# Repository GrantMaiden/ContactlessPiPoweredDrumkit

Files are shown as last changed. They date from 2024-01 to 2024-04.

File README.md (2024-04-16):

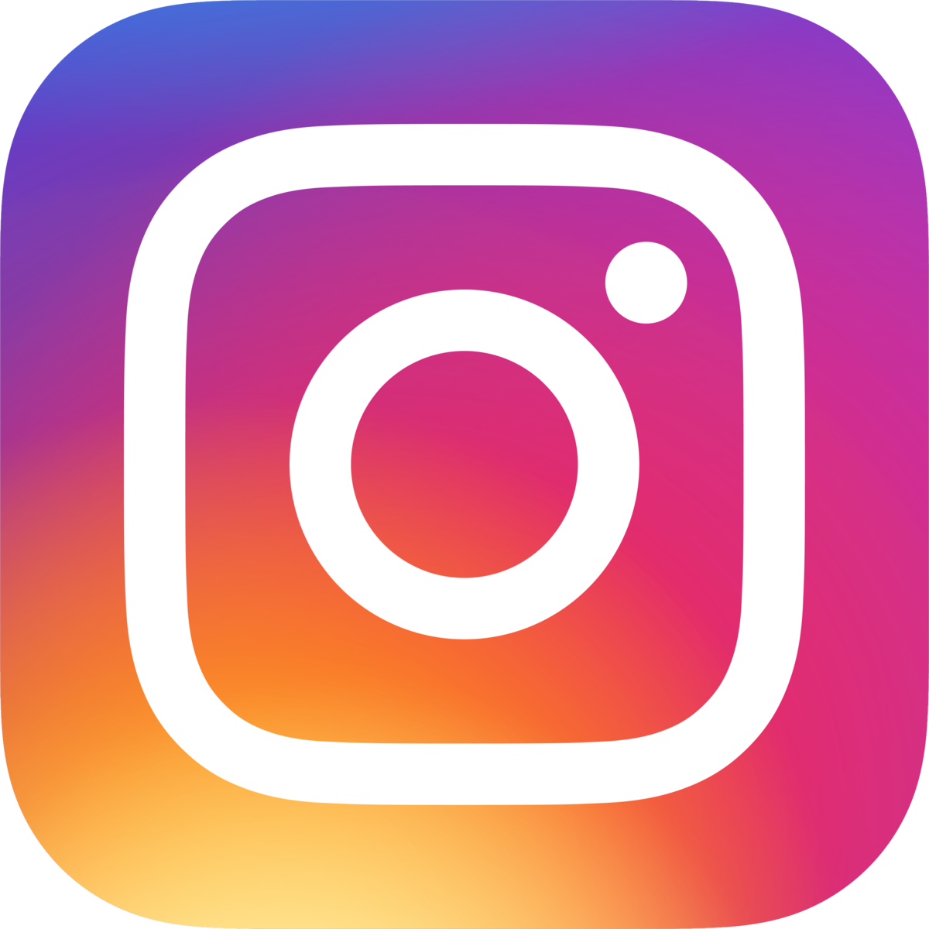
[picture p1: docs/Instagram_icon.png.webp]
# [](https://www.instagram.com/byte.thebeat/) (byte)this.beat  
Welcome to the github landing page for the first prototype of the **(byte)this.beat** drumkit!

(byte)this.beat is an innovative, contactless, raspberry pi-powered drumkit being developed for  Real Time Embedded Programming (ENG5220) at the University of Glasgow.  The contactless drumkit aims to be a simple, easy-to-use interface that accommodates entry level users---being a introductory device to jam out on---as well as a device for professional musicians, conforming to sub 20ms latency requirements and high quality, 48000khz drum samples.

Please download the latest release to access the most recent stable version of the source code. Keep in mind that hardware is required to run this project!

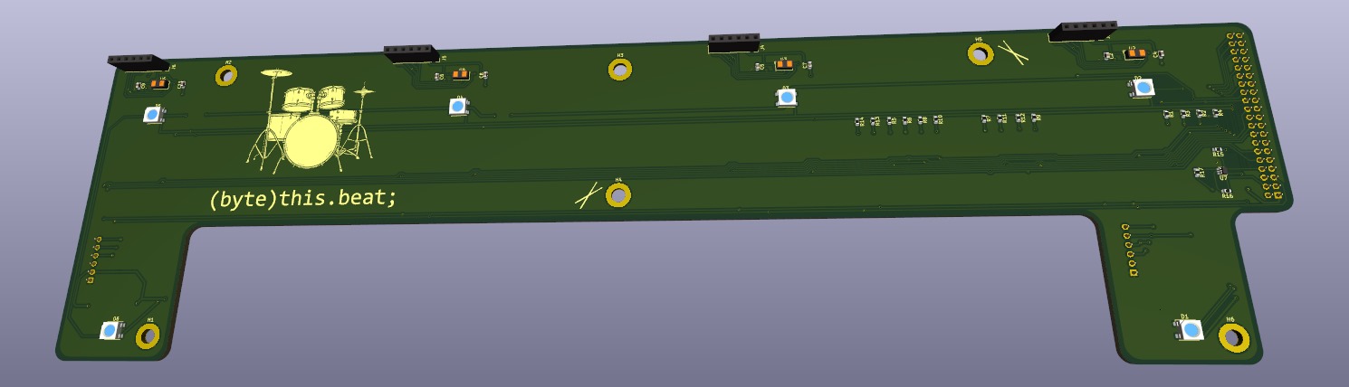
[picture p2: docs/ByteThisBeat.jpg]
(byte)this.beat; PCB


## So what's the tempo?

* The challenge set for this course was to develop any real time embedded project, using a Raspberry Pi 3 and a £45 budget.  
* Selecting an appropriate sensor that can be used in a real-time system that is affordable, has a high sample rate, and great data resolution was challenging. After a thorough amount of market research, the [VL53L4CD](https://www.st.com/en/imaging-and-photonics-solutions/vl53l4cd.html) ranging sensor was selected as the most suitable ic for our project. Turning them into "invisible" drum modules so that you can jam out in thin air seemed a perfect task!  
* The distance values measured by the sensors every 10ms are used to calculate the velocity of any objects directly above the sensors. A detection algorithm is derived by being a combination of when the velocity changes direction, and what the previous 80ms of velocity was measured as. Thus, it is possible to use the sensor data to not only detect when a drum hit has been detected, but also at what intensity!

## Team Collaboration and Project Management

Project management was done by utilising a teams channel for collaboration. At the start of our group project, keeping in mind an agile team development environment, a Gantt chart was created in excel and hosted on our teams channel. Our team had two meetings each week throughout the semester; the first of which was primarily for project planning and updates, and the second meeting was for development and one-on-one problem solving, if necessary. Github issues were utilised as a means to give feedback as our project development continued. All Project Discussions, meeting notes, and development feasibility studies can be found at our [sharepoint](https://gla.sharepoint.com/:o:/s/ENG5228RTEP/Er4JzmCRMUZCnUjhNUSQIA8BrX5IVSQI6c456dHyLfZf0w?e=HDqj4z).  
This link is accessible by anyone with a University of Glasgow account. 
GitHub issues were used as a way to track the development of the project. The issues can be viewed from the header of this page, above the directory browser.

## Project Setup and Initialisation
### Hardware Requirements
* Assembled (byte)this.beat board
* Raspberry Pi updated with latest Raspbian image
* Speaker attached to Audio Jack
### Software Setup
* Complete project setup instructions located in the [Embedded Directory](https://github.com/GrantMaiden/ContactlessPiPoweredDrumkit/tree/main/embedded) on your local raspberry pi
* Download the latest release of the firmware, and compile the source code in the embedded directory by following the [cmake build instructions](https://github.com/GrantMaiden/ContactlessPiPoweredDrumkit/blob/main/embedded/cmake_build_instructions.txt)

After running the program, an intro LED pattern will play for roughly 5 seconds, which when complete the drumkit will be able to receive ranging data. To enable sound, swipe across all 4 upwards facing sensors. The same swipe can be used to disable sound if playing needs to be paused.

## Documentation
Our code has been updated with comments that are compatible with DoxyGen, which is a great tool to generate large amounts of sufficiently segmented documentation. To view the generated documentation, first grab the latest release, then open the index.html page located in the [embedded/docs](https://github.com/GrantMaiden/ContactlessPiPoweredDrumkit/tree/main/embedded/docs) directory. In addition to the DoxyGen resource, the source code is litered with verbose explanaitons and function headers, so keep that in mind if you are modifying the source.

## Hardware Development
In order to minimise costs associated with the (byte)this.beat project, a custom Hardware design was developed. After a cost analysis completed at the beginning of the project timeline, it was concluded that designing a custom solution, rather than purchasing independent breakout boards, would allow our contactless drumkit to have a larger scope. Thus accommodating more sensors/functionality by more easily staying within our £45 budget. The discussions pertaining to analysis and cost can be seen at our [onenote](https://gla.sharepoint.com/:o:/s/ENG5228RTEP/Er4JzmCRMUZCnUjhNUSQIA8BrX5IVSQI6c456dHyLfZf0w?e=HDqj4z).  

As always, the goal with any project is to learn as much as possible while designing, thus we decided to use this opportunity to get familiar with KiCad for schematic entry. A prototype design was completed early into the semester, giving our team plenty of tolerance on receiving the fabricated boards. The fabricated board can also easily accommodate many more traces and connections than a breadboard solution could, allowing for the design scope to increase. The schematic can be seen [here](https://github.com/GrantMaiden/ContactlessPiPoweredDrumkit/blob/main/hardware/ContactlessPiPoweredDrumkit/Schematic/byteThisBeatREVA.pdf).

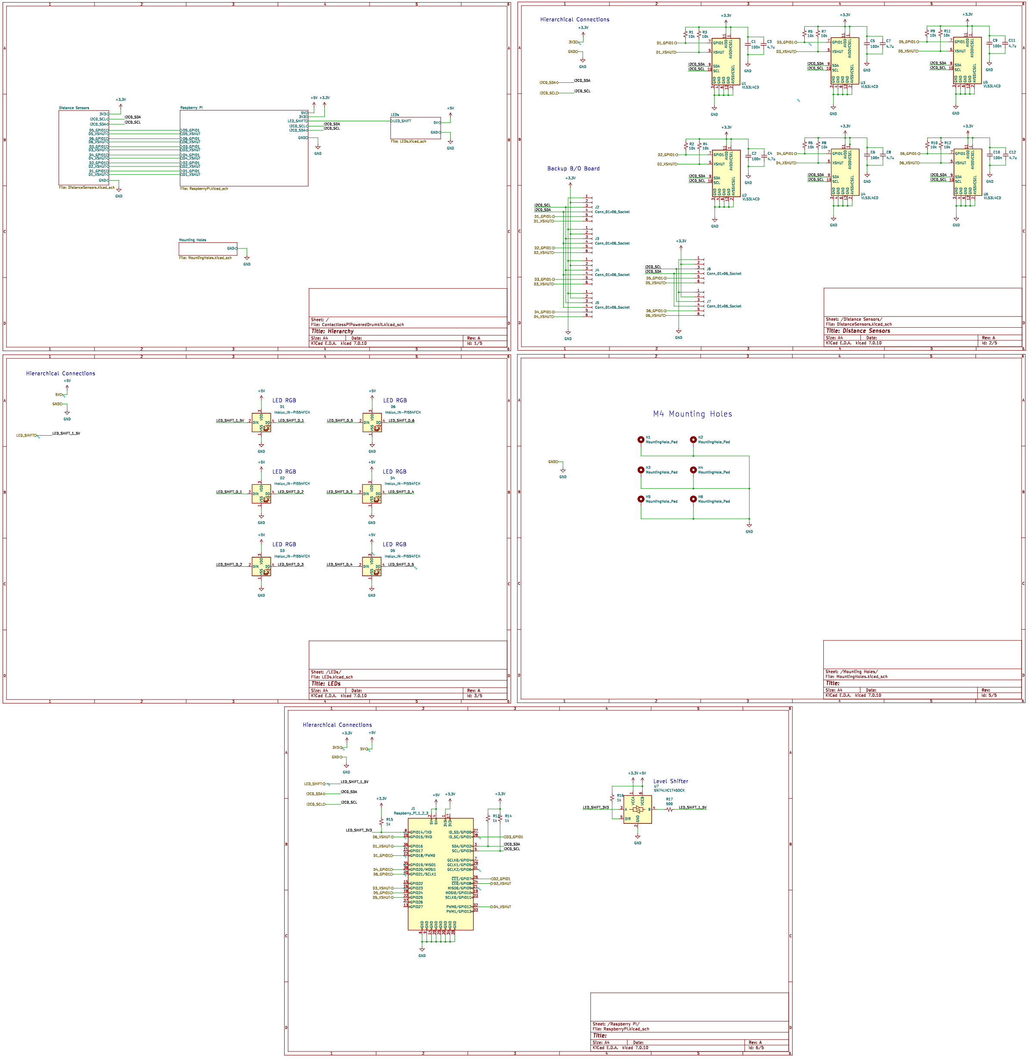
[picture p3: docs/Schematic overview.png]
(byte)this.beat; Schematic overview


The drumkit had a portion of the budget left over after the primary sensor selection, so we decided to use the rest of the funds on purchasing LEDs that would aid in giving the drummer feedback during hit detection. As seen in the block diagram below, the raspberry pi communicates with 6 distance sensors, outputs to the on-board audio jack, and outputs serialised data to the LEDs.

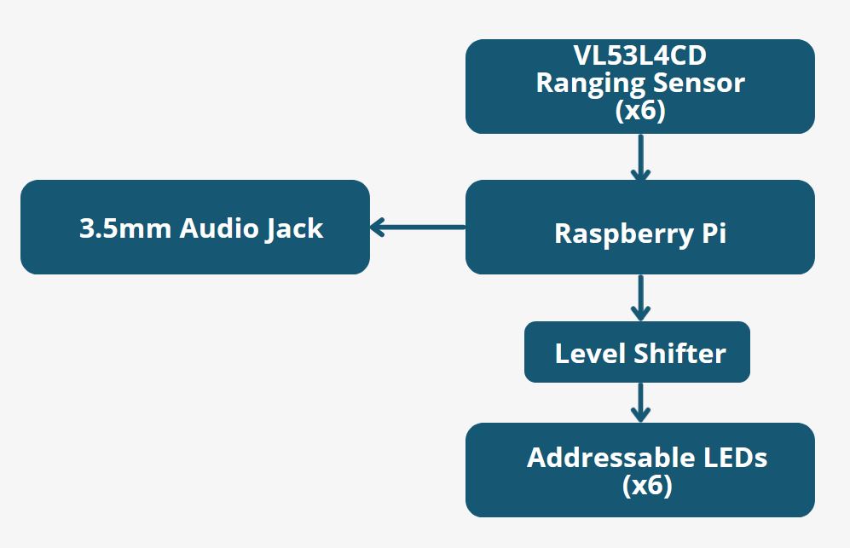
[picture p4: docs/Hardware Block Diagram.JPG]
(byte)this.beat; Hardware Diagram


The LEDs that were chosen are the same type of addressable LEDs that can be found on LED strips. They are affordable, and plenty of options are available. A few design challenges had to be faced regarding the decision to use these leds, however. The LEDs use 5V logic for communication, so a level shifter had to be added to translate the rpi's 3.3V logic to 5V. Secondly, the LEDs use a strict 800khz transmission rate for each bit. Serialised bits need to be given to the LEDs over a single trace, essentially the LEDs act as specialised shift registers, only forwarding their to each succeeding LED after 24bits of data has been received. The data sheet for the LEDs, along with more information regarding the protocol, can be found [here](https://github.com/GrantMaiden/ContactlessPiPoweredDrumkit/blob/main/docs/datasheets/IN-PI55TAT(X)R(X)G(X)B_v1.5.pdf). 

Due to the strict timing requirement of the LEDs, we had to use a hardware bus to send the LED bitstream, given that bitbanging at 800khz would not be consistent, and would cause too much overhead. Initially, the PCB was designed to use the uart interface for driving the LEDs, but after getting the boards in-hand and beginning development, it was found that the uart bus could not support the baudrate required (800khz*(8bits + 1stopbit) = 7.2mhz), a hardware rework was completed to change the LED control over to the SPI bus, which could accommodate the necessary frequency. The rework instructions can be found in the hardware directory.

For more information regarding the manufacturing of the (byte)this.beat board, please refer to the [hardware directory](https://github.com/GrantMaiden/ContactlessPiPoweredDrumkit/tree/main/hardware/ContactlessPiPoweredDrumkit), which includes a BOM for manufacture. The board file can also be seen in this directory. Layout was completed using KiCad, with a two-layer PCB being designed. After meeting with the EE technicians at the University of Glasgow, we found that they were unable to fabricate our design, so an overseas location was chosen for fab and assembly.

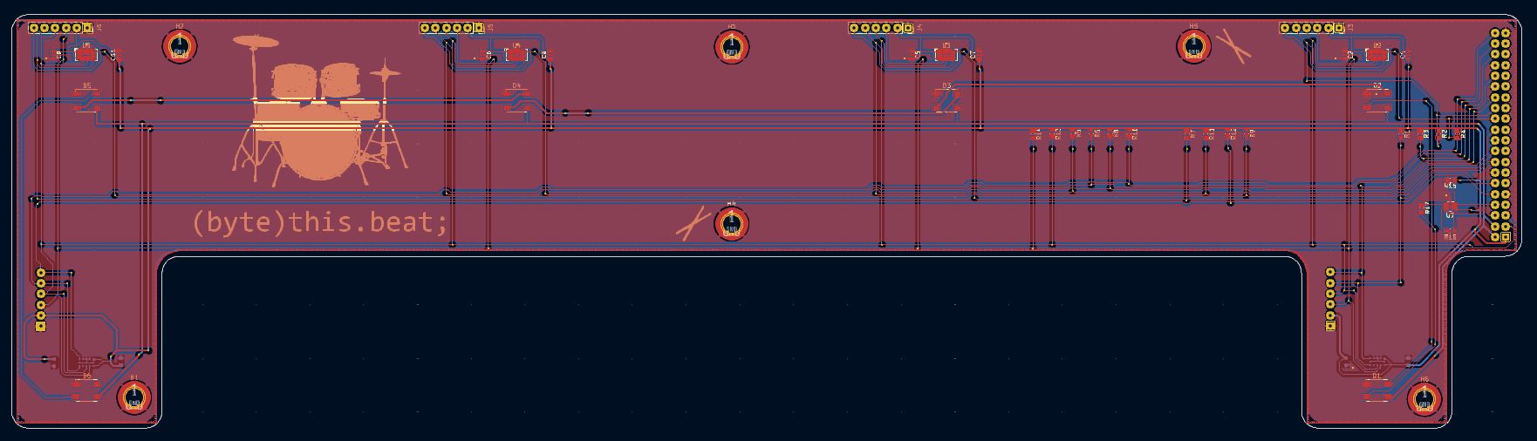
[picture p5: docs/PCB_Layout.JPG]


## Software 

The embedded code, being the main focus of our project, was approached with several goals for implementation:
* Real Time Coding - code is event driven and utilises hardware inputs or timers to strictly control code behavior
* Event Handling - real time events are coded with clearly defined callbacks and other async operations
* Class Encapsulation - code is written within separate classes that have clear responsibilities, obey the Liskov Substitution Principle, and are segregated, with dependency inversion
* Documentation - Verbose function headers and additional documentation generated with Doxygen to supply the user information
* Header File Constants - many constants included to aid in program control and easily modify behavior

Below, please see a diagram regarding how the major classes interact with each other within our application.

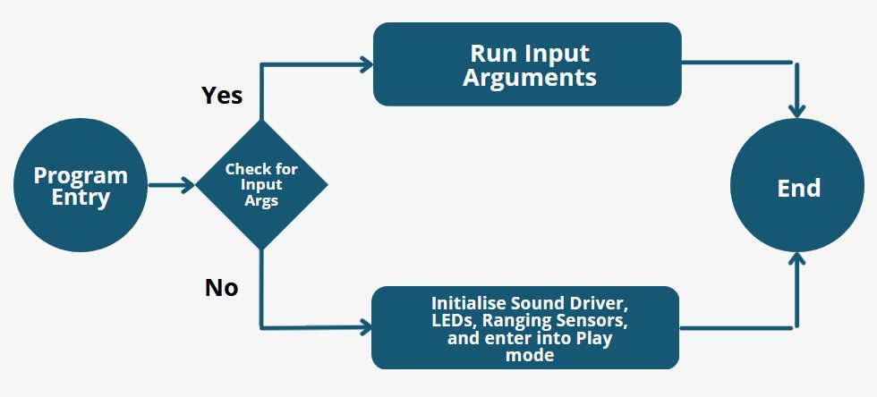
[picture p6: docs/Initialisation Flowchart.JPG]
(byte)this.beat; Init Flowchart


The controller class is initialised by the Main function, which on program boot creates the initial controller class. When the controller class is initialised, it will bring up the other portions of the program, which configures any necessary peripherals, and performs the bring-up procedure of the ranging sensors. This initialisation also configures asynchronous processes that use callback processes to create real-time operation of our system. The LED class uses a timer, and updates all LEDs every 2.5ms. The VL53L4CD class leaves an abstract function that is defined within the Controller class. When a hardware interrupt occurs, the VL53L4CD class will enact a callback via the virtual function.

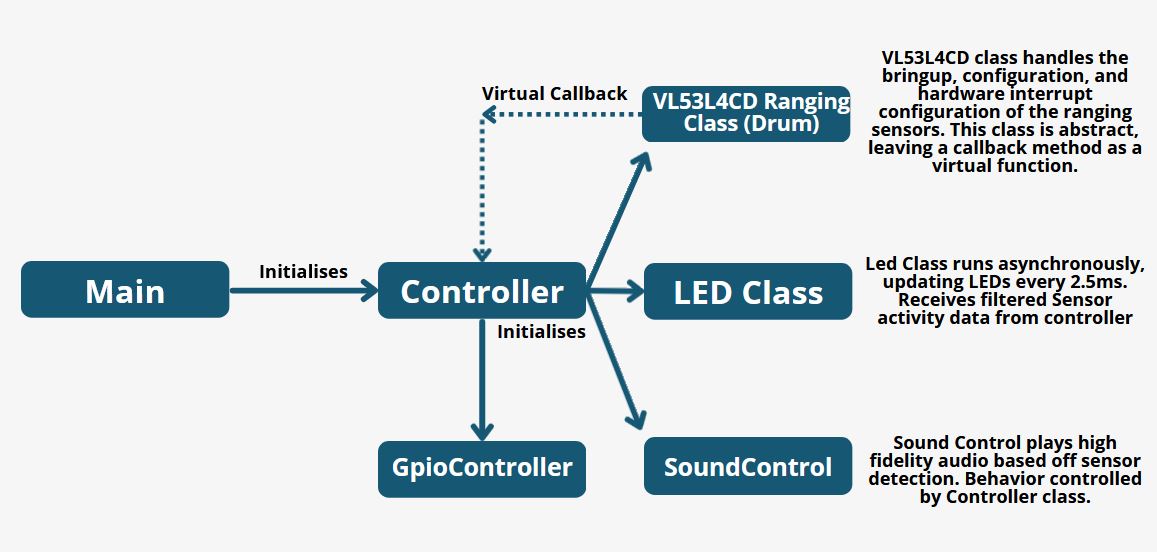
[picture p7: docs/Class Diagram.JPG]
(byte)this.beat; class diagram


### Bus Protocols
I2C was used as the communication protocol for each sensor. All sensors share the same bus, but are initialised with the same address. An initialization procedure had to be crafted to disable all sensors on program start, then bring-up each sensor sequentially, reprogramming the I2C bus address for the sensor, and configuring it for our high sample rate requirements.

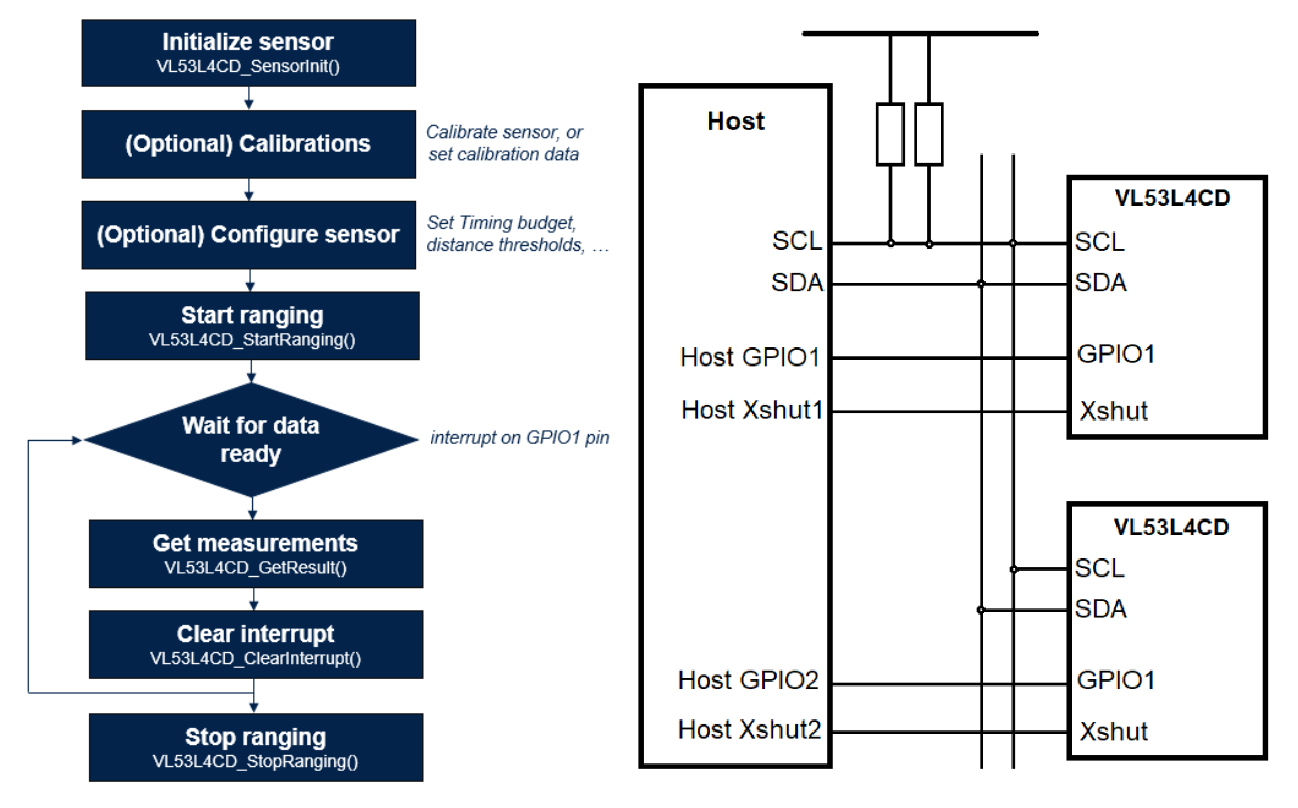
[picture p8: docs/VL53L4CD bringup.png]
(byte)this.beat; ranging bringup

Note: From VL53L4CD Datasheet

The SPI protocol uses custom bitshift operations to drive 6*24bits of RGB data to our addressable LEDs. The GPIO controller class handles the sending of the SPI data.
### Digital Signal Processing
The outgoing data from the ranging sensors is inherently quite noisy, and lots of artifacts exist especially once you begin to interact with them. In order to have reliable air drumming behavior, it was necessary to come up with multiple algorithms that filter the data in various ways. Keeping in mind the real-time requirements of our system, a lengthy finite reponse filter could not be used due to adding to much delay to the total system overhead. To minimise response delays, filtering was controlled using the following methods, configurable inside the controller.h header file:
* HIT_DETECT_NOISE_CHECKING   -- Enable Noise Checking/Filtering
* HIT_DETECT_NUM_SAMPLES_MIN   -- Minimum number of samples necessary for detection
* DRUM_INTERVAL_TIMEOUT_MS  -- Timeout between detection events. Caps maximum drum rate per drum
* HIT_DETECT_INSTANEOUS_VELOCITY_LIMIT  --  Velocity artificats occur frequently. If one of the detection samples' velocity is above this limit, then the drum detect is cancelled
* HIT_DETECT_AVG_VELOCITY_CEILING -- An average velocity is taken of all previous detection samples. If this average is above this threshold, then the drum detect event is negated
* HIT_DETECT_MIN_SEQUENTIAL_VELOCITY_SAMPLES  --  Minimum number of previous velocity samples below the HIT_DETECT_AVG_VELOCITY_CEILING required for a hit detect

Whenever a sensor receives data, via a virtual callback the data is sent to the controller class for processing. The controller class will take the most recent data, store the last 16 distance values into an array, and calculate the most recent velocity by taking the last sample minus the most recent sample. When the velocity calculation occurs, the velocity data is ran through a simple running average filter, via the calculation: averageVelocity = averageVelocity + (recentVelocity - averageVelocity) / VELOCITY_FACTOR_AVG. The VELOCITY_FACTOR_AVG is a constant modifiable in the controller.h header file.
A running average filter allows for a single sample overhead during averaging, and converges completely to the real average within the VELOCITY_FACTOR_AVERAGE number of samples.
As a brief example of the challenges seen during data collection and processing, refer to the below image. This image shows the Average Velocity, Recent Velocity, and current distance of each sample, in 10ms increments. 
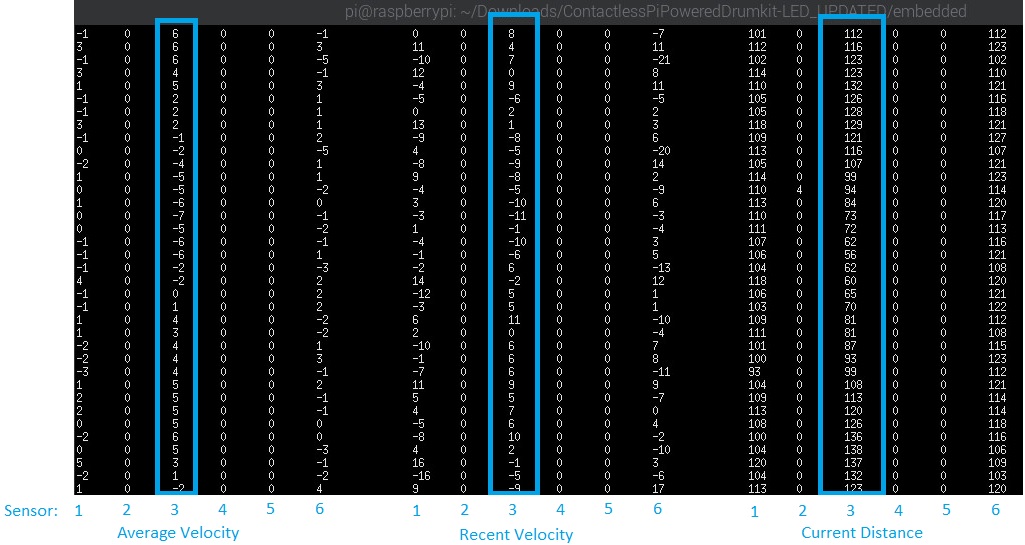
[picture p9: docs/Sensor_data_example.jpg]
(byte)this.beat; sensor data example
 
## Phone Application
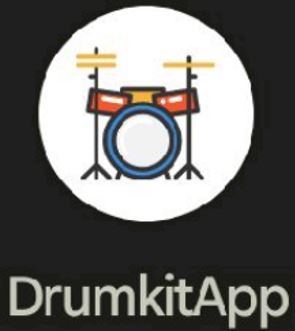
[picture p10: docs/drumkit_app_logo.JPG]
(byte)this.beat; drumkit logo
 
Originally, ambitious project planning had our team plan on utilising a phone application to interact with the physical drumkit, using bluetooth to handshake, modify drumkit selections, and use the phone as a speaker. We did have the opportunity to develop a prototype phone app early on in the semester. However, due to team bandwidth limitations, we were unable to see the bluetooth connectivity and phone app through to completion. 
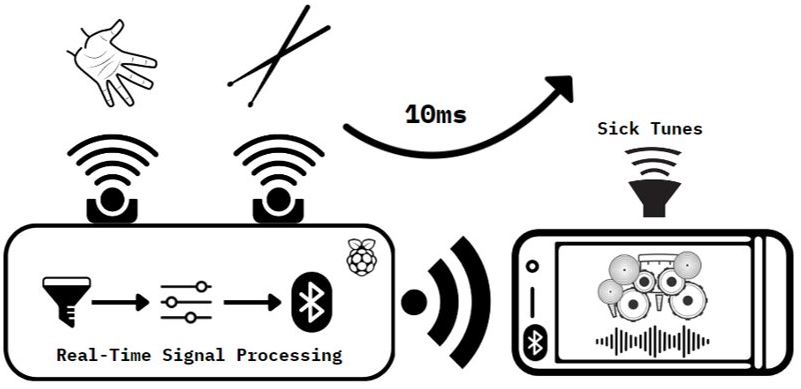
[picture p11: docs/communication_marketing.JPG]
(byte)this.beat; communication
 
It should be noted that we also discovered though substantial literature review that bluetooth bandwidth is relatively inconsistent, and even the bluetooth low latency has minimum latency intervals of about 70ms. We concluded that using bluetooth as a realtime interface would be a nightmare, and it would be best to at least keep to a physical connection regarding the sound output. We still think that a phone app would be a great way to interact with the drumkit settings, volume, etc., any we plan to continue to consider implementing one in the future.
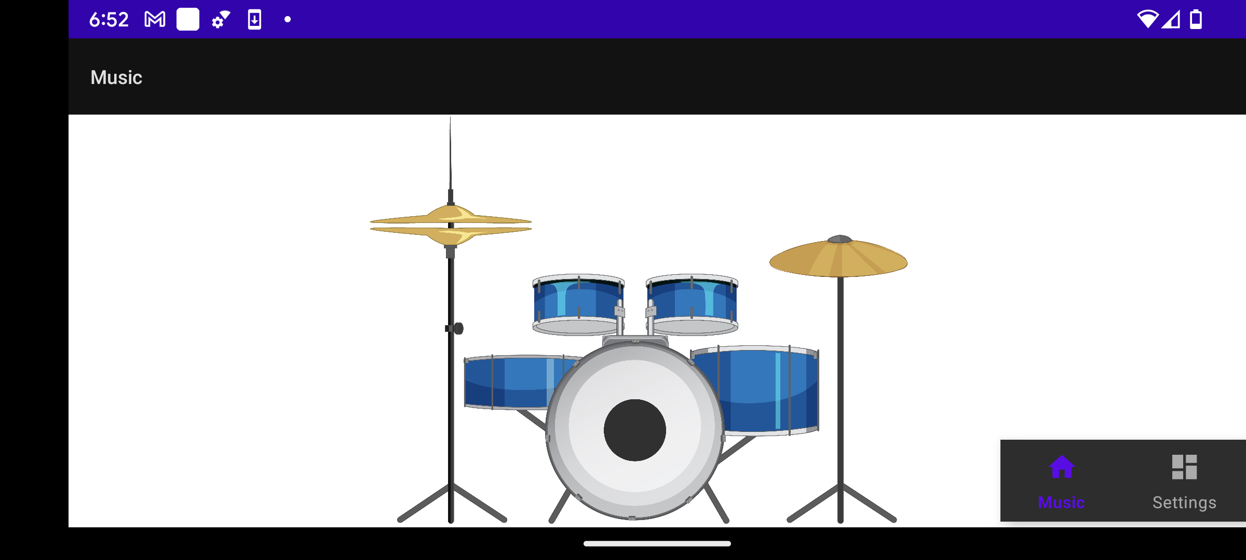
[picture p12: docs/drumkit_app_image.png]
(byte)this.beat; app image
 

## Unit Testing Framework
A custom unit testing framework was designed to accommodate the needs of our team collaborative efforts. When the application launches, the first code that is ran is a search to see if any input arguments are supplied. The input arguments are the inputs to our custom unit testing framework; it was deemed necessary to have a more advanced testing methodology in place as the many different blocks of our project required separate entry points depending on use case. In example, a unit test was designed to benchmark and initialise the LEDs. After the unit test was completed, the functions designed during test were integrated into the rest of the project. This design methodology was enacted in all facets of our software development. 

A list of all unit tests, their associated functions, and more specific usage instructions can be found [here](https://github.com/GrantMaiden/ContactlessPiPoweredDrumkit/blob/main/embedded/unit_tests.txt).

## Challenges and Future Improvements
Development using the raspberry pi proved to be full of challenges. Some of our team has had extensive experience with varying microcontrollers as a professional embedded engineer, and they concluded that the lack of substantial official documentation greatly complicated development. 
Here is a list of (just a few!) of the notable challenges that arose during development:
* Audio permissions -- The pigpio library requires sudo permissions, however the asla audio driver is not configured correctly to run under super user. The solution was challenging to discover, but is highlighted in the markup in our embedded directory.
* SPI bus frequency -- The embedded core clock used by the PI is not consistent. Our addressable LEDs requires fixed timing to work correctly, however the SPI clock is affected by other bus activity, USB traffic, and high load wifi connections. Essenstially, the LEDs will flicker or flash random colors when the SPI frequency deviates. As far as we know, there is no solution to this problem, but it shows that the raspberry pi is full of undocumented surprises, and is not capable of specific timing control under some circumstances.
* Some low level c libraries such as pigpio have functions to modify embedded bus behaviour, but really these values are controlled by the us and it is necessary to modify the /boot/firmware/config.txt to change things such as the I2C clock speed.
* The SPI cs gpio's can not be used as GPIO's during spi, even if SPI0 is being used, and SPI1 CS is trying to be configured as an input, even when all documentation says otherwise. This required a rework!

Some future improvements for the drumkit are planned for the next revision of the project.

* Move away from the high power, large raspberry pi to a smaller mcu. Originally one of the goals of our project was to make a device small and portable; a criteria that our device doesn't quite meet.
* Implement bluetooth communication that will interact with a peripheral phone app for control and feedback.
* Respin the board to correct hardware reworks required to accomodate SPI CS GPIO bottlenecking, and switching to the SPI from UART for LED control.
* Improve hit detection by exploring other filtering methods, and perhaps different sensors.

## Authors

* Grant Maiden  
* Peter O'Hanlon  
* Ethan Travers  
* Lucas Zehner

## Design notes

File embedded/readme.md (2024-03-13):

# Directory for Embedded development  
  
!!!IMPORTANT! PLEASE READ ENTIRETY OF THIS README BEFORE PROCEEDING WITH RUNNING PROJECT!!!  
  
## Important Documents  
  
For Cmake build instructions, refer to [cmake_build_instructions.txt]("./embedded/cmake_build_instructions.txt")  
For Unit Test Parameters, refer to [unit_tests.txt]("./embedded/unit_tests.txt")  
Before proceeding, make sure to complete build setup, otherwise compilation will not be successful.  
  
### Running Instructions:  
After building, preceed all program calls with _sudo_, as pigpio lib requires sudo access.  
  
## Project Setup  
  
Recommended Operating System for compilation: [Bookworm 12, v6.1](https://downloads.raspberrypi.com/raspios_full_armhf/images/raspios_full_armhf-2023-12-06/2023-12-05-raspios-bookworm-armhf-full.img.xz) (auto-download image)  
  
### Project is managed using codeblocks.  
To install codeblocks, run the following from console:  
```
sudo apt-get install codeblocks  
```  
### Enable I2C/SPI communication:  
Pi Grenade Bomb -> Preferences -> Raspberry Pi Configuration -> Interfaces -> I2C (Toggle)  
Pi Grenade Bomb -> Preferences -> Raspberry Pi Configuration -> Interfaces -> SPI (Toggle)  
  
### Edit Config.txt:  
```
sudo nano /boot/firmware/config.txt
``` 
Add Lines:  
```
core_freq=250  
core_freq_min=250  
dtparam=i2c_baudrate=400000  
```  
### Setup Audio by changing user default audio device:  
```
$sudo nano /usr/share/alsa/alsa.conf
```
Change lines:
```
defaults.pcm.card 1  
defaults.ctl.card 1  
```
### PiGPIO
[pigpio download](https://abyz.me.uk/rpi/pigpio/download.html)  
  
To close lingering pigpio processes:  
```
$cat /var/run/pigpio.pid  
$NumberReturned   
$sudo kill -9 NumberReturned
```
  
### Setup Codeblocks:  
Settings-> Compiler -> Linker Settings -> Other linker options -> add to field: -lpigpio -lrt -lpthread -lm -ldl -latomic  
  
### Add Tool Codeblocks:  
Tools -> Configure Tools -> Add -> Name field: Run as Sudo -> Executable Field: sudo $(TARGET_OUTPUT_FILE)   
**NOTE: MUST BUILD THEN TO RUN SELECT THIS TOOL FROM TOOL MENU**  
  
## Resources and Tools
  
Self Documenting Code Format: [DoxyGen](https://www.doxygen.nl/manual/docblocks.html)    
  
[Kernel Documentation](https://www.kernel.org/doc/Documentation/)  
  
Sys Libraries location:  
```
/usr/include/arm-linux-gnueabihf/sys
```

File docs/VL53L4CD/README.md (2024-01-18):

STM32 resources:

Linux driver:
https://www.st.com/en/embedded-software/stsw-img028.html

Product Page:
https://www.st.com/en/imaging-and-photonics-solutions/vl53l4cd.html

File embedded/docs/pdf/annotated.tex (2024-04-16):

\doxysubsection{Class List}
Here are the classes, structs, unions and interfaces with brief descriptions\+:\begin{DoxyCompactList}
\item\contentsline{section}{\mbox{\hyperlink{classController}{Controller}} }{\pageref{classController}}{}
\item\contentsline{section}{\mbox{\hyperlink{classCppThread}{Cpp\+Thread}} }{\pageref{classCppThread}}{}
\item\contentsline{section}{\mbox{\hyperlink{classCppTimer}{Cpp\+Timer}} }{\pageref{classCppTimer}}{}
\item\contentsline{section}{\mbox{\hyperlink{classGpioController}{Gpio\+Controller}} }{\pageref{classGpioController}}{}
\item\contentsline{section}{\mbox{\hyperlink{classLedControl}{Led\+Control}} }{\pageref{classLedControl}}{}
\item\contentsline{section}{\mbox{\hyperlink{classPlatformVL53l4CD}{Platform\+VL53l4\+CD}} \\*If the macro below is defined, the device will be programmed to run with I2C Fast Mode Plus (up to 1MHz). Otherwise, default max value is 400k\+Hz }{\pageref{classPlatformVL53l4CD}}{}
\item\contentsline{section}{\mbox{\hyperlink{structsensorHit}{sensor\+Hit}} }{\pageref{structsensorHit}}{}
\item\contentsline{section}{\mbox{\hyperlink{structsensorValues}{sensor\+Values}} }{\pageref{structsensorValues}}{}
\item\contentsline{section}{\mbox{\hyperlink{classSound}{Sound}} }{\pageref{classSound}}{}
\item\contentsline{section}{\mbox{\hyperlink{classVL53L4CD}{VL53\+L4\+CD}} }{\pageref{classVL53L4CD}}{}
\item\contentsline{section}{\mbox{\hyperlink{classVL53L4CD__API}{VL53\+L4\+CD\+\_\+\+API}} }{\pageref{classVL53L4CD__API}}{}
\item\contentsline{section}{\mbox{\hyperlink{structVL53L4CD__LinuxDev}{VL53\+L4\+CD\+\_\+\+Linux\+Dev}} }{\pageref{structVL53L4CD__LinuxDev}}{}
\item\contentsline{section}{\mbox{\hyperlink{structVL53L4CD__ResultsData__t}{VL53\+L4\+CD\+\_\+\+Results\+Data\+\_\+t}} \\*Packed reading results type }{\pageref{structVL53L4CD__ResultsData__t}}{}
\item\contentsline{section}{\mbox{\hyperlink{structVL53L4CD__Version__t}{VL53\+L4\+CD\+\_\+\+Version\+\_\+t}} \\*Defines Software Version }{\pageref{structVL53L4CD__Version__t}}{}
\end{DoxyCompactList}

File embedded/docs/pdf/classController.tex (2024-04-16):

\hypertarget{classController}{}\doxysubsection{Controller Class Reference}
\label{classController}\index{Controller@{Controller}}
Inheritance diagram for Controller\+:\begin{figure}[H]
\begin{center}
\leavevmode

\end{center}
\end{figure}
\doxysubsubsection*{Public Member Functions}
\begin{DoxyCompactItemize}
\item 
virtual void \mbox{\hyperlink{classController_af53bfa42e907627e5f39668e3d8acb5c}{distance\+Data\+Ready}} (\mbox{\hyperlink{structsensorValues}{sensor\+Values}} sens\+Vals, sensor\+ID sensor)
\item 
void \mbox{\hyperlink{classController_a28d5755bc8fed07cebd88f857f0f83df}{initialize}} ()
\item 
void \mbox{\hyperlink{classController_adddce8023c6beb72400ec1ead2629e66}{primary\+State\+Machine}} ()
\item 
void \mbox{\hyperlink{classController_a0676fa7d920a0984d3920bcf27401a0f}{update\+State}} (controller\+State new\+State)
\item 
void \mbox{\hyperlink{classController_a6a4dff110a9530bb905f0b7fab9bd819}{update\+Sensor\+Value}} (\mbox{\hyperlink{structsensorValues}{sensor\+Values}} sense\+Value, sensor\+ID id)
\end{DoxyCompactItemize}

\doxysubsubsection{Member Function Documentation}
\mbox{\Hypertarget{classController_af53bfa42e907627e5f39668e3d8acb5c}\label{classController_af53bfa42e907627e5f39668e3d8acb5c}} 
\index{Controller@{Controller}!distanceDataReady@{distanceDataReady}}
\index{distanceDataReady@{distanceDataReady}!Controller@{Controller}}
\doxyparagraph{\texorpdfstring{distanceDataReady()}{distanceDataReady()}}
{\footnotesize\ttfamily virtual void Controller\+::distance\+Data\+Ready (\begin{DoxyParamCaption}\item[{\mbox{\hyperlink{structsensorValues}{sensor\+Values}}}]{sens\+Vals,  }\item[{sensor\+ID}]{sensor }\end{DoxyParamCaption})\hspace{0.3cm}{\ttfamily [inline]}, {\ttfamily [virtual]}}

Called when new Distance sensor data has been recieved. This needs to be implemented in a derived class by the client. Defined as abstract. 
\begin{DoxyParams}{Parameters}
{\em sens\+Vals} & -\/ sense\+Vals structure that contains sensor data \\
\hline
{\em sensor} & -\/ Sensor\+ID signifying which sensor data is coming from \\
\hline
\end{DoxyParams}

Implements \mbox{\hyperlink{classVL53L4CD_a149a2250aabe18254a50be683b9fbba5}{VL53\+L4\+CD}}.

\mbox{\Hypertarget{classController_a28d5755bc8fed07cebd88f857f0f83df}\label{classController_a28d5755bc8fed07cebd88f857f0f83df}} 
\index{Controller@{Controller}!initialize@{initialize}}
\index{initialize@{initialize}!Controller@{Controller}}
\doxyparagraph{\texorpdfstring{initialize()}{initialize()}}
{\footnotesize\ttfamily void Controller\+::initialize (\begin{DoxyParamCaption}{ }\end{DoxyParamCaption})}

initialize controller globals and states \mbox{\Hypertarget{classController_adddce8023c6beb72400ec1ead2629e66}\label{classController_adddce8023c6beb72400ec1ead2629e66}} 
\index{Controller@{Controller}!primaryStateMachine@{primaryStateMachine}}
\index{primaryStateMachine@{primaryStateMachine}!Controller@{Controller}}
\doxyparagraph{\texorpdfstring{primaryStateMachine()}{primaryStateMachine()}}
{\footnotesize\ttfamily void Controller\+::primary\+State\+Machine (\begin{DoxyParamCaption}{ }\end{DoxyParamCaption})}

\mbox{\hyperlink{classController}{Controller}} State Machine. Handles all system states, inputs, and outputs. \mbox{\Hypertarget{classController_a6a4dff110a9530bb905f0b7fab9bd819}\label{classController_a6a4dff110a9530bb905f0b7fab9bd819}} 
\index{Controller@{Controller}!updateSensorValue@{updateSensorValue}}
\index{updateSensorValue@{updateSensorValue}!Controller@{Controller}}
\doxyparagraph{\texorpdfstring{updateSensorValue()}{updateSensorValue()}}
{\footnotesize\ttfamily void Controller\+::update\+Sensor\+Value (\begin{DoxyParamCaption}\item[{\mbox{\hyperlink{structsensorValues}{sensor\+Values}}}]{sense\+Value,  }\item[{sensor\+ID}]{id }\end{DoxyParamCaption})}

updates sensor value 
\begin{DoxyParams}{Parameters}
{\em sense\+Value-\/} & \mbox{\hyperlink{structsensorValues}{sensor\+Values}} struct \\
\hline
{\em sense\+ID-\/} & id of current sensor \\
\hline
\end{DoxyParams}
\mbox{\Hypertarget{classController_a0676fa7d920a0984d3920bcf27401a0f}\label{classController_a0676fa7d920a0984d3920bcf27401a0f}} 
\index{Controller@{Controller}!updateState@{updateState}}
\index{updateState@{updateState}!Controller@{Controller}}
\doxyparagraph{\texorpdfstring{updateState()}{updateState()}}
{\footnotesize\ttfamily void Controller\+::update\+State (\begin{DoxyParamCaption}\item[{controller\+State}]{new\+State }\end{DoxyParamCaption})}

update controller state 

The documentation for this class was generated from the following file\+:\begin{DoxyCompactItemize}
\item 
include/controller.\+h\end{DoxyCompactItemize}

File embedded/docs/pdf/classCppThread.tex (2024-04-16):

\hypertarget{classCppThread}{}\doxysubsection{Cpp\+Thread Class Reference}
\label{classCppThread}\index{CppThread@{CppThread}}

{\ttfamily \#include $<$Cpp\+Thread.\+h$>$}

\doxysubsubsection*{Public Member Functions}
\begin{DoxyCompactItemize}
\item 
void \mbox{\hyperlink{classCppThread_a1be46d1be000f41a763289300623c609}{start}} ()
\item 
void \mbox{\hyperlink{classCppThread_a8ff0fda6b913cc53764caef0e1200f3f}{join}} ()
\end{DoxyCompactItemize}
\doxysubsubsection*{Protected Member Functions}
\begin{DoxyCompactItemize}
\item 
virtual void \mbox{\hyperlink{classCppThread_a792b79e72250710147c452648def4a78}{run}} ()=0
\end{DoxyCompactItemize}

\doxysubsubsection{Detailed Description}
GNU GENERAL PUBLIC LICENSE Version 3, 29 June 2007

(C) 2020-\/2022, Bernd Porr \href{mailto:mail@bernporr.me.uk}{\texttt{ mail@bernporr.\+me.\+uk}} A thin wrapper around the C++ thread model to avoid a static callback. Instead just inherit this class and overload \mbox{\hyperlink{classCppThread_a792b79e72250710147c452648def4a78}{run()}} which then runs in this thread. This is header-\/only so that it can be performed inline for max performance. 

\doxysubsubsection{Member Function Documentation}
\mbox{\Hypertarget{classCppThread_a8ff0fda6b913cc53764caef0e1200f3f}\label{classCppThread_a8ff0fda6b913cc53764caef0e1200f3f}} 
\index{CppThread@{CppThread}!join@{join}}
\index{join@{join}!CppThread@{CppThread}}
\doxyparagraph{\texorpdfstring{join()}{join()}}
{\footnotesize\ttfamily void Cpp\+Thread\+::join (\begin{DoxyParamCaption}{ }\end{DoxyParamCaption})\hspace{0.3cm}{\ttfamily [inline]}}

Waits for the thread to terminate. \mbox{\Hypertarget{classCppThread_a792b79e72250710147c452648def4a78}\label{classCppThread_a792b79e72250710147c452648def4a78}} 
\index{CppThread@{CppThread}!run@{run}}
\index{run@{run}!CppThread@{CppThread}}
\doxyparagraph{\texorpdfstring{run()}{run()}}
{\footnotesize\ttfamily virtual void Cpp\+Thread\+::run (\begin{DoxyParamCaption}{ }\end{DoxyParamCaption})\hspace{0.3cm}{\ttfamily [protected]}, {\ttfamily [pure virtual]}}

This method does all the work of this thread. Overload this abstract function with a real one doing the actual work of this thread. \mbox{\Hypertarget{classCppThread_a1be46d1be000f41a763289300623c609}\label{classCppThread_a1be46d1be000f41a763289300623c609}} 
\index{CppThread@{CppThread}!start@{start}}
\index{start@{start}!CppThread@{CppThread}}
\doxyparagraph{\texorpdfstring{start()}{start()}}
{\footnotesize\ttfamily void Cpp\+Thread\+::start (\begin{DoxyParamCaption}{ }\end{DoxyParamCaption})\hspace{0.3cm}{\ttfamily [inline]}}

Starts the thread. 

The documentation for this class was generated from the following file\+:\begin{DoxyCompactItemize}
\item 
include/Cpp\+Thread.\+h\end{DoxyCompactItemize}

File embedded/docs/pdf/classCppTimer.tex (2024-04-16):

\hypertarget{classCppTimer}{}\doxysubsection{Cpp\+Timer Class Reference}
\label{classCppTimer}\index{CppTimer@{CppTimer}}

{\ttfamily \#include $<$Cpp\+Timer.\+h$>$}

Inheritance diagram for Cpp\+Timer\+:\begin{figure}[H]
\begin{center}
\leavevmode

\end{center}
\end{figure}
\doxysubsubsection*{Public Member Functions}
\begin{DoxyCompactItemize}
\item 
virtual void \mbox{\hyperlink{classCppTimer_a7de6bd2c8c9b5daa70d5c3d9b97fa49b}{startns}} (long nanosecs, cpp\+Timer\+Type\+\_\+t type=PERIODIC)
\item 
virtual void \mbox{\hyperlink{classCppTimer_a8054cc8cead2e360b06b6ff99cc964cf}{startms}} (long millisecs, cpp\+Timer\+Type\+\_\+t type=PERIODIC)
\item 
virtual void \mbox{\hyperlink{classCppTimer_aafb86e2bb43311bf154867dd6da43e80}{stop}} ()
\item 
virtual \mbox{\hyperlink{classCppTimer_a2942aab831713273a76218048fe61b16}{$\sim$\+Cpp\+Timer}} ()
\end{DoxyCompactItemize}
\doxysubsubsection*{Protected Member Functions}
\begin{DoxyCompactItemize}
\item 
virtual void \mbox{\hyperlink{classCppTimer_ac2665403595b6aee5f581d0ebfeb886c}{timer\+Event}} ()=0
\end{DoxyCompactItemize}

\doxysubsubsection{Detailed Description}
Timer class which repeatedly fires. It\textquotesingle{}s wrapper around the POSIX per-\/process timer. 

\doxysubsubsection{Constructor \& Destructor Documentation}
\mbox{\Hypertarget{classCppTimer_a2942aab831713273a76218048fe61b16}\label{classCppTimer_a2942aab831713273a76218048fe61b16}} 
\index{CppTimer@{CppTimer}!````~CppTimer@{$\sim$CppTimer}}
\index{````~CppTimer@{$\sim$CppTimer}!CppTimer@{CppTimer}}
\doxyparagraph{\texorpdfstring{$\sim$CppTimer()}{~CppTimer()}}
{\footnotesize\ttfamily virtual Cpp\+Timer\+::$\sim$\+Cpp\+Timer (\begin{DoxyParamCaption}{ }\end{DoxyParamCaption})\hspace{0.3cm}{\ttfamily [inline]}, {\ttfamily [virtual]}}

Destructor disarms the timer, deletes it and disconnect the signal handler. 

\doxysubsubsection{Member Function Documentation}
\mbox{\Hypertarget{classCppTimer_a8054cc8cead2e360b06b6ff99cc964cf}\label{classCppTimer_a8054cc8cead2e360b06b6ff99cc964cf}} 
\index{CppTimer@{CppTimer}!startms@{startms}}
\index{startms@{startms}!CppTimer@{CppTimer}}
\doxyparagraph{\texorpdfstring{startms()}{startms()}}
{\footnotesize\ttfamily virtual void Cpp\+Timer\+::startms (\begin{DoxyParamCaption}\item[{long}]{millisecs,  }\item[{cpp\+Timer\+Type\+\_\+t}]{type = {\ttfamily PERIODIC} }\end{DoxyParamCaption})\hspace{0.3cm}{\ttfamily [inline]}, {\ttfamily [virtual]}}

Starts the timer. The timer fires first after the specified time in milliseconds and then at that interval in PERIODIC mode. In ONESHOT mode the timer fires once after the specified time in milliseconds. 
\begin{DoxyParams}{Parameters}
{\em millisecs} & Time in milliseconds \\
\hline
{\em type} & Either PERIODIC or ONESHOT \\
\hline
\end{DoxyParams}
\mbox{\Hypertarget{classCppTimer_a7de6bd2c8c9b5daa70d5c3d9b97fa49b}\label{classCppTimer_a7de6bd2c8c9b5daa70d5c3d9b97fa49b}} 
\index{CppTimer@{CppTimer}!startns@{startns}}
\index{startns@{startns}!CppTimer@{CppTimer}}
\doxyparagraph{\texorpdfstring{startns()}{startns()}}
{\footnotesize\ttfamily virtual void Cpp\+Timer\+::startns (\begin{DoxyParamCaption}\item[{long}]{nanosecs,  }\item[{cpp\+Timer\+Type\+\_\+t}]{type = {\ttfamily PERIODIC} }\end{DoxyParamCaption})\hspace{0.3cm}{\ttfamily [inline]}, {\ttfamily [virtual]}}

Starts the timer. The timer fires first after the specified time in nanoseconds and then at that interval in PERIODIC mode. In ONESHOT mode the timer fires once after the specified time in nanoseconds. 
\begin{DoxyParams}{Parameters}
{\em nanosecs} & Time in nanoseconds \\
\hline
{\em type} & Either PERIODIC or ONESHOT \\
\hline
\end{DoxyParams}
\mbox{\Hypertarget{classCppTimer_aafb86e2bb43311bf154867dd6da43e80}\label{classCppTimer_aafb86e2bb43311bf154867dd6da43e80}} 
\index{CppTimer@{CppTimer}!stop@{stop}}
\index{stop@{stop}!CppTimer@{CppTimer}}
\doxyparagraph{\texorpdfstring{stop()}{stop()}}
{\footnotesize\ttfamily virtual void Cpp\+Timer\+::stop (\begin{DoxyParamCaption}{ }\end{DoxyParamCaption})\hspace{0.3cm}{\ttfamily [inline]}, {\ttfamily [virtual]}}

Stops the timer by disarming it. It can be re-\/started with start(). \mbox{\Hypertarget{classCppTimer_ac2665403595b6aee5f581d0ebfeb886c}\label{classCppTimer_ac2665403595b6aee5f581d0ebfeb886c}} 
\index{CppTimer@{CppTimer}!timerEvent@{timerEvent}}
\index{timerEvent@{timerEvent}!CppTimer@{CppTimer}}
\doxyparagraph{\texorpdfstring{timerEvent()}{timerEvent()}}
{\footnotesize\ttfamily virtual void Cpp\+Timer\+::timer\+Event (\begin{DoxyParamCaption}{ }\end{DoxyParamCaption})\hspace{0.3cm}{\ttfamily [protected]}, {\ttfamily [pure virtual]}}

Abstract function which needs to be implemented by the children. This is called every time the timer fires. 

The documentation for this class was generated from the following file\+:\begin{DoxyCompactItemize}
\item 
include/Cpp\+Timer.\+h\end{DoxyCompactItemize}

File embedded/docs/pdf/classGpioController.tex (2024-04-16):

\hypertarget{classGpioController}{}\doxysubsection{Gpio\+Controller Class Reference}
\label{classGpioController}\index{GpioController@{GpioController}}
\doxysubsubsection*{Public Member Functions}
\begin{DoxyCompactItemize}
\item 
bool \mbox{\hyperlink{classGpioController_aafdd41c8976402d25e1bf8db55819222}{gpio\+Test}} (uint seconds)
\item 
int \mbox{\hyperlink{classGpioController_a4ffca3bcc79d2c4ad74e9c02dfe68950}{gpio\+Initialize\+Lib}} (void)
\item 
int \mbox{\hyperlink{classGpioController_a63da553df056aa124d06cacd27faf484}{gpio\+Set\+Output}} (int GPIOnumber, int logic\+Level)
\item 
bool \mbox{\hyperlink{classGpioController_aaf9f9b913c9312b1fb88b6d5d72e682b}{led\+Nop\+Asm\+Test}} (uint seconds)
\item 
bool \mbox{\hyperlink{classGpioController_ad8bbb818ca48b2535adaaf51908f7a4a}{gpio\+Led\+Spi\+Test}} (char $\ast$arr)
\item 
void \mbox{\hyperlink{classGpioController_a0d89c3d7bc51ffea975d7af5da28c798}{gpio\+Led\+Set\+Color}} (char $\ast$arr)
\end{DoxyCompactItemize}

\doxysubsubsection{Member Function Documentation}
\mbox{\Hypertarget{classGpioController_a4ffca3bcc79d2c4ad74e9c02dfe68950}\label{classGpioController_a4ffca3bcc79d2c4ad74e9c02dfe68950}} 
\index{GpioController@{GpioController}!gpioInitializeLib@{gpioInitializeLib}}
\index{gpioInitializeLib@{gpioInitializeLib}!GpioController@{GpioController}}
\doxyparagraph{\texorpdfstring{gpioInitializeLib()}{gpioInitializeLib()}}
{\footnotesize\ttfamily int Gpio\+Controller\+::gpio\+Initialize\+Lib (\begin{DoxyParamCaption}\item[{void}]{ }\end{DoxyParamCaption})}

initialize Pi\+Gpio Library \begin{DoxyReturn}{Returns}
int-\/ Pi\+Gpio library version 
\end{DoxyReturn}
\mbox{\Hypertarget{classGpioController_a0d89c3d7bc51ffea975d7af5da28c798}\label{classGpioController_a0d89c3d7bc51ffea975d7af5da28c798}} 
\index{GpioController@{GpioController}!gpioLedSetColor@{gpioLedSetColor}}
\index{gpioLedSetColor@{gpioLedSetColor}!GpioController@{GpioController}}
\doxyparagraph{\texorpdfstring{gpioLedSetColor()}{gpioLedSetColor()}}
{\footnotesize\ttfamily void Gpio\+Controller\+::gpio\+Led\+Set\+Color (\begin{DoxyParamCaption}\item[{char $\ast$}]{arr }\end{DoxyParamCaption})}

Sets Led Color Array to input 144bits (18bytes). Led\texorpdfstring{$<$}{<}-\/\texorpdfstring{$>$}{>}Byte Order D1-\/\+D2-\/\+D3-\/\+D4-\/\+D5-\/\+D6 
\begin{DoxyParams}{Parameters}
{\em array-\/} & char array 144 bits to be programmed to Leds \\
\hline
\end{DoxyParams}
\begin{DoxyReturn}{Returns}
bool-\/ returns true if completed successfully or false if error occured. 
\end{DoxyReturn}
\mbox{\Hypertarget{classGpioController_ad8bbb818ca48b2535adaaf51908f7a4a}\label{classGpioController_ad8bbb818ca48b2535adaaf51908f7a4a}} 
\index{GpioController@{GpioController}!gpioLedSpiTest@{gpioLedSpiTest}}
\index{gpioLedSpiTest@{gpioLedSpiTest}!GpioController@{GpioController}}
\doxyparagraph{\texorpdfstring{gpioLedSpiTest()}{gpioLedSpiTest()}}
{\footnotesize\ttfamily bool Gpio\+Controller\+::gpio\+Led\+Spi\+Test (\begin{DoxyParamCaption}\item[{char $\ast$}]{arr }\end{DoxyParamCaption})}

Test command-\/ sets led to RGB brightness level via SPI interface 
\begin{DoxyParams}{Parameters}
{\em array-\/} & char array 144 bits to be programmed to Leds \\
\hline
\end{DoxyParams}
\begin{DoxyReturn}{Returns}
bool-\/ returns true if completed successfully or false if error occured. 
\end{DoxyReturn}
\mbox{\Hypertarget{classGpioController_a63da553df056aa124d06cacd27faf484}\label{classGpioController_a63da553df056aa124d06cacd27faf484}} 
\index{GpioController@{GpioController}!gpioSetOutput@{gpioSetOutput}}
\index{gpioSetOutput@{gpioSetOutput}!GpioController@{GpioController}}
\doxyparagraph{\texorpdfstring{gpioSetOutput()}{gpioSetOutput()}}
{\footnotesize\ttfamily int Gpio\+Controller\+::gpio\+Set\+Output (\begin{DoxyParamCaption}\item[{int}]{GPIOnumber,  }\item[{int}]{logic\+Level }\end{DoxyParamCaption})}

Sets Output level of GPIO 
\begin{DoxyParams}{Parameters}
{\em GPIOnumber-\/} & gpio number that is being modified. \\
\hline
{\em logic\+Level-\/} & 0 or 1. \\
\hline
\end{DoxyParams}
\begin{DoxyReturn}{Returns}
int-\/ Pi\+Gpio success or failure 
\end{DoxyReturn}
\mbox{\Hypertarget{classGpioController_aafdd41c8976402d25e1bf8db55819222}\label{classGpioController_aafdd41c8976402d25e1bf8db55819222}} 
\index{GpioController@{GpioController}!gpioTest@{gpioTest}}
\index{gpioTest@{gpioTest}!GpioController@{GpioController}}
\doxyparagraph{\texorpdfstring{gpioTest()}{gpioTest()}}
{\footnotesize\ttfamily bool Gpio\+Controller\+::gpio\+Test (\begin{DoxyParamCaption}\item[{uint}]{seconds }\end{DoxyParamCaption})}

GPIO Speed test. Toggles GPIO 4 (pin 7) at maximimum speed for user defined seconds. 
\begin{DoxyParams}{Parameters}
{\em seconds-\/} & uint number of seconds to run test for \\
\hline
\end{DoxyParams}
\begin{DoxyReturn}{Returns}
bool-\/ returns true if completed successfully or false if error occured. 
\end{DoxyReturn}
\mbox{\Hypertarget{classGpioController_aaf9f9b913c9312b1fb88b6d5d72e682b}\label{classGpioController_aaf9f9b913c9312b1fb88b6d5d72e682b}} 
\index{GpioController@{GpioController}!ledNopAsmTest@{ledNopAsmTest}}
\index{ledNopAsmTest@{ledNopAsmTest}!GpioController@{GpioController}}
\doxyparagraph{\texorpdfstring{ledNopAsmTest()}{ledNopAsmTest()}}
{\footnotesize\ttfamily bool Gpio\+Controller\+::led\+Nop\+Asm\+Test (\begin{DoxyParamCaption}\item[{uint}]{seconds }\end{DoxyParamCaption})}

Spew \textquotesingle{}1010\textquotesingle{} pattern to Leds using asm nop for delay 
\begin{DoxyParams}{Parameters}
{\em seconds-\/} & uint number of seconds to run test for \\
\hline
\end{DoxyParams}
\begin{DoxyReturn}{Returns}
bool-\/ returns true if completed successfully or false if error occured. 
\end{DoxyReturn}

The documentation for this class was generated from the following file\+:\begin{DoxyCompactItemize}
\item 
include/gpio\+\_\+controller.\+h\end{DoxyCompactItemize}

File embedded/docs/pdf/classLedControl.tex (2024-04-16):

\hypertarget{classLedControl}{}\doxysubsection{Led\+Control Class Reference}
\label{classLedControl}\index{LedControl@{LedControl}}
Inheritance diagram for Led\+Control\+:\begin{figure}[H]
\begin{center}
\leavevmode

\end{center}
\end{figure}
\doxysubsubsection*{Public Member Functions}
\begin{DoxyCompactItemize}
\item 
void \mbox{\hyperlink{classLedControl_a11c2879b60fc34cdaa30dda36ca95fe5}{led\+Create\+Color\+Arr}} (char $\ast$output\+Arr, unsigned led1, unsigned led2, unsigned led3, unsigned led4, unsigned led5, unsigned led6)
\item 
void \mbox{\hyperlink{classLedControl_a607f4f10ad59ed50061f486af65b8be8}{init\+Leds}} ()
\item 
void \mbox{\hyperlink{classLedControl_acfcbbfe2acbb7b4763d09e10a96be8b8}{led\+Flash\+Test}} (unsigned led\+Colour, int flash\+Time\+On, int flash\+Time\+Off, int flash\+Num)
\item 
void \mbox{\hyperlink{classLedControl_a09c4e34192a7991d04f7dc7f3265b201}{led\+Fade\+Test}} (int fade\+Num, int fade\+Speed)
\item 
void \mbox{\hyperlink{classLedControl_ad8c83b69dd491d5ca8fd806aa0ac198b}{set\+Led\+Velocity}} (sensor\+ID sensor, int avg\+Velocity)
\item 
void \mbox{\hyperlink{classLedControl_aa156a9966b9b372b23a9d3d6931c8178}{sensor\+Hit\+Led}} (sensor\+ID sensor, int hit\+Strength)
\item 
bool \mbox{\hyperlink{classLedControl_a84017bdd96fb715988e2dd86a2a94056}{sensor\+Hit\+Recently}} ()
\item 
unsigned \mbox{\hyperlink{classLedControl_a1106eac568e543ed3a8f156ff3c805df}{hit\+Color\+Setter}} (int sensor\+Str)
\item 
void \mbox{\hyperlink{classLedControl_a339d33f66690cbff3d3ba49c2123f8f4}{hit\+Detect\+Output\+Control}} ()
\item 
void \mbox{\hyperlink{classLedControl_a67a905403c6b62da32c1c0a2c361a841}{led\+SM}} ()
\item 
void \mbox{\hyperlink{classLedControl_af339507803651d408c47162dfddf2c6e}{led\+Initialise\+Test}} ()
\end{DoxyCompactItemize}
\doxysubsubsection*{Additional Inherited Members}

\doxysubsubsection{Member Function Documentation}
\mbox{\Hypertarget{classLedControl_a1106eac568e543ed3a8f156ff3c805df}\label{classLedControl_a1106eac568e543ed3a8f156ff3c805df}} 
\index{LedControl@{LedControl}!hitColorSetter@{hitColorSetter}}
\index{hitColorSetter@{hitColorSetter}!LedControl@{LedControl}}
\doxyparagraph{\texorpdfstring{hitColorSetter()}{hitColorSetter()}}
{\footnotesize\ttfamily unsigned Led\+Control\+::hit\+Color\+Setter (\begin{DoxyParamCaption}\item[{int}]{sensor\+Str }\end{DoxyParamCaption})}

Generates color for a sensor for a given hit strength 
\begin{DoxyParams}{Parameters}
{\em sensor\+Str-\/} & int hit strength velocity measured by sensor \\
\hline
\end{DoxyParams}
\mbox{\Hypertarget{classLedControl_a339d33f66690cbff3d3ba49c2123f8f4}\label{classLedControl_a339d33f66690cbff3d3ba49c2123f8f4}} 
\index{LedControl@{LedControl}!hitDetectOutputControl@{hitDetectOutputControl}}
\index{hitDetectOutputControl@{hitDetectOutputControl}!LedControl@{LedControl}}
\doxyparagraph{\texorpdfstring{hitDetectOutputControl()}{hitDetectOutputControl()}}
{\footnotesize\ttfamily void Led\+Control\+::hit\+Detect\+Output\+Control (\begin{DoxyParamCaption}{ }\end{DoxyParamCaption})}

Generates color for a sensor for a given amount of time when hit \mbox{\Hypertarget{classLedControl_a607f4f10ad59ed50061f486af65b8be8}\label{classLedControl_a607f4f10ad59ed50061f486af65b8be8}} 
\index{LedControl@{LedControl}!initLeds@{initLeds}}
\index{initLeds@{initLeds}!LedControl@{LedControl}}
\doxyparagraph{\texorpdfstring{initLeds()}{initLeds()}}
{\footnotesize\ttfamily void Led\+Control\+::init\+Leds (\begin{DoxyParamCaption}{ }\end{DoxyParamCaption})}

Initialize LED globals \mbox{\Hypertarget{classLedControl_a11c2879b60fc34cdaa30dda36ca95fe5}\label{classLedControl_a11c2879b60fc34cdaa30dda36ca95fe5}} 
\index{LedControl@{LedControl}!ledCreateColorArr@{ledCreateColorArr}}
\index{ledCreateColorArr@{ledCreateColorArr}!LedControl@{LedControl}}
\doxyparagraph{\texorpdfstring{ledCreateColorArr()}{ledCreateColorArr()}}
{\footnotesize\ttfamily void Led\+Control\+::led\+Create\+Color\+Arr (\begin{DoxyParamCaption}\item[{char $\ast$}]{output\+Arr,  }\item[{unsigned}]{led1,  }\item[{unsigned}]{led2,  }\item[{unsigned}]{led3,  }\item[{unsigned}]{led4,  }\item[{unsigned}]{led5,  }\item[{unsigned}]{led6 }\end{DoxyParamCaption})}

creates a single color array combined from input arguments. Will fill output\+Arr memory with combined data. Performs RGB-\/\texorpdfstring{$>$}{>}GRB byteshift 
\begin{DoxyParams}{Parameters}
{\em output\+Arr-\/} & char$\ast$ this needs to be 18char long empty array \\
\hline
{\em led1-\/} & unsigned 24bit value RGB color code. \\
\hline
{\em led2-\/} & unsigned 24bit value RGB color code. \\
\hline
{\em led3-\/} & unsigned 24bit value RGB color code. \\
\hline
{\em led4-\/} & unsigned 24bit value RGB color code. \\
\hline
{\em led5-\/} & unsigned 24bit value RGB color code. \\
\hline
{\em led6-\/} & unsigned 24bit value RGB color code. \\
\hline
\end{DoxyParams}
\mbox{\Hypertarget{classLedControl_a09c4e34192a7991d04f7dc7f3265b201}\label{classLedControl_a09c4e34192a7991d04f7dc7f3265b201}} 
\index{LedControl@{LedControl}!ledFadeTest@{ledFadeTest}}
\index{ledFadeTest@{ledFadeTest}!LedControl@{LedControl}}
\doxyparagraph{\texorpdfstring{ledFadeTest()}{ledFadeTest()}}
{\footnotesize\ttfamily void Led\+Control\+::led\+Fade\+Test (\begin{DoxyParamCaption}\item[{int}]{fade\+Num,  }\item[{int}]{fade\+Speed }\end{DoxyParamCaption})}

Makes all LEDs Fade from (0 -\/ 255) an number of times at a given speed 
\begin{DoxyParams}{Parameters}
{\em fade\+Step-\/} & int number of bits step changes in fade \\
\hline
{\em fade\+Num-\/} & int number of times LEDs fade \\
\hline
\end{DoxyParams}
\mbox{\Hypertarget{classLedControl_acfcbbfe2acbb7b4763d09e10a96be8b8}\label{classLedControl_acfcbbfe2acbb7b4763d09e10a96be8b8}} 
\index{LedControl@{LedControl}!ledFlashTest@{ledFlashTest}}
\index{ledFlashTest@{ledFlashTest}!LedControl@{LedControl}}
\doxyparagraph{\texorpdfstring{ledFlashTest()}{ledFlashTest()}}
{\footnotesize\ttfamily void Led\+Control\+::led\+Flash\+Test (\begin{DoxyParamCaption}\item[{unsigned}]{led\+Colour,  }\item[{int}]{flash\+Time\+On,  }\item[{int}]{flash\+Time\+Off,  }\item[{int}]{flash\+Num }\end{DoxyParamCaption})}

Makes all LEDs flash an number of times for a given colour at a speed in seconds 
\begin{DoxyParams}{Parameters}
{\em led\+Colour-\/} & unsigned 24bit value RGB color code. \\
\hline
{\em flash\+Time\+On-\/} & int number of seconds that LEDs are on \\
\hline
{\em flash\+Time\+Off-\/} & int number of seconds that LEDs are off \\
\hline
{\em flash\+Num-\/} & int number of times LEDs are flashed \\
\hline
\end{DoxyParams}
\mbox{\Hypertarget{classLedControl_af339507803651d408c47162dfddf2c6e}\label{classLedControl_af339507803651d408c47162dfddf2c6e}} 
\index{LedControl@{LedControl}!ledInitialiseTest@{ledInitialiseTest}}
\index{ledInitialiseTest@{ledInitialiseTest}!LedControl@{LedControl}}
\doxyparagraph{\texorpdfstring{ledInitialiseTest()}{ledInitialiseTest()}}
{\footnotesize\ttfamily void Led\+Control\+::led\+Initialise\+Test (\begin{DoxyParamCaption}{ }\end{DoxyParamCaption})}

Peter\textquotesingle{}s LED Initializer test \mbox{\Hypertarget{classLedControl_a67a905403c6b62da32c1c0a2c361a841}\label{classLedControl_a67a905403c6b62da32c1c0a2c361a841}} 
\index{LedControl@{LedControl}!ledSM@{ledSM}}
\index{ledSM@{ledSM}!LedControl@{LedControl}}
\doxyparagraph{\texorpdfstring{ledSM()}{ledSM()}}
{\footnotesize\ttfamily void Led\+Control\+::led\+SM (\begin{DoxyParamCaption}{ }\end{DoxyParamCaption})}

State Machine for LEDs \mbox{\Hypertarget{classLedControl_aa156a9966b9b372b23a9d3d6931c8178}\label{classLedControl_aa156a9966b9b372b23a9d3d6931c8178}} 
\index{LedControl@{LedControl}!sensorHitLed@{sensorHitLed}}
\index{sensorHitLed@{sensorHitLed}!LedControl@{LedControl}}
\doxyparagraph{\texorpdfstring{sensorHitLed()}{sensorHitLed()}}
{\footnotesize\ttfamily void Led\+Control\+::sensor\+Hit\+Led (\begin{DoxyParamCaption}\item[{sensor\+ID}]{sensor,  }\item[{int}]{hit\+Strength }\end{DoxyParamCaption})}

Takes the hit information from the sensor logic and provides LED feeddback depending on the strength 
\begin{DoxyParams}{Parameters}
{\em sensor\+ID-\/} & enum which sensor \\
\hline
{\em hit\+Strength-\/} & int hit strength velocity measured by sensor \\
\hline
\end{DoxyParams}
\mbox{\Hypertarget{classLedControl_a84017bdd96fb715988e2dd86a2a94056}\label{classLedControl_a84017bdd96fb715988e2dd86a2a94056}} 
\index{LedControl@{LedControl}!sensorHitRecently@{sensorHitRecently}}
\index{sensorHitRecently@{sensorHitRecently}!LedControl@{LedControl}}
\doxyparagraph{\texorpdfstring{sensorHitRecently()}{sensorHitRecently()}}
{\footnotesize\ttfamily bool Led\+Control\+::sensor\+Hit\+Recently (\begin{DoxyParamCaption}{ }\end{DoxyParamCaption})}

Checks if a sensor has been hit recently \mbox{\Hypertarget{classLedControl_ad8c83b69dd491d5ca8fd806aa0ac198b}\label{classLedControl_ad8c83b69dd491d5ca8fd806aa0ac198b}} 
\index{LedControl@{LedControl}!setLedVelocity@{setLedVelocity}}
\index{setLedVelocity@{setLedVelocity}!LedControl@{LedControl}}
\doxyparagraph{\texorpdfstring{setLedVelocity()}{setLedVelocity()}}
{\footnotesize\ttfamily void Led\+Control\+::set\+Led\+Velocity (\begin{DoxyParamCaption}\item[{sensor\+ID}]{sensor,  }\item[{int}]{avg\+Velocity }\end{DoxyParamCaption})}

Takes filtered velocity from controller and gives it to led state machine 
\begin{DoxyParams}{Parameters}
{\em id-\/} & enum which sensor \\
\hline
{\em avg\+Velocity-\/} & int current average velocity measured by sensor \\
\hline
\end{DoxyParams}

The documentation for this class was generated from the following file\+:\begin{DoxyCompactItemize}
\item 
include/led.\+h\end{DoxyCompactItemize}

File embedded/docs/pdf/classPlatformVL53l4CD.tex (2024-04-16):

\hypertarget{classPlatformVL53l4CD}{}\doxysubsection{Platform\+VL53l4\+CD Class Reference}
\label{classPlatformVL53l4CD}\index{PlatformVL53l4CD@{PlatformVL53l4CD}}

If the macro below is defined, the device will be programmed to run with I2C Fast Mode Plus (up to 1MHz). Otherwise, default max value is 400k\+Hz.  

{\ttfamily \#include $<$platform.\+h$>$}

\doxysubsubsection*{Public Member Functions}
\begin{DoxyCompactItemize}
\item 
\mbox{\Hypertarget{classPlatformVL53l4CD_a43c0603ac6b4f26de68e199ee86f9caa}\label{classPlatformVL53l4CD_a43c0603ac6b4f26de68e199ee86f9caa}} 
uint8\+\_\+t {\bfseries VL53\+L4\+CD\+\_\+comms\+\_\+init} (\mbox{\hyperlink{structVL53L4CD__LinuxDev}{Dev\+\_\+t}} dev)
\begin{DoxyCompactList}\small\item\em Init communication. \end{DoxyCompactList}\item 
\mbox{\Hypertarget{classPlatformVL53l4CD_a858fc5217712d93c931a990275248e39}\label{classPlatformVL53l4CD_a858fc5217712d93c931a990275248e39}} 
uint8\+\_\+t {\bfseries VL53\+L4\+CD\+\_\+comms\+\_\+close} (\mbox{\hyperlink{structVL53L4CD__LinuxDev}{Dev\+\_\+t}} dev)
\begin{DoxyCompactList}\small\item\em Close communication. \end{DoxyCompactList}\item 
\mbox{\Hypertarget{classPlatformVL53l4CD_abe1879b94ec170d9f870420e9555dc0b}\label{classPlatformVL53l4CD_abe1879b94ec170d9f870420e9555dc0b}} 
uint8\+\_\+t {\bfseries VL53\+L4\+CD\+\_\+\+Rd\+DWord} (\mbox{\hyperlink{structVL53L4CD__LinuxDev}{Dev\+\_\+t}} dev, uint16\+\_\+t register\+Addr, uint32\+\_\+t $\ast$value)
\begin{DoxyCompactList}\small\item\em Read 32 bits through I2C. \end{DoxyCompactList}\item 
\mbox{\Hypertarget{classPlatformVL53l4CD_a7c696355d0b7c2111ff834644a217c6d}\label{classPlatformVL53l4CD_a7c696355d0b7c2111ff834644a217c6d}} 
uint8\+\_\+t {\bfseries VL53\+L4\+CD\+\_\+\+Rd\+Word} (\mbox{\hyperlink{structVL53L4CD__LinuxDev}{Dev\+\_\+t}} dev, uint16\+\_\+t register\+Addr, uint16\+\_\+t $\ast$value)
\begin{DoxyCompactList}\small\item\em Read 16 bits through I2C. \end{DoxyCompactList}\item 
\mbox{\Hypertarget{classPlatformVL53l4CD_a7c1cf9a39727a030fe9feb9590d8f446}\label{classPlatformVL53l4CD_a7c1cf9a39727a030fe9feb9590d8f446}} 
uint8\+\_\+t {\bfseries VL53\+L4\+CD\+\_\+\+Rd\+Byte} (\mbox{\hyperlink{structVL53L4CD__LinuxDev}{Dev\+\_\+t}} dev, uint16\+\_\+t register\+Addr, uint8\+\_\+t $\ast$value)
\begin{DoxyCompactList}\small\item\em Read 8 bits through I2C. \end{DoxyCompactList}\item 
\mbox{\Hypertarget{classPlatformVL53l4CD_a4f78fa368a8b81f06c0dd6d817c6fc48}\label{classPlatformVL53l4CD_a4f78fa368a8b81f06c0dd6d817c6fc48}} 
uint8\+\_\+t {\bfseries VL53\+L4\+CD\+\_\+\+Wr\+Byte} (\mbox{\hyperlink{structVL53L4CD__LinuxDev}{Dev\+\_\+t}} dev, uint16\+\_\+t register\+Addr, uint8\+\_\+t value)
\begin{DoxyCompactList}\small\item\em Write 8 bits through I2C. \end{DoxyCompactList}\item 
\mbox{\Hypertarget{classPlatformVL53l4CD_ad15ab9a4659490f935684e074b93df56}\label{classPlatformVL53l4CD_ad15ab9a4659490f935684e074b93df56}} 
uint8\+\_\+t {\bfseries VL53\+L4\+CD\+\_\+\+Wr\+Word} (\mbox{\hyperlink{structVL53L4CD__LinuxDev}{Dev\+\_\+t}} dev, uint16\+\_\+t Register\+Adress, uint16\+\_\+t value)
\begin{DoxyCompactList}\small\item\em Write 16 bits through I2C. \end{DoxyCompactList}\item 
\mbox{\Hypertarget{classPlatformVL53l4CD_af66c025b0858dfdce35baa290d1f7e2c}\label{classPlatformVL53l4CD_af66c025b0858dfdce35baa290d1f7e2c}} 
uint8\+\_\+t {\bfseries VL53\+L4\+CD\+\_\+\+Wr\+DWord} (\mbox{\hyperlink{structVL53L4CD__LinuxDev}{Dev\+\_\+t}} dev, uint16\+\_\+t Register\+Adress, uint32\+\_\+t value)
\begin{DoxyCompactList}\small\item\em Write 32 bits through I2C. \end{DoxyCompactList}\item 
\mbox{\Hypertarget{classPlatformVL53l4CD_aeabbe4aa4fe2471ea72081e4e03366e1}\label{classPlatformVL53l4CD_aeabbe4aa4fe2471ea72081e4e03366e1}} 
uint8\+\_\+t {\bfseries Wait\+Ms} (\mbox{\hyperlink{structVL53L4CD__LinuxDev}{Dev\+\_\+t}} dev, uint32\+\_\+t Time\+Ms)
\begin{DoxyCompactList}\small\item\em Wait during N milliseconds. \end{DoxyCompactList}\end{DoxyCompactItemize}

\doxysubsubsection{Detailed Description}
If the macro below is defined, the device will be programmed to run with I2C Fast Mode Plus (up to 1MHz). Otherwise, default max value is 400k\+Hz. 

The documentation for this class was generated from the following file\+:\begin{DoxyCompactItemize}
\item 
include/platform.\+h\end{DoxyCompactItemize}

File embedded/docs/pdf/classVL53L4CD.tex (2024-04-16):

\hypertarget{classVL53L4CD}{}\doxysubsection{VL53\+L4\+CD Class Reference}
\label{classVL53L4CD}\index{VL53L4CD@{VL53L4CD}}
Inheritance diagram for VL53\+L4\+CD\+:\begin{figure}[H]
\begin{center}
\leavevmode

\end{center}
\end{figure}
\doxysubsubsection*{Public Member Functions}
\begin{DoxyCompactItemize}
\item 
void \mbox{\hyperlink{classVL53L4CD_aa50845e779bebe4d312e79ef1a14a62b}{ranging\+Init}} ()
\item 
void \mbox{\hyperlink{classVL53L4CD_a07ac79dcf2d0ba4c91df4fb0aea824f0}{ranging\+Test\+Distance\+Sensors}} ()
\item 
\mbox{\hyperlink{structsensorValues}{sensor\+Values}} \mbox{\hyperlink{classVL53L4CD_ad81309cbabd2f3a7f4eb1c26cd97a64d}{ranging\+Get\+Data}} (sensor\+ID sensor)
\item 
bool \mbox{\hyperlink{classVL53L4CD_af33c4ab62ad9db0773ed3dadaa0257c5}{ranging\+Check\+If\+Ready}} (sensor\+ID sensor)
\item 
virtual void \mbox{\hyperlink{classVL53L4CD_a149a2250aabe18254a50be683b9fbba5}{distance\+Data\+Ready}} (\mbox{\hyperlink{structsensorValues}{sensor\+Values}} sens\+Vals, sensor\+ID sensor)=0
\end{DoxyCompactItemize}

\doxysubsubsection{Member Function Documentation}
\mbox{\Hypertarget{classVL53L4CD_a149a2250aabe18254a50be683b9fbba5}\label{classVL53L4CD_a149a2250aabe18254a50be683b9fbba5}} 
\index{VL53L4CD@{VL53L4CD}!distanceDataReady@{distanceDataReady}}
\index{distanceDataReady@{distanceDataReady}!VL53L4CD@{VL53L4CD}}
\doxyparagraph{\texorpdfstring{distanceDataReady()}{distanceDataReady()}}
{\footnotesize\ttfamily virtual void VL53\+L4\+CD\+::distance\+Data\+Ready (\begin{DoxyParamCaption}\item[{\mbox{\hyperlink{structsensorValues}{sensor\+Values}}}]{sens\+Vals,  }\item[{sensor\+ID}]{sensor }\end{DoxyParamCaption})\hspace{0.3cm}{\ttfamily [pure virtual]}}

Called when new Distance sensor data has been recieved. This needs to be implemented in a derived class by the client. Defined as abstract. 
\begin{DoxyParams}{Parameters}
{\em sens\+Vals} & -\/ sense\+Vals structure that contains sensor data \\
\hline
{\em sensor} & -\/ Sensor\+ID signifying which sensor data is coming from \\
\hline
\end{DoxyParams}

Implemented in \mbox{\hyperlink{classController_af53bfa42e907627e5f39668e3d8acb5c}{Controller}}.

\mbox{\Hypertarget{classVL53L4CD_af33c4ab62ad9db0773ed3dadaa0257c5}\label{classVL53L4CD_af33c4ab62ad9db0773ed3dadaa0257c5}} 
\index{VL53L4CD@{VL53L4CD}!rangingCheckIfReady@{rangingCheckIfReady}}
\index{rangingCheckIfReady@{rangingCheckIfReady}!VL53L4CD@{VL53L4CD}}
\doxyparagraph{\texorpdfstring{rangingCheckIfReady()}{rangingCheckIfReady()}}
{\footnotesize\ttfamily bool VL53\+L4\+CD\+::ranging\+Check\+If\+Ready (\begin{DoxyParamCaption}\item[{sensor\+ID}]{sensor }\end{DoxyParamCaption})}

returns if a sensor has data ready 
\begin{DoxyParams}{Parameters}
{\em sensor} & -\/ sensor\+ID \\
\hline
\end{DoxyParams}
\begin{DoxyReturn}{Returns}
bool 
\end{DoxyReturn}
\mbox{\Hypertarget{classVL53L4CD_ad81309cbabd2f3a7f4eb1c26cd97a64d}\label{classVL53L4CD_ad81309cbabd2f3a7f4eb1c26cd97a64d}} 
\index{VL53L4CD@{VL53L4CD}!rangingGetData@{rangingGetData}}
\index{rangingGetData@{rangingGetData}!VL53L4CD@{VL53L4CD}}
\doxyparagraph{\texorpdfstring{rangingGetData()}{rangingGetData()}}
{\footnotesize\ttfamily \mbox{\hyperlink{structsensorValues}{sensor\+Values}} VL53\+L4\+CD\+::ranging\+Get\+Data (\begin{DoxyParamCaption}\item[{sensor\+ID}]{sensor }\end{DoxyParamCaption})}

Get data from input dev id 
\begin{DoxyParams}{Parameters}
{\em sensor} & -\/ sensor\+ID \\
\hline
\end{DoxyParams}
\begin{DoxyReturn}{Returns}
\mbox{\hyperlink{structsensorValues}{sensor\+Values}} 
\end{DoxyReturn}
\mbox{\Hypertarget{classVL53L4CD_aa50845e779bebe4d312e79ef1a14a62b}\label{classVL53L4CD_aa50845e779bebe4d312e79ef1a14a62b}} 
\index{VL53L4CD@{VL53L4CD}!rangingInit@{rangingInit}}
\index{rangingInit@{rangingInit}!VL53L4CD@{VL53L4CD}}
\doxyparagraph{\texorpdfstring{rangingInit()}{rangingInit()}}
{\footnotesize\ttfamily void VL53\+L4\+CD\+::ranging\+Init (\begin{DoxyParamCaption}{ }\end{DoxyParamCaption})}

Initialize disatance sensor globals \mbox{\Hypertarget{classVL53L4CD_a07ac79dcf2d0ba4c91df4fb0aea824f0}\label{classVL53L4CD_a07ac79dcf2d0ba4c91df4fb0aea824f0}} 
\index{VL53L4CD@{VL53L4CD}!rangingTestDistanceSensors@{rangingTestDistanceSensors}}
\index{rangingTestDistanceSensors@{rangingTestDistanceSensors}!VL53L4CD@{VL53L4CD}}
\doxyparagraph{\texorpdfstring{rangingTestDistanceSensors()}{rangingTestDistanceSensors()}}
{\footnotesize\ttfamily void VL53\+L4\+CD\+::ranging\+Test\+Distance\+Sensors (\begin{DoxyParamCaption}{ }\end{DoxyParamCaption})}

Test Distance Sensors 

The documentation for this class was generated from the following file\+:\begin{DoxyCompactItemize}
\item 
include/ranging.\+h\end{DoxyCompactItemize}

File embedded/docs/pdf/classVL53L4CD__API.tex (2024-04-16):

\hypertarget{classVL53L4CD__API}{}\doxysubsection{VL53\+L4\+CD\+\_\+\+API Class Reference}
\label{classVL53L4CD__API}\index{VL53L4CD\_API@{VL53L4CD\_API}}
\doxysubsubsection*{Public Member Functions}
\begin{DoxyCompactItemize}
\item 
VL53\+L4\+CD\+\_\+\+Error \mbox{\hyperlink{classVL53L4CD__API_a2e522cd6d66becb6315fb2fa50a00055}{VL53\+L4\+CD\+\_\+\+Get\+SWVersion}} (\mbox{\hyperlink{structVL53L4CD__Version__t}{VL53\+L4\+CD\+\_\+\+Version\+\_\+t}} $\ast$p\+Version)
\begin{DoxyCompactList}\small\item\em This function programs the software driver version. \end{DoxyCompactList}\item 
VL53\+L4\+CD\+\_\+\+Error \mbox{\hyperlink{classVL53L4CD__API_a87523f5f80914c5712bbb2d9714b6267}{VL53\+L4\+CD\+\_\+\+Set\+I2\+CAddress}} (\mbox{\hyperlink{structVL53L4CD__LinuxDev}{Dev\+\_\+t}} dev, uint8\+\_\+t new\+\_\+address)
\begin{DoxyCompactList}\small\item\em This function sets a new I2C address to a sensor. It can be used for example when multiple sensors share the same I2C bus. \end{DoxyCompactList}\item 
VL53\+L4\+CD\+\_\+\+Error \mbox{\hyperlink{classVL53L4CD__API_a39750d4a46e02e81b5ae0e739def7ed0}{VL53\+L4\+CD\+\_\+\+Get\+Sensor\+Id}} (\mbox{\hyperlink{structVL53L4CD__LinuxDev}{Dev\+\_\+t}} dev, uint16\+\_\+t $\ast$p\+\_\+id)
\begin{DoxyCompactList}\small\item\em This function is used to get the sensor id of \mbox{\hyperlink{classVL53L4CD}{VL53\+L4\+CD}}. The sensor id should be 0x\+EBAA. \end{DoxyCompactList}\item 
VL53\+L4\+CD\+\_\+\+Error \mbox{\hyperlink{classVL53L4CD__API_ad04915d4dc676f2306874b75a670c091}{VL53\+L4\+CD\+\_\+\+Sensor\+Init}} (\mbox{\hyperlink{structVL53L4CD__LinuxDev}{Dev\+\_\+t}} dev)
\begin{DoxyCompactList}\small\item\em This function is used to initialize the sensor. \end{DoxyCompactList}\item 
VL53\+L4\+CD\+\_\+\+Error \mbox{\hyperlink{classVL53L4CD__API_a0779f406671b37fc75b34c20d6c56eee}{VL53\+L4\+CD\+\_\+\+Clear\+Interrupt}} (\mbox{\hyperlink{structVL53L4CD__LinuxDev}{Dev\+\_\+t}} dev)
\begin{DoxyCompactList}\small\item\em This function clears the interrupt. It needs to be called after a ranging data reading to arm the interrupt for the next data ready event. \end{DoxyCompactList}\item 
VL53\+L4\+CD\+\_\+\+Error \mbox{\hyperlink{classVL53L4CD__API_a3013012a08e2592d13653a267806c98c}{VL53\+L4\+CD\+\_\+\+Start\+Ranging}} (\mbox{\hyperlink{structVL53L4CD__LinuxDev}{Dev\+\_\+t}} dev)
\begin{DoxyCompactList}\small\item\em This function starts a ranging session. The ranging operation is continuous. The clear interrupt has to be done after each get data to allow the interrupt to raise when the next data is ready. \end{DoxyCompactList}\item 
VL53\+L4\+CD\+\_\+\+Error \mbox{\hyperlink{classVL53L4CD__API_a491af0b13c9fa2c9e3197b80c2f50f8b}{VL53\+L4\+CD\+\_\+\+Stop\+Ranging}} (\mbox{\hyperlink{structVL53L4CD__LinuxDev}{Dev\+\_\+t}} dev)
\begin{DoxyCompactList}\small\item\em This function stops the ranging in progress. \end{DoxyCompactList}\item 
VL53\+L4\+CD\+\_\+\+Error \mbox{\hyperlink{classVL53L4CD__API_adbcb7208dd993b4c03b1bed873af975d}{VL53\+L4\+CD\+\_\+\+Check\+For\+Data\+Ready}} (\mbox{\hyperlink{structVL53L4CD__LinuxDev}{Dev\+\_\+t}} dev, uint8\+\_\+t $\ast$p\+\_\+is\+\_\+data\+\_\+ready)
\begin{DoxyCompactList}\small\item\em This function check if a new data is available by polling a dedicated register. \end{DoxyCompactList}\item 
VL53\+L4\+CD\+\_\+\+Error \mbox{\hyperlink{classVL53L4CD__API_a2585a3f22fdf2b0ee32820ec42da3961}{VL53\+L4\+CD\+\_\+\+Set\+Range\+Timing}} (\mbox{\hyperlink{structVL53L4CD__LinuxDev}{Dev\+\_\+t}} dev, uint32\+\_\+t timing\+\_\+budget\+\_\+ms, uint32\+\_\+t inter\+\_\+measurement\+\_\+ms)
\begin{DoxyCompactList}\small\item\em This function sets new range timing. Timing are composed of Timing\+Budget and Inter\+Measurement. Timing\+Budget represents the timing during VCSEL enabled, and Inter\+Measurement the time between two measurements. The sensor can have different ranging mode depending of the configuration, please refer to the user manual for more information. \end{DoxyCompactList}\item 
VL53\+L4\+CD\+\_\+\+Error \mbox{\hyperlink{classVL53L4CD__API_a25f7a067fae122c18757c4197502de66}{VL53\+L4\+CD\+\_\+\+Get\+Range\+Timing}} (\mbox{\hyperlink{structVL53L4CD__LinuxDev}{Dev\+\_\+t}} dev, uint32\+\_\+t $\ast$p\+\_\+timing\+\_\+budget\+\_\+ms, uint32\+\_\+t $\ast$p\+\_\+inter\+\_\+measurement\+\_\+ms)
\begin{DoxyCompactList}\small\item\em This function gets the current range timing. Timing are composed of Timing\+Budget and Inter\+Measurement. Timing\+Budget represents the timing during VCSEL enabled, and Inter\+Measurement the time between two measurements. The sensor can have different ranging mode depending of the configuration, please refer to the user manual for more information. \end{DoxyCompactList}\item 
VL53\+L4\+CD\+\_\+\+Error \mbox{\hyperlink{classVL53L4CD__API_af19795ff7d4e1b8f3153ab2e033302e7}{VL53\+L4\+CD\+\_\+\+Get\+Result}} (\mbox{\hyperlink{structVL53L4CD__LinuxDev}{Dev\+\_\+t}} dev, \mbox{\hyperlink{structVL53L4CD__ResultsData__t}{VL53\+L4\+CD\+\_\+\+Results\+Data\+\_\+t}} $\ast$p\+Result)
\begin{DoxyCompactList}\small\item\em This function gets the results reported by the sensor. \end{DoxyCompactList}\item 
VL53\+L4\+CD\+\_\+\+Error \mbox{\hyperlink{classVL53L4CD__API_a4cd4dc976d343d0cff8696ea60a1068d}{VL53\+L4\+CD\+\_\+\+Set\+Offset}} (\mbox{\hyperlink{structVL53L4CD__LinuxDev}{Dev\+\_\+t}} dev, int16\+\_\+t Offset\+Value\+In\+Mm)
\begin{DoxyCompactList}\small\item\em This function sets a new offset correction in mm. Offset corresponds to the difference in millimeters between real distance and measured distance. \end{DoxyCompactList}\item 
VL53\+L4\+CD\+\_\+\+Error \mbox{\hyperlink{classVL53L4CD__API_a5aa27650d85f31b269426710fb8ebc93}{VL53\+L4\+CD\+\_\+\+Get\+Offset}} (\mbox{\hyperlink{structVL53L4CD__LinuxDev}{Dev\+\_\+t}} dev, int16\+\_\+t $\ast$Offset)
\begin{DoxyCompactList}\small\item\em This function gets the current offset correction in mm. Offset corresponds to the difference in millimeters between real distance and measured distance. \end{DoxyCompactList}\item 
VL53\+L4\+CD\+\_\+\+Error \mbox{\hyperlink{classVL53L4CD__API_a1e02c0ae9a798c8972e84cb22b3c4a06}{VL53\+L4\+CD\+\_\+\+Set\+Xtalk}} (\mbox{\hyperlink{structVL53L4CD__LinuxDev}{Dev\+\_\+t}} dev, uint16\+\_\+t Xtalk\+Value\+Kcps)
\begin{DoxyCompactList}\small\item\em This function sets a new Xtalk value in kcps. Xtalk represents the correction to apply to the sensor when a protective coverglass is placed at the top of the sensor. \end{DoxyCompactList}\item 
VL53\+L4\+CD\+\_\+\+Error \mbox{\hyperlink{classVL53L4CD__API_a0a42e28fc1e58cc1708d3a9b49563f03}{VL53\+L4\+CD\+\_\+\+Get\+Xtalk}} (\mbox{\hyperlink{structVL53L4CD__LinuxDev}{Dev\+\_\+t}} dev, uint16\+\_\+t $\ast$p\+\_\+xtalk\+\_\+kcps)
\begin{DoxyCompactList}\small\item\em This function gets the current Xtalk value in kcps. Xtalk represents the correction to apply to the sensor when a protective coverglass is placed at the top of the sensor. \end{DoxyCompactList}\item 
VL53\+L4\+CD\+\_\+\+Error \mbox{\hyperlink{classVL53L4CD__API_a4d9a651e5194e5daa081085c6691642f}{VL53\+L4\+CD\+\_\+\+Set\+Detection\+Thresholds}} (\mbox{\hyperlink{structVL53L4CD__LinuxDev}{Dev\+\_\+t}} dev, uint16\+\_\+t distance\+\_\+low\+\_\+mm, uint16\+\_\+t distance\+\_\+high\+\_\+mm, uint8\+\_\+t window)
\begin{DoxyCompactList}\small\item\em This function sets new detection thresholds. The detection thresholds can be programmed to generate an interrupt on pin 7 (GPIO1), only when a condition on distance is reach. Example\+: VL53\+L4\+CD\+\_\+\+Set\+Distance\+Threshold(dev,100,300,0)\+: Below 100 mm VL53\+L4\+CD\+\_\+\+Set\+Distance\+Threshold(dev,100,300,1)\+: Above 300 mm VL53\+L4\+CD\+\_\+\+Set\+Distance\+Threshold(dev,100,300,2)\+: Below 100mm or above 300mm VL53\+L4\+CD\+\_\+\+Set\+Distance\+Threshold(dev,100,300,3)\+: Above 100mm or below 300mm. \end{DoxyCompactList}\item 
VL53\+L4\+CD\+\_\+\+Error \mbox{\hyperlink{classVL53L4CD__API_adc880b2d4e70fa6ba50822740a0802bc}{VL53\+L4\+CD\+\_\+\+Get\+Detection\+Thresholds}} (\mbox{\hyperlink{structVL53L4CD__LinuxDev}{Dev\+\_\+t}} dev, uint16\+\_\+t $\ast$p\+\_\+distance\+\_\+low\+\_\+mm, uint16\+\_\+t $\ast$p\+\_\+distance\+\_\+high\+\_\+mm, uint8\+\_\+t $\ast$p\+\_\+window)
\begin{DoxyCompactList}\small\item\em This function gets the current detection thresholds. The detection thresholds can be programmed to generate an interrupt on pin 7 (GPIO1), only when a condition on distance is reach. \end{DoxyCompactList}\item 
VL53\+L4\+CD\+\_\+\+Error \mbox{\hyperlink{classVL53L4CD__API_a115c3de908fb7b9dbfcf91bdac6a551c}{VL53\+L4\+CD\+\_\+\+Set\+Signal\+Threshold}} (\mbox{\hyperlink{structVL53L4CD__LinuxDev}{Dev\+\_\+t}} dev, uint16\+\_\+t signal\+\_\+kcps)
\begin{DoxyCompactList}\small\item\em This function sets a new signal threshold in kcps. If a target has a lower signal as the programmed value, the result status in structure \textquotesingle{}\mbox{\hyperlink{structVL53L4CD__ResultsData__t}{VL53\+L4\+CD\+\_\+\+Results\+Data\+\_\+t}}\textquotesingle{} will be equal to 2. \end{DoxyCompactList}\item 
VL53\+L4\+CD\+\_\+\+Error \mbox{\hyperlink{classVL53L4CD__API_ade677c4e4e63c12b1b34fca50180f7a0}{VL53\+L4\+CD\+\_\+\+Get\+Signal\+Threshold}} (\mbox{\hyperlink{structVL53L4CD__LinuxDev}{Dev\+\_\+t}} dev, uint16\+\_\+t $\ast$p\+\_\+signal\+\_\+kcps)
\begin{DoxyCompactList}\small\item\em This function returns the current signal threshold in kcps. If a target has a lower signal as the programmed value, the result status in structure \textquotesingle{}\mbox{\hyperlink{structVL53L4CD__ResultsData__t}{VL53\+L4\+CD\+\_\+\+Results\+Data\+\_\+t}}\textquotesingle{} will be equal to 2. \end{DoxyCompactList}\item 
VL53\+L4\+CD\+\_\+\+Error \mbox{\hyperlink{classVL53L4CD__API_ada4fb4ff20dacbed66e6c5261e4ff813}{VL53\+L4\+CD\+\_\+\+Set\+Sigma\+Threshold}} (\mbox{\hyperlink{structVL53L4CD__LinuxDev}{Dev\+\_\+t}} dev, uint16\+\_\+t sigma\+\_\+mm)
\begin{DoxyCompactList}\small\item\em This function programs a new sigma threshold. The sigma corresponds to the standard deviation of the returned pulse. If the computed sigma is above the programmed value, the result status in structure \textquotesingle{}\mbox{\hyperlink{structVL53L4CD__ResultsData__t}{VL53\+L4\+CD\+\_\+\+Results\+Data\+\_\+t}}\textquotesingle{} will be equal to 1. \end{DoxyCompactList}\item 
VL53\+L4\+CD\+\_\+\+Error \mbox{\hyperlink{classVL53L4CD__API_a443fc7e50040da91572b1371f6d23fe1}{VL53\+L4\+CD\+\_\+\+Get\+Sigma\+Threshold}} (\mbox{\hyperlink{structVL53L4CD__LinuxDev}{Dev\+\_\+t}} dev, uint16\+\_\+t $\ast$p\+\_\+sigma\+\_\+mm)
\begin{DoxyCompactList}\small\item\em This function gets the current sigma threshold. The sigma corresponds to the standard deviation of the returned pulse. If the computed sigma is above the programmed value, the result status in structure \textquotesingle{}\mbox{\hyperlink{structVL53L4CD__ResultsData__t}{VL53\+L4\+CD\+\_\+\+Results\+Data\+\_\+t}}\textquotesingle{} will be equal to 1. \end{DoxyCompactList}\item 
VL53\+L4\+CD\+\_\+\+Error \mbox{\hyperlink{classVL53L4CD__API_aa9c83b64bcfbb37376b0694c64745564}{VL53\+L4\+CD\+\_\+\+Start\+Temperature\+Update}} (\mbox{\hyperlink{structVL53L4CD__LinuxDev}{Dev\+\_\+t}} dev)
\begin{DoxyCompactList}\small\item\em This function can be called when the temperature might have changed by more than 8 degrees Celsius. The function can only be used if the sensor is not ranging, otherwise, the ranging needs to be stopped using function \textquotesingle{}\mbox{\hyperlink{classVL53L4CD__API_a491af0b13c9fa2c9e3197b80c2f50f8b}{VL53\+L4\+CD\+\_\+\+Stop\+Ranging()}}\textquotesingle{}. After calling this function, the ranging can restart normally. \end{DoxyCompactList}\end{DoxyCompactItemize}

\doxysubsubsection{Member Function Documentation}
\mbox{\Hypertarget{classVL53L4CD__API_adbcb7208dd993b4c03b1bed873af975d}\label{classVL53L4CD__API_adbcb7208dd993b4c03b1bed873af975d}} 
\index{VL53L4CD\_API@{VL53L4CD\_API}!VL53L4CD\_CheckForDataReady@{VL53L4CD\_CheckForDataReady}}
\index{VL53L4CD\_CheckForDataReady@{VL53L4CD\_CheckForDataReady}!VL53L4CD\_API@{VL53L4CD\_API}}
\doxyparagraph{\texorpdfstring{VL53L4CD\_CheckForDataReady()}{VL53L4CD\_CheckForDataReady()}}
{\footnotesize\ttfamily VL53\+L4\+CD\+\_\+\+Error VL53\+L4\+CD\+\_\+\+API\+::\+VL53\+L4\+CD\+\_\+\+Check\+For\+Data\+Ready (\begin{DoxyParamCaption}\item[{\mbox{\hyperlink{structVL53L4CD__LinuxDev}{Dev\+\_\+t}}}]{dev,  }\item[{uint8\+\_\+t $\ast$}]{p\+\_\+is\+\_\+data\+\_\+ready }\end{DoxyParamCaption})}

This function check if a new data is available by polling a dedicated register. 

\begin{DoxyParams}{Parameters}
{\em (\+Dev\+\_\+t)} & dev \+: instance of selected \mbox{\hyperlink{classVL53L4CD}{VL53\+L4\+CD}} sensor. \\
\hline
{\em (uint8\+\_\+t)} & $\ast$p\+\_\+is\+\_\+data\+\_\+ready \+: Pointer containing a flag to know if a data is ready \+: 0 = no data ready, 1 = data ready. \\
\hline
\end{DoxyParams}
\begin{DoxyReturn}{Returns}
(VL53\+L4\+CD\+\_\+\+ERROR) status \+: 0 if OK. 
\end{DoxyReturn}
\mbox{\Hypertarget{classVL53L4CD__API_a0779f406671b37fc75b34c20d6c56eee}\label{classVL53L4CD__API_a0779f406671b37fc75b34c20d6c56eee}} 
\index{VL53L4CD\_API@{VL53L4CD\_API}!VL53L4CD\_ClearInterrupt@{VL53L4CD\_ClearInterrupt}}
\index{VL53L4CD\_ClearInterrupt@{VL53L4CD\_ClearInterrupt}!VL53L4CD\_API@{VL53L4CD\_API}}
\doxyparagraph{\texorpdfstring{VL53L4CD\_ClearInterrupt()}{VL53L4CD\_ClearInterrupt()}}
{\footnotesize\ttfamily VL53\+L4\+CD\+\_\+\+Error VL53\+L4\+CD\+\_\+\+API\+::\+VL53\+L4\+CD\+\_\+\+Clear\+Interrupt (\begin{DoxyParamCaption}\item[{\mbox{\hyperlink{structVL53L4CD__LinuxDev}{Dev\+\_\+t}}}]{dev }\end{DoxyParamCaption})}

This function clears the interrupt. It needs to be called after a ranging data reading to arm the interrupt for the next data ready event. 

\begin{DoxyParams}{Parameters}
{\em (\+Dev\+\_\+t)} & dev \+: Device instance. \\
\hline
\end{DoxyParams}
\begin{DoxyReturn}{Returns}
(VL53\+L4\+CD\+\_\+\+ERROR) status \+: 0 if OK. 
\end{DoxyReturn}
\mbox{\Hypertarget{classVL53L4CD__API_adc880b2d4e70fa6ba50822740a0802bc}\label{classVL53L4CD__API_adc880b2d4e70fa6ba50822740a0802bc}} 
\index{VL53L4CD\_API@{VL53L4CD\_API}!VL53L4CD\_GetDetectionThresholds@{VL53L4CD\_GetDetectionThresholds}}
\index{VL53L4CD\_GetDetectionThresholds@{VL53L4CD\_GetDetectionThresholds}!VL53L4CD\_API@{VL53L4CD\_API}}
\doxyparagraph{\texorpdfstring{VL53L4CD\_GetDetectionThresholds()}{VL53L4CD\_GetDetectionThresholds()}}
{\footnotesize\ttfamily VL53\+L4\+CD\+\_\+\+Error VL53\+L4\+CD\+\_\+\+API\+::\+VL53\+L4\+CD\+\_\+\+Get\+Detection\+Thresholds (\begin{DoxyParamCaption}\item[{\mbox{\hyperlink{structVL53L4CD__LinuxDev}{Dev\+\_\+t}}}]{dev,  }\item[{uint16\+\_\+t $\ast$}]{p\+\_\+distance\+\_\+low\+\_\+mm,  }\item[{uint16\+\_\+t $\ast$}]{p\+\_\+distance\+\_\+high\+\_\+mm,  }\item[{uint8\+\_\+t $\ast$}]{p\+\_\+window }\end{DoxyParamCaption})}

This function gets the current detection thresholds. The detection thresholds can be programmed to generate an interrupt on pin 7 (GPIO1), only when a condition on distance is reach. 

\begin{DoxyParams}{Parameters}
{\em (\+Dev\+\_\+t)} & dev \+: instance of selected \mbox{\hyperlink{classVL53L4CD}{VL53\+L4\+CD}} sensor. \\
\hline
{\em (uint16\+\_\+t)} & $\ast$p\+\_\+distance\+\_\+low\+\_\+mm \+: Pointer of low distance threshold in millimeters. \\
\hline
{\em (uint16\+\_\+t)} & $\ast$p\+\_\+distance\+\_\+high\+\_\+mm \+: Pointer of high distance threshold in millimeters. \\
\hline
{\em (uint8\+\_\+t)} & $\ast$p\+\_\+window \+: Interrupt windows (0=below low threshold; 1=above high threshold; 2=out of low/high windows; 3=in low/high windows) \\
\hline
\end{DoxyParams}
\begin{DoxyReturn}{Returns}
(VL53\+L4\+CD\+\_\+\+ERROR) status \+: 0 if OK. 
\end{DoxyReturn}
\mbox{\Hypertarget{classVL53L4CD__API_a5aa27650d85f31b269426710fb8ebc93}\label{classVL53L4CD__API_a5aa27650d85f31b269426710fb8ebc93}} 
\index{VL53L4CD\_API@{VL53L4CD\_API}!VL53L4CD\_GetOffset@{VL53L4CD\_GetOffset}}
\index{VL53L4CD\_GetOffset@{VL53L4CD\_GetOffset}!VL53L4CD\_API@{VL53L4CD\_API}}
\doxyparagraph{\texorpdfstring{VL53L4CD\_GetOffset()}{VL53L4CD\_GetOffset()}}
{\footnotesize\ttfamily VL53\+L4\+CD\+\_\+\+Error VL53\+L4\+CD\+\_\+\+API\+::\+VL53\+L4\+CD\+\_\+\+Get\+Offset (\begin{DoxyParamCaption}\item[{\mbox{\hyperlink{structVL53L4CD__LinuxDev}{Dev\+\_\+t}}}]{dev,  }\item[{int16\+\_\+t $\ast$}]{Offset }\end{DoxyParamCaption})}

This function gets the current offset correction in mm. Offset corresponds to the difference in millimeters between real distance and measured distance. 

\begin{DoxyParams}{Parameters}
{\em (\+Dev\+\_\+t)} & dev \+: instance of selected \mbox{\hyperlink{classVL53L4CD}{VL53\+L4\+CD}} sensor. \\
\hline
{\em (int16\+\_\+t)} & Offset\+Value\+In\+Mm \+: Offset value in millimeters. The minimum value is -\/1024mm and maximum is 1023mm. \\
\hline
\end{DoxyParams}
\begin{DoxyReturn}{Returns}
(uint8\+\_\+t) status \+: 0 if OK. 
\end{DoxyReturn}
\mbox{\Hypertarget{classVL53L4CD__API_a25f7a067fae122c18757c4197502de66}\label{classVL53L4CD__API_a25f7a067fae122c18757c4197502de66}} 
\index{VL53L4CD\_API@{VL53L4CD\_API}!VL53L4CD\_GetRangeTiming@{VL53L4CD\_GetRangeTiming}}
\index{VL53L4CD\_GetRangeTiming@{VL53L4CD\_GetRangeTiming}!VL53L4CD\_API@{VL53L4CD\_API}}
\doxyparagraph{\texorpdfstring{VL53L4CD\_GetRangeTiming()}{VL53L4CD\_GetRangeTiming()}}
{\footnotesize\ttfamily VL53\+L4\+CD\+\_\+\+Error VL53\+L4\+CD\+\_\+\+API\+::\+VL53\+L4\+CD\+\_\+\+Get\+Range\+Timing (\begin{DoxyParamCaption}\item[{\mbox{\hyperlink{structVL53L4CD__LinuxDev}{Dev\+\_\+t}}}]{dev,  }\item[{uint32\+\_\+t $\ast$}]{p\+\_\+timing\+\_\+budget\+\_\+ms,  }\item[{uint32\+\_\+t $\ast$}]{p\+\_\+inter\+\_\+measurement\+\_\+ms }\end{DoxyParamCaption})}

This function gets the current range timing. Timing are composed of Timing\+Budget and Inter\+Measurement. Timing\+Budget represents the timing during VCSEL enabled, and Inter\+Measurement the time between two measurements. The sensor can have different ranging mode depending of the configuration, please refer to the user manual for more information. 

\begin{DoxyParams}{Parameters}
{\em (\+Dev\+\_\+t)} & dev \+: instance of selected \mbox{\hyperlink{classVL53L4CD}{VL53\+L4\+CD}} sensor. \\
\hline
{\em (uint32\+\_\+t)} & $\ast$p\+\_\+timing\+\_\+budget\+\_\+ms \+: Pointer containing the current timing budget in ms. \\
\hline
{\em (uint32\+\_\+t)} & $\ast$p\+\_\+inter\+\_\+measurement\+\_\+ms \+: Pointer containing the current inter-\/measurement in ms. \\
\hline
\end{DoxyParams}
\begin{DoxyReturn}{Returns}
(uint8\+\_\+t) status \+: 0 if OK. 
\end{DoxyReturn}
\mbox{\Hypertarget{classVL53L4CD__API_af19795ff7d4e1b8f3153ab2e033302e7}\label{classVL53L4CD__API_af19795ff7d4e1b8f3153ab2e033302e7}} 
\index{VL53L4CD\_API@{VL53L4CD\_API}!VL53L4CD\_GetResult@{VL53L4CD\_GetResult}}
\index{VL53L4CD\_GetResult@{VL53L4CD\_GetResult}!VL53L4CD\_API@{VL53L4CD\_API}}
\doxyparagraph{\texorpdfstring{VL53L4CD\_GetResult()}{VL53L4CD\_GetResult()}}
{\footnotesize\ttfamily VL53\+L4\+CD\+\_\+\+Error VL53\+L4\+CD\+\_\+\+API\+::\+VL53\+L4\+CD\+\_\+\+Get\+Result (\begin{DoxyParamCaption}\item[{\mbox{\hyperlink{structVL53L4CD__LinuxDev}{Dev\+\_\+t}}}]{dev,  }\item[{\mbox{\hyperlink{structVL53L4CD__ResultsData__t}{VL53\+L4\+CD\+\_\+\+Results\+Data\+\_\+t}} $\ast$}]{p\+Result }\end{DoxyParamCaption})}

This function gets the results reported by the sensor. 

\begin{DoxyParams}{Parameters}
{\em (\+Dev\+\_\+t)} & dev \+: instance of selected \mbox{\hyperlink{classVL53L4CD}{VL53\+L4\+CD}} sensor. \\
\hline
{\em (\+VL53\+L4\+CD\+\_\+\+Results\+Data\+\_\+t)} & $\ast$p\+Result \+: Pointer of structure, filled with the ranging results. \\
\hline
\end{DoxyParams}
\begin{DoxyReturn}{Returns}
(uint8\+\_\+t) status \+: 0 if OK. 
\end{DoxyReturn}
\mbox{\Hypertarget{classVL53L4CD__API_a39750d4a46e02e81b5ae0e739def7ed0}\label{classVL53L4CD__API_a39750d4a46e02e81b5ae0e739def7ed0}} 
\index{VL53L4CD\_API@{VL53L4CD\_API}!VL53L4CD\_GetSensorId@{VL53L4CD\_GetSensorId}}
\index{VL53L4CD\_GetSensorId@{VL53L4CD\_GetSensorId}!VL53L4CD\_API@{VL53L4CD\_API}}
\doxyparagraph{\texorpdfstring{VL53L4CD\_GetSensorId()}{VL53L4CD\_GetSensorId()}}
{\footnotesize\ttfamily VL53\+L4\+CD\+\_\+\+Error VL53\+L4\+CD\+\_\+\+API\+::\+VL53\+L4\+CD\+\_\+\+Get\+Sensor\+Id (\begin{DoxyParamCaption}\item[{\mbox{\hyperlink{structVL53L4CD__LinuxDev}{Dev\+\_\+t}}}]{dev,  }\item[{uint16\+\_\+t $\ast$}]{p\+\_\+id }\end{DoxyParamCaption})}

This function is used to get the sensor id of \mbox{\hyperlink{classVL53L4CD}{VL53\+L4\+CD}}. The sensor id should be 0x\+EBAA. 

\begin{DoxyParams}{Parameters}
{\em (\+Dev\+\_\+t)} & dev \+: Device instance. \\
\hline
{\em (uint16\+\_\+t)} & $\ast$p\+\_\+id \+: Sensor id. \\
\hline
\end{DoxyParams}
\begin{DoxyReturn}{Returns}
(VL53\+L4\+CD\+\_\+\+ERROR) status \+: 0 if OK. 
\end{DoxyReturn}
\mbox{\Hypertarget{classVL53L4CD__API_a443fc7e50040da91572b1371f6d23fe1}\label{classVL53L4CD__API_a443fc7e50040da91572b1371f6d23fe1}} 
\index{VL53L4CD\_API@{VL53L4CD\_API}!VL53L4CD\_GetSigmaThreshold@{VL53L4CD\_GetSigmaThreshold}}
\index{VL53L4CD\_GetSigmaThreshold@{VL53L4CD\_GetSigmaThreshold}!VL53L4CD\_API@{VL53L4CD\_API}}
\doxyparagraph{\texorpdfstring{VL53L4CD\_GetSigmaThreshold()}{VL53L4CD\_GetSigmaThreshold()}}
{\footnotesize\ttfamily VL53\+L4\+CD\+\_\+\+Error VL53\+L4\+CD\+\_\+\+API\+::\+VL53\+L4\+CD\+\_\+\+Get\+Sigma\+Threshold (\begin{DoxyParamCaption}\item[{\mbox{\hyperlink{structVL53L4CD__LinuxDev}{Dev\+\_\+t}}}]{dev,  }\item[{uint16\+\_\+t $\ast$}]{p\+\_\+sigma\+\_\+mm }\end{DoxyParamCaption})}

This function gets the current sigma threshold. The sigma corresponds to the standard deviation of the returned pulse. If the computed sigma is above the programmed value, the result status in structure \textquotesingle{}\mbox{\hyperlink{structVL53L4CD__ResultsData__t}{VL53\+L4\+CD\+\_\+\+Results\+Data\+\_\+t}}\textquotesingle{} will be equal to 1. 

\begin{DoxyParams}{Parameters}
{\em (\+Dev\+\_\+t)} & dev \+: instance of selected \mbox{\hyperlink{classVL53L4CD}{VL53\+L4\+CD}} sensor. \\
\hline
{\em (uint16\+\_\+t)} & $\ast$p\+\_\+sigma\+\_\+mm \+: Current sigma threshold in mm. \\
\hline
\end{DoxyParams}
\begin{DoxyReturn}{Returns}
(VL53\+L4\+CD\+\_\+\+ERROR) status \+: 0 if programming is OK. 
\end{DoxyReturn}
\mbox{\Hypertarget{classVL53L4CD__API_ade677c4e4e63c12b1b34fca50180f7a0}\label{classVL53L4CD__API_ade677c4e4e63c12b1b34fca50180f7a0}} 
\index{VL53L4CD\_API@{VL53L4CD\_API}!VL53L4CD\_GetSignalThreshold@{VL53L4CD\_GetSignalThreshold}}
\index{VL53L4CD\_GetSignalThreshold@{VL53L4CD\_GetSignalThreshold}!VL53L4CD\_API@{VL53L4CD\_API}}
\doxyparagraph{\texorpdfstring{VL53L4CD\_GetSignalThreshold()}{VL53L4CD\_GetSignalThreshold()}}
{\footnotesize\ttfamily VL53\+L4\+CD\+\_\+\+Error VL53\+L4\+CD\+\_\+\+API\+::\+VL53\+L4\+CD\+\_\+\+Get\+Signal\+Threshold (\begin{DoxyParamCaption}\item[{\mbox{\hyperlink{structVL53L4CD__LinuxDev}{Dev\+\_\+t}}}]{dev,  }\item[{uint16\+\_\+t $\ast$}]{p\+\_\+signal\+\_\+kcps }\end{DoxyParamCaption})}

This function returns the current signal threshold in kcps. If a target has a lower signal as the programmed value, the result status in structure \textquotesingle{}\mbox{\hyperlink{structVL53L4CD__ResultsData__t}{VL53\+L4\+CD\+\_\+\+Results\+Data\+\_\+t}}\textquotesingle{} will be equal to 2. 

\begin{DoxyParams}{Parameters}
{\em (\+Dev\+\_\+t)} & dev \+: instance of selected \mbox{\hyperlink{classVL53L4CD}{VL53\+L4\+CD}} sensor. \\
\hline
{\em (uint16\+\_\+t)} & $\ast$p\+\_\+signal\+\_\+kcps \+: Pointer of signal threshold in kcps. \\
\hline
\end{DoxyParams}
\begin{DoxyReturn}{Returns}
(VL53\+L4\+CD\+\_\+\+ERROR) status \+: 0 if OK. 
\end{DoxyReturn}
\mbox{\Hypertarget{classVL53L4CD__API_a2e522cd6d66becb6315fb2fa50a00055}\label{classVL53L4CD__API_a2e522cd6d66becb6315fb2fa50a00055}} 
\index{VL53L4CD\_API@{VL53L4CD\_API}!VL53L4CD\_GetSWVersion@{VL53L4CD\_GetSWVersion}}
\index{VL53L4CD\_GetSWVersion@{VL53L4CD\_GetSWVersion}!VL53L4CD\_API@{VL53L4CD\_API}}
\doxyparagraph{\texorpdfstring{VL53L4CD\_GetSWVersion()}{VL53L4CD\_GetSWVersion()}}
{\footnotesize\ttfamily VL53\+L4\+CD\+\_\+\+Error VL53\+L4\+CD\+\_\+\+API\+::\+VL53\+L4\+CD\+\_\+\+Get\+SWVersion (\begin{DoxyParamCaption}\item[{\mbox{\hyperlink{structVL53L4CD__Version__t}{VL53\+L4\+CD\+\_\+\+Version\+\_\+t}} $\ast$}]{p\+Version }\end{DoxyParamCaption})}

This function programs the software driver version. 

\begin{DoxyParams}{Parameters}
{\em (\+VL53\+L4\+CD\+\_\+\+Version\+\_\+t)} & p\+Version \+: Pointer of structure, containing the software version. \\
\hline
\end{DoxyParams}
\begin{DoxyReturn}{Returns}
(VL53\+L4\+CD\+\_\+\+ERROR) status \+: 0 if SW version is OK. 
\end{DoxyReturn}
\mbox{\Hypertarget{classVL53L4CD__API_a0a42e28fc1e58cc1708d3a9b49563f03}\label{classVL53L4CD__API_a0a42e28fc1e58cc1708d3a9b49563f03}} 
\index{VL53L4CD\_API@{VL53L4CD\_API}!VL53L4CD\_GetXtalk@{VL53L4CD\_GetXtalk}}
\index{VL53L4CD\_GetXtalk@{VL53L4CD\_GetXtalk}!VL53L4CD\_API@{VL53L4CD\_API}}
\doxyparagraph{\texorpdfstring{VL53L4CD\_GetXtalk()}{VL53L4CD\_GetXtalk()}}
{\footnotesize\ttfamily VL53\+L4\+CD\+\_\+\+Error VL53\+L4\+CD\+\_\+\+API\+::\+VL53\+L4\+CD\+\_\+\+Get\+Xtalk (\begin{DoxyParamCaption}\item[{\mbox{\hyperlink{structVL53L4CD__LinuxDev}{Dev\+\_\+t}}}]{dev,  }\item[{uint16\+\_\+t $\ast$}]{p\+\_\+xtalk\+\_\+kcps }\end{DoxyParamCaption})}

This function gets the current Xtalk value in kcps. Xtalk represents the correction to apply to the sensor when a protective coverglass is placed at the top of the sensor. 

\begin{DoxyParams}{Parameters}
{\em (\+Dev\+\_\+t)} & dev \+: instance of selected \mbox{\hyperlink{classVL53L4CD}{VL53\+L4\+CD}} sensor. \\
\hline
{\em (uint16\+\_\+t)} & p\+\_\+xtalk\+\_\+kcps \+: Pointer of current xtalk value in kcps. \\
\hline
\end{DoxyParams}
\begin{DoxyReturn}{Returns}
(VL53\+L4\+CD\+\_\+\+ERROR) status \+: 0 if OK. 
\end{DoxyReturn}
\mbox{\Hypertarget{classVL53L4CD__API_ad04915d4dc676f2306874b75a670c091}\label{classVL53L4CD__API_ad04915d4dc676f2306874b75a670c091}} 
\index{VL53L4CD\_API@{VL53L4CD\_API}!VL53L4CD\_SensorInit@{VL53L4CD\_SensorInit}}
\index{VL53L4CD\_SensorInit@{VL53L4CD\_SensorInit}!VL53L4CD\_API@{VL53L4CD\_API}}
\doxyparagraph{\texorpdfstring{VL53L4CD\_SensorInit()}{VL53L4CD\_SensorInit()}}
{\footnotesize\ttfamily VL53\+L4\+CD\+\_\+\+Error VL53\+L4\+CD\+\_\+\+API\+::\+VL53\+L4\+CD\+\_\+\+Sensor\+Init (\begin{DoxyParamCaption}\item[{\mbox{\hyperlink{structVL53L4CD__LinuxDev}{Dev\+\_\+t}}}]{dev }\end{DoxyParamCaption})}

This function is used to initialize the sensor. 

\begin{DoxyParams}{Parameters}
{\em (\+Dev\+\_\+t)} & dev \+: Device instance to initialize. \\
\hline
\end{DoxyParams}
\begin{DoxyReturn}{Returns}
(VL53\+L4\+CD\+\_\+\+ERROR) status \+: 0 if init is OK. 
\end{DoxyReturn}
\mbox{\Hypertarget{classVL53L4CD__API_a4d9a651e5194e5daa081085c6691642f}\label{classVL53L4CD__API_a4d9a651e5194e5daa081085c6691642f}} 
\index{VL53L4CD\_API@{VL53L4CD\_API}!VL53L4CD\_SetDetectionThresholds@{VL53L4CD\_SetDetectionThresholds}}
\index{VL53L4CD\_SetDetectionThresholds@{VL53L4CD\_SetDetectionThresholds}!VL53L4CD\_API@{VL53L4CD\_API}}
\doxyparagraph{\texorpdfstring{VL53L4CD\_SetDetectionThresholds()}{VL53L4CD\_SetDetectionThresholds()}}
{\footnotesize\ttfamily VL53\+L4\+CD\+\_\+\+Error VL53\+L4\+CD\+\_\+\+API\+::\+VL53\+L4\+CD\+\_\+\+Set\+Detection\+Thresholds (\begin{DoxyParamCaption}\item[{\mbox{\hyperlink{structVL53L4CD__LinuxDev}{Dev\+\_\+t}}}]{dev,  }\item[{uint16\+\_\+t}]{distance\+\_\+low\+\_\+mm,  }\item[{uint16\+\_\+t}]{distance\+\_\+high\+\_\+mm,  }\item[{uint8\+\_\+t}]{window }\end{DoxyParamCaption})}

This function sets new detection thresholds. The detection thresholds can be programmed to generate an interrupt on pin 7 (GPIO1), only when a condition on distance is reach. Example\+: VL53\+L4\+CD\+\_\+\+Set\+Distance\+Threshold(dev,100,300,0)\+: Below 100 mm VL53\+L4\+CD\+\_\+\+Set\+Distance\+Threshold(dev,100,300,1)\+: Above 300 mm VL53\+L4\+CD\+\_\+\+Set\+Distance\+Threshold(dev,100,300,2)\+: Below 100mm or above 300mm VL53\+L4\+CD\+\_\+\+Set\+Distance\+Threshold(dev,100,300,3)\+: Above 100mm or below 300mm. 

\begin{DoxyParams}{Parameters}
{\em (\+Dev\+\_\+t)} & dev \+: instance of selected \mbox{\hyperlink{classVL53L4CD}{VL53\+L4\+CD}} sensor. \\
\hline
{\em (uint16\+\_\+t)} & distance\+\_\+low\+\_\+mm \+: Low distance threshold in millimeters. \\
\hline
{\em (uint16\+\_\+t)} & distance\+\_\+high\+\_\+mm \+: High distance threshold in millimeters. \\
\hline
{\em (uint8\+\_\+t)} & window \+: Interrupt windows (0=below low threshold; 1=above high threshold; 2=out of low/high windows; 3=in low/high windows) \\
\hline
\end{DoxyParams}
\begin{DoxyReturn}{Returns}
(VL53\+L4\+CD\+\_\+\+ERROR) status \+: 0 if OK. 
\end{DoxyReturn}
\mbox{\Hypertarget{classVL53L4CD__API_a87523f5f80914c5712bbb2d9714b6267}\label{classVL53L4CD__API_a87523f5f80914c5712bbb2d9714b6267}} 
\index{VL53L4CD\_API@{VL53L4CD\_API}!VL53L4CD\_SetI2CAddress@{VL53L4CD\_SetI2CAddress}}
\index{VL53L4CD\_SetI2CAddress@{VL53L4CD\_SetI2CAddress}!VL53L4CD\_API@{VL53L4CD\_API}}
\doxyparagraph{\texorpdfstring{VL53L4CD\_SetI2CAddress()}{VL53L4CD\_SetI2CAddress()}}
{\footnotesize\ttfamily VL53\+L4\+CD\+\_\+\+Error VL53\+L4\+CD\+\_\+\+API\+::\+VL53\+L4\+CD\+\_\+\+Set\+I2\+CAddress (\begin{DoxyParamCaption}\item[{\mbox{\hyperlink{structVL53L4CD__LinuxDev}{Dev\+\_\+t}}}]{dev,  }\item[{uint8\+\_\+t}]{new\+\_\+address }\end{DoxyParamCaption})}

This function sets a new I2C address to a sensor. It can be used for example when multiple sensors share the same I2C bus. 

\begin{DoxyParams}{Parameters}
{\em (\+Dev\+\_\+t)} & dev \+: Device instance to update. \\
\hline
{\em (uint8\+\_\+t)} & new\+\_\+address \+: New I2C address. \\
\hline
\end{DoxyParams}
\begin{DoxyReturn}{Returns}
(VL53\+L4\+CD\+\_\+\+ERROR) status \+: 0 if I2C address has been correctly programmed. 
\end{DoxyReturn}
\mbox{\Hypertarget{classVL53L4CD__API_a4cd4dc976d343d0cff8696ea60a1068d}\label{classVL53L4CD__API_a4cd4dc976d343d0cff8696ea60a1068d}} 
\index{VL53L4CD\_API@{VL53L4CD\_API}!VL53L4CD\_SetOffset@{VL53L4CD\_SetOffset}}
\index{VL53L4CD\_SetOffset@{VL53L4CD\_SetOffset}!VL53L4CD\_API@{VL53L4CD\_API}}
\doxyparagraph{\texorpdfstring{VL53L4CD\_SetOffset()}{VL53L4CD\_SetOffset()}}
{\footnotesize\ttfamily VL53\+L4\+CD\+\_\+\+Error VL53\+L4\+CD\+\_\+\+API\+::\+VL53\+L4\+CD\+\_\+\+Set\+Offset (\begin{DoxyParamCaption}\item[{\mbox{\hyperlink{structVL53L4CD__LinuxDev}{Dev\+\_\+t}}}]{dev,  }\item[{int16\+\_\+t}]{Offset\+Value\+In\+Mm }\end{DoxyParamCaption})}

This function sets a new offset correction in mm. Offset corresponds to the difference in millimeters between real distance and measured distance. 

\begin{DoxyParams}{Parameters}
{\em (\+Dev\+\_\+t)} & dev \+: instance of selected \mbox{\hyperlink{classVL53L4CD}{VL53\+L4\+CD}} sensor. \\
\hline
{\em (int16\+\_\+t)} & Offset\+Value\+In\+Mm \+: Offset value in millimeters. The minimum value is -\/1024mm and maximum is 1023mm. \\
\hline
\end{DoxyParams}
\begin{DoxyReturn}{Returns}
(uint8\+\_\+t) status \+: 0 if OK. 
\end{DoxyReturn}
\mbox{\Hypertarget{classVL53L4CD__API_a2585a3f22fdf2b0ee32820ec42da3961}\label{classVL53L4CD__API_a2585a3f22fdf2b0ee32820ec42da3961}} 
\index{VL53L4CD\_API@{VL53L4CD\_API}!VL53L4CD\_SetRangeTiming@{VL53L4CD\_SetRangeTiming}}
\index{VL53L4CD\_SetRangeTiming@{VL53L4CD\_SetRangeTiming}!VL53L4CD\_API@{VL53L4CD\_API}}
\doxyparagraph{\texorpdfstring{VL53L4CD\_SetRangeTiming()}{VL53L4CD\_SetRangeTiming()}}
{\footnotesize\ttfamily VL53\+L4\+CD\+\_\+\+Error VL53\+L4\+CD\+\_\+\+API\+::\+VL53\+L4\+CD\+\_\+\+Set\+Range\+Timing (\begin{DoxyParamCaption}\item[{\mbox{\hyperlink{structVL53L4CD__LinuxDev}{Dev\+\_\+t}}}]{dev,  }\item[{uint32\+\_\+t}]{timing\+\_\+budget\+\_\+ms,  }\item[{uint32\+\_\+t}]{inter\+\_\+measurement\+\_\+ms }\end{DoxyParamCaption})}

This function sets new range timing. Timing are composed of Timing\+Budget and Inter\+Measurement. Timing\+Budget represents the timing during VCSEL enabled, and Inter\+Measurement the time between two measurements. The sensor can have different ranging mode depending of the configuration, please refer to the user manual for more information. 

\begin{DoxyParams}{Parameters}
{\em (\+Dev\+\_\+t)} & dev \+: instance of selected \mbox{\hyperlink{classVL53L4CD}{VL53\+L4\+CD}} sensor. \\
\hline
{\em (uint32\+\_\+t)} & timing\+\_\+budget\+\_\+ms \+: New timing budget in ms. Value can be between 10ms and 200ms. Default is 50ms. \\
\hline
{\em (uint32\+\_\+t)} & inter\+\_\+measurement\+\_\+ms \+: New inter-\/measurement in ms. If the value is equal to 0, the ranging period is defined by the timing budget. Otherwise, inter-\/measurement must be \texorpdfstring{$>$}{>} timing budget. When all the timing budget is consumed, the device goes in low power mode until inter-\/measurement is done. \\
\hline
\end{DoxyParams}
\begin{DoxyReturn}{Returns}
(uint8\+\_\+t) status \+: 0 if OK. 
\end{DoxyReturn}
\mbox{\Hypertarget{classVL53L4CD__API_ada4fb4ff20dacbed66e6c5261e4ff813}\label{classVL53L4CD__API_ada4fb4ff20dacbed66e6c5261e4ff813}} 
\index{VL53L4CD\_API@{VL53L4CD\_API}!VL53L4CD\_SetSigmaThreshold@{VL53L4CD\_SetSigmaThreshold}}
\index{VL53L4CD\_SetSigmaThreshold@{VL53L4CD\_SetSigmaThreshold}!VL53L4CD\_API@{VL53L4CD\_API}}
\doxyparagraph{\texorpdfstring{VL53L4CD\_SetSigmaThreshold()}{VL53L4CD\_SetSigmaThreshold()}}
{\footnotesize\ttfamily VL53\+L4\+CD\+\_\+\+Error VL53\+L4\+CD\+\_\+\+API\+::\+VL53\+L4\+CD\+\_\+\+Set\+Sigma\+Threshold (\begin{DoxyParamCaption}\item[{\mbox{\hyperlink{structVL53L4CD__LinuxDev}{Dev\+\_\+t}}}]{dev,  }\item[{uint16\+\_\+t}]{sigma\+\_\+mm }\end{DoxyParamCaption})}

This function programs a new sigma threshold. The sigma corresponds to the standard deviation of the returned pulse. If the computed sigma is above the programmed value, the result status in structure \textquotesingle{}\mbox{\hyperlink{structVL53L4CD__ResultsData__t}{VL53\+L4\+CD\+\_\+\+Results\+Data\+\_\+t}}\textquotesingle{} will be equal to 1. 

\begin{DoxyParams}{Parameters}
{\em (\+Dev\+\_\+t)} & dev \+: instance of selected \mbox{\hyperlink{classVL53L4CD}{VL53\+L4\+CD}} sensor. \\
\hline
{\em (uint16\+\_\+t)} & sigma\+\_\+mm \+: New sigma threshold in mm. The default value is 15mm. Minimum is 0mm (not threshold), and maximum is 16383mm. \\
\hline
\end{DoxyParams}
\begin{DoxyReturn}{Returns}
(VL53\+L4\+CD\+\_\+\+ERROR) status \+: 0 if programming is or 255 if value is too high. 
\end{DoxyReturn}
\mbox{\Hypertarget{classVL53L4CD__API_a115c3de908fb7b9dbfcf91bdac6a551c}\label{classVL53L4CD__API_a115c3de908fb7b9dbfcf91bdac6a551c}} 
\index{VL53L4CD\_API@{VL53L4CD\_API}!VL53L4CD\_SetSignalThreshold@{VL53L4CD\_SetSignalThreshold}}
\index{VL53L4CD\_SetSignalThreshold@{VL53L4CD\_SetSignalThreshold}!VL53L4CD\_API@{VL53L4CD\_API}}
\doxyparagraph{\texorpdfstring{VL53L4CD\_SetSignalThreshold()}{VL53L4CD\_SetSignalThreshold()}}
{\footnotesize\ttfamily VL53\+L4\+CD\+\_\+\+Error VL53\+L4\+CD\+\_\+\+API\+::\+VL53\+L4\+CD\+\_\+\+Set\+Signal\+Threshold (\begin{DoxyParamCaption}\item[{\mbox{\hyperlink{structVL53L4CD__LinuxDev}{Dev\+\_\+t}}}]{dev,  }\item[{uint16\+\_\+t}]{signal\+\_\+kcps }\end{DoxyParamCaption})}

This function sets a new signal threshold in kcps. If a target has a lower signal as the programmed value, the result status in structure \textquotesingle{}\mbox{\hyperlink{structVL53L4CD__ResultsData__t}{VL53\+L4\+CD\+\_\+\+Results\+Data\+\_\+t}}\textquotesingle{} will be equal to 2. 

\begin{DoxyParams}{Parameters}
{\em (\+Dev\+\_\+t)} & dev \+: instance of selected \mbox{\hyperlink{classVL53L4CD}{VL53\+L4\+CD}} sensor. \\
\hline
{\em (uint16\+\_\+t)} & signal\+\_\+kcps \+: New signal threshold in kcps. The default value is 1024 kcps. Minimum is 0 kcps (no threshold), and maximum is 16384 kcps. \\
\hline
\end{DoxyParams}
\begin{DoxyReturn}{Returns}
(VL53\+L4\+CD\+\_\+\+ERROR) status \+: 0 if OK. 
\end{DoxyReturn}
\mbox{\Hypertarget{classVL53L4CD__API_a1e02c0ae9a798c8972e84cb22b3c4a06}\label{classVL53L4CD__API_a1e02c0ae9a798c8972e84cb22b3c4a06}} 
\index{VL53L4CD\_API@{VL53L4CD\_API}!VL53L4CD\_SetXtalk@{VL53L4CD\_SetXtalk}}
\index{VL53L4CD\_SetXtalk@{VL53L4CD\_SetXtalk}!VL53L4CD\_API@{VL53L4CD\_API}}
\doxyparagraph{\texorpdfstring{VL53L4CD\_SetXtalk()}{VL53L4CD\_SetXtalk()}}
{\footnotesize\ttfamily VL53\+L4\+CD\+\_\+\+Error VL53\+L4\+CD\+\_\+\+API\+::\+VL53\+L4\+CD\+\_\+\+Set\+Xtalk (\begin{DoxyParamCaption}\item[{\mbox{\hyperlink{structVL53L4CD__LinuxDev}{Dev\+\_\+t}}}]{dev,  }\item[{uint16\+\_\+t}]{Xtalk\+Value\+Kcps }\end{DoxyParamCaption})}

This function sets a new Xtalk value in kcps. Xtalk represents the correction to apply to the sensor when a protective coverglass is placed at the top of the sensor. 

\begin{DoxyParams}{Parameters}
{\em (\+Dev\+\_\+t)} & dev \+: instance of selected \mbox{\hyperlink{classVL53L4CD}{VL53\+L4\+CD}} sensor. \\
\hline
{\em (uint16\+\_\+t)} & Xtalk\+Value\+Kcps \+: New xtalk value in kcps. The default value is 0 kcps (no coverglass). Minimum is 0 kcps , and maximum is 128 kcps. \\
\hline
\end{DoxyParams}
\begin{DoxyReturn}{Returns}
(VL53\+L4\+CD\+\_\+\+ERROR) status \+: 0 if OK. 
\end{DoxyReturn}
\mbox{\Hypertarget{classVL53L4CD__API_a3013012a08e2592d13653a267806c98c}\label{classVL53L4CD__API_a3013012a08e2592d13653a267806c98c}} 
\index{VL53L4CD\_API@{VL53L4CD\_API}!VL53L4CD\_StartRanging@{VL53L4CD\_StartRanging}}
\index{VL53L4CD\_StartRanging@{VL53L4CD\_StartRanging}!VL53L4CD\_API@{VL53L4CD\_API}}
\doxyparagraph{\texorpdfstring{VL53L4CD\_StartRanging()}{VL53L4CD\_StartRanging()}}
{\footnotesize\ttfamily VL53\+L4\+CD\+\_\+\+Error VL53\+L4\+CD\+\_\+\+API\+::\+VL53\+L4\+CD\+\_\+\+Start\+Ranging (\begin{DoxyParamCaption}\item[{\mbox{\hyperlink{structVL53L4CD__LinuxDev}{Dev\+\_\+t}}}]{dev }\end{DoxyParamCaption})}

This function starts a ranging session. The ranging operation is continuous. The clear interrupt has to be done after each get data to allow the interrupt to raise when the next data is ready. 

\begin{DoxyParams}{Parameters}
{\em (\+Dev\+\_\+t)} & dev \+: instance of selected \mbox{\hyperlink{classVL53L4CD}{VL53\+L4\+CD}} sensor. \\
\hline
\end{DoxyParams}
\begin{DoxyReturn}{Returns}
(VL53\+L4\+CD\+\_\+\+ERROR) status \+: 0 if OK. 
\end{DoxyReturn}
\mbox{\Hypertarget{classVL53L4CD__API_aa9c83b64bcfbb37376b0694c64745564}\label{classVL53L4CD__API_aa9c83b64bcfbb37376b0694c64745564}} 
\index{VL53L4CD\_API@{VL53L4CD\_API}!VL53L4CD\_StartTemperatureUpdate@{VL53L4CD\_StartTemperatureUpdate}}
\index{VL53L4CD\_StartTemperatureUpdate@{VL53L4CD\_StartTemperatureUpdate}!VL53L4CD\_API@{VL53L4CD\_API}}
\doxyparagraph{\texorpdfstring{VL53L4CD\_StartTemperatureUpdate()}{VL53L4CD\_StartTemperatureUpdate()}}
{\footnotesize\ttfamily VL53\+L4\+CD\+\_\+\+Error VL53\+L4\+CD\+\_\+\+API\+::\+VL53\+L4\+CD\+\_\+\+Start\+Temperature\+Update (\begin{DoxyParamCaption}\item[{\mbox{\hyperlink{structVL53L4CD__LinuxDev}{Dev\+\_\+t}}}]{dev }\end{DoxyParamCaption})}

This function can be called when the temperature might have changed by more than 8 degrees Celsius. The function can only be used if the sensor is not ranging, otherwise, the ranging needs to be stopped using function \textquotesingle{}\mbox{\hyperlink{classVL53L4CD__API_a491af0b13c9fa2c9e3197b80c2f50f8b}{VL53\+L4\+CD\+\_\+\+Stop\+Ranging()}}\textquotesingle{}. After calling this function, the ranging can restart normally. 

\begin{DoxyParams}{Parameters}
{\em (\+Dev\+\_\+t)} & dev \+: instance of selected \mbox{\hyperlink{classVL53L4CD}{VL53\+L4\+CD}} sensor. \\
\hline
\end{DoxyParams}
\begin{DoxyReturn}{Returns}
(VL53\+L4\+CD\+\_\+\+ERROR) status \+: 0 if update is OK. 
\end{DoxyReturn}
\mbox{\Hypertarget{classVL53L4CD__API_a491af0b13c9fa2c9e3197b80c2f50f8b}\label{classVL53L4CD__API_a491af0b13c9fa2c9e3197b80c2f50f8b}} 
\index{VL53L4CD\_API@{VL53L4CD\_API}!VL53L4CD\_StopRanging@{VL53L4CD\_StopRanging}}
\index{VL53L4CD\_StopRanging@{VL53L4CD\_StopRanging}!VL53L4CD\_API@{VL53L4CD\_API}}
\doxyparagraph{\texorpdfstring{VL53L4CD\_StopRanging()}{VL53L4CD\_StopRanging()}}
{\footnotesize\ttfamily VL53\+L4\+CD\+\_\+\+Error VL53\+L4\+CD\+\_\+\+API\+::\+VL53\+L4\+CD\+\_\+\+Stop\+Ranging (\begin{DoxyParamCaption}\item[{\mbox{\hyperlink{structVL53L4CD__LinuxDev}{Dev\+\_\+t}}}]{dev }\end{DoxyParamCaption})}

This function stops the ranging in progress. 

\begin{DoxyParams}{Parameters}
{\em (\+Dev\+\_\+t)} & dev \+: instance of selected \mbox{\hyperlink{classVL53L4CD}{VL53\+L4\+CD}} sensor. \\
\hline
\end{DoxyParams}
\begin{DoxyReturn}{Returns}
(VL53\+L4\+CD\+\_\+\+ERROR) status \+: 0 if OK. 
\end{DoxyReturn}

The documentation for this class was generated from the following file\+:\begin{DoxyCompactItemize}
\item 
include/VL53\+L4\+CD\+\_\+api.\+h\end{DoxyCompactItemize}

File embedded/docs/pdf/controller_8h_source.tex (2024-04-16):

\hypertarget{controller_8h_source}{}\doxysubsection{controller.\+h}
\label{controller_8h_source}\index{include/controller.h@{include/controller.h}}

\begin{DoxyCode}{0}
\DoxyCodeLine{1 \textcolor{comment}{/****************************** Module Header ******************************\(\backslash\)}}
\DoxyCodeLine{2 \textcolor{comment}{Module Name:    controller.h}}
\DoxyCodeLine{3 \textcolor{comment}{Project:        btb}}
\DoxyCodeLine{4 \textcolor{comment}{Author:         Grant Maiden}}
\DoxyCodeLine{5 \textcolor{comment}{Description:    System controller state machine}}
\DoxyCodeLine{6 \textcolor{comment}{\(\backslash\)***************************************************************************/}}
\DoxyCodeLine{7 \textcolor{preprocessor}{\#ifndef CONTROLLER\_H}}
\DoxyCodeLine{8 \textcolor{preprocessor}{\#define CONTROLLER\_H}}
\DoxyCodeLine{9 }
\DoxyCodeLine{10 \textcolor{preprocessor}{\#include <pigpio.h>}}
\DoxyCodeLine{11 }
\DoxyCodeLine{12 \textcolor{preprocessor}{\#define LIGHT\_HIT       3}}
\DoxyCodeLine{13 \textcolor{preprocessor}{\#define MEDIUM\_HIT      7}}
\DoxyCodeLine{14 \textcolor{preprocessor}{\#define HARD\_HIT        10}}
\DoxyCodeLine{15 }
\DoxyCodeLine{16 \textcolor{comment}{// Distance Filtering}}
\DoxyCodeLine{17 \textcolor{preprocessor}{\#define DISTANCE\_UPPER\_THRESHOLD            600}}
\DoxyCodeLine{18 }
\DoxyCodeLine{19 \textcolor{comment}{// Velocity array control}}
\DoxyCodeLine{20 \textcolor{preprocessor}{\#define VELOCITY\_FACTOR\_AVG                 3}}
\DoxyCodeLine{21 \textcolor{preprocessor}{\#define PAST\_AVERAGE\_VELOCITY\_ARR\_SIZE      16}}
\DoxyCodeLine{22 }
\DoxyCodeLine{23 \textcolor{comment}{// Hit Detection}}
\DoxyCodeLine{24 \textcolor{preprocessor}{\#define HIT\_DETECT\_NOISE\_CHECKING                   true}}
\DoxyCodeLine{25 \textcolor{preprocessor}{\#define HIT\_DETECT\_NUM\_SAMPLES\_MIN                  8}}
\DoxyCodeLine{26 \textcolor{preprocessor}{\#define DRUM\_INTERVAL\_TIMEOUT\_MS                    120}}
\DoxyCodeLine{27 \textcolor{preprocessor}{\#define HIT\_DETECT\_INSTANEOUS\_VELOCITY\_LIMIT        100}}
\DoxyCodeLine{28 \textcolor{preprocessor}{\#define HIT\_DETECT\_AVG\_VELOCITY\_CEILING             25}}
\DoxyCodeLine{29 \textcolor{preprocessor}{\#define HIT\_DETECT\_MIN\_SEQUENTIAL\_VELOCITY\_SAMPLES  6}}
\DoxyCodeLine{30 }
\DoxyCodeLine{31 \textcolor{comment}{// Sensor Detection Direction (-\/1 = towards sensor, 1 = away from sensor)}}
\DoxyCodeLine{32 \textcolor{preprocessor}{\#define SENSOR1\_6\_DIRECTION                 1}}
\DoxyCodeLine{33 \textcolor{preprocessor}{\#define SENSOR2\_3\_4\_5\_DIRECTION             -\/1}}
\DoxyCodeLine{34 }
\DoxyCodeLine{35 \textcolor{comment}{// Gestures}}
\DoxyCodeLine{36 \textcolor{preprocessor}{\#define GESTURE\_THRESHOLD\_VELOCITY          6}}
\DoxyCodeLine{37 \textcolor{preprocessor}{\#define GESTURE\_THRESHOLD\_NUM\_SAMPLE\_TRUE   4}}
\DoxyCodeLine{38 \textcolor{preprocessor}{\#define GESTURE\_TIME\_LIMIT                  1}}
\DoxyCodeLine{39 }
\DoxyCodeLine{40 }
\DoxyCodeLine{44 \textcolor{keyword}{typedef} \textcolor{keyword}{enum}}
\DoxyCodeLine{45 \{}
\DoxyCodeLine{46     RESET,}
\DoxyCodeLine{47     WAIT1,}
\DoxyCodeLine{48     POLLING1,}
\DoxyCodeLine{49     TEST\_DISTANCE\_SENSORS,}
\DoxyCodeLine{50 \}controllerState;}
\DoxyCodeLine{51 }
\DoxyCodeLine{55 \textcolor{keyword}{typedef} \textcolor{keyword}{struct}}
\DoxyCodeLine{56 \{}
\DoxyCodeLine{57     sensorID sensor;}
\DoxyCodeLine{58     \textcolor{keywordtype}{int} hitStrength;}
\DoxyCodeLine{59 \}\mbox{\hyperlink{structsensorHit}{sensorHit}};}
\DoxyCodeLine{60 }
\DoxyCodeLine{61 }
\DoxyCodeLine{62 \textcolor{keyword}{using namespace }std;}
\DoxyCodeLine{63 \textcolor{keyword}{class }\mbox{\hyperlink{classController}{Controller}} : \textcolor{keyword}{public} \mbox{\hyperlink{classVL53L4CD}{VL53L4CD}}}
\DoxyCodeLine{64 \{}
\DoxyCodeLine{65     \textcolor{keyword}{public}:}
\DoxyCodeLine{66         \textcolor{keyword}{virtual} \textcolor{keywordtype}{void} \mbox{\hyperlink{classController_af53bfa42e907627e5f39668e3d8acb5c}{distanceDataReady}}(\mbox{\hyperlink{structsensorValues}{sensorValues}} sensVals, sensorID sensor)}
\DoxyCodeLine{67         \{}
\DoxyCodeLine{68             \mbox{\hyperlink{classController_a6a4dff110a9530bb905f0b7fab9bd819}{updateSensorValue}}(sensVals, sensor);}
\DoxyCodeLine{69             \mbox{\hyperlink{classController_adddce8023c6beb72400ec1ead2629e66}{primaryStateMachine}}();}
\DoxyCodeLine{70         \}}
\DoxyCodeLine{71 }
\DoxyCodeLine{75         \textcolor{keywordtype}{void} \mbox{\hyperlink{classController_a28d5755bc8fed07cebd88f857f0f83df}{initialize}}();}
\DoxyCodeLine{76 }
\DoxyCodeLine{80         \textcolor{keywordtype}{void} \mbox{\hyperlink{classController_adddce8023c6beb72400ec1ead2629e66}{primaryStateMachine}}();}
\DoxyCodeLine{81 }
\DoxyCodeLine{85         \textcolor{keywordtype}{void} \mbox{\hyperlink{classController_a0676fa7d920a0984d3920bcf27401a0f}{updateState}}(controllerState newState);}
\DoxyCodeLine{86 }
\DoxyCodeLine{92         \textcolor{keywordtype}{void} \mbox{\hyperlink{classController_a6a4dff110a9530bb905f0b7fab9bd819}{updateSensorValue}}(\mbox{\hyperlink{structsensorValues}{sensorValues}} senseValue, sensorID \textcolor{keywordtype}{id});}
\DoxyCodeLine{93 }
\DoxyCodeLine{94 \textcolor{comment}{//        /**}}
\DoxyCodeLine{95 \textcolor{comment}{//         * isrCallback}}
\DoxyCodeLine{96 \textcolor{comment}{//         **/}}
\DoxyCodeLine{97 \textcolor{comment}{//        static void isrCallback(void*obj);}}
\DoxyCodeLine{98 \textcolor{comment}{//}}
\DoxyCodeLine{99 \textcolor{comment}{//        /**}}
\DoxyCodeLine{100 \textcolor{comment}{//         * Callback that is triggered on DistanceSensors Interrupt Falling Edge.}}
\DoxyCodeLine{101 \textcolor{comment}{//         * \(\backslash\)param gpio -\/ int gpio Triggered Gpio number}}
\DoxyCodeLine{102 \textcolor{comment}{//         * \(\backslash\)param level -\/ int level GPIO input level at time of ISR}}
\DoxyCodeLine{103 \textcolor{comment}{//         * \(\backslash\)param tick -\/ uint32\_t trigger time in microseconds.}}
\DoxyCodeLine{104 \textcolor{comment}{//         **/}}
\DoxyCodeLine{105 \textcolor{comment}{//        static void rangingISRCallback(int gpio, int level, uint32\_t tick);}}
\DoxyCodeLine{106 }
\DoxyCodeLine{107     \textcolor{keyword}{private}:}
\DoxyCodeLine{108         controllerState currentState = RESET;}
\DoxyCodeLine{109         controllerState nextState = currentState;}
\DoxyCodeLine{110 }
\DoxyCodeLine{111         \mbox{\hyperlink{structsensorValues}{sensorValues}} sens1Values;}
\DoxyCodeLine{112         \mbox{\hyperlink{structsensorValues}{sensorValues}} sens2Values;}
\DoxyCodeLine{113         \mbox{\hyperlink{structsensorValues}{sensorValues}} sens3Values;}
\DoxyCodeLine{114         \mbox{\hyperlink{structsensorValues}{sensorValues}} sens4Values;}
\DoxyCodeLine{115         \mbox{\hyperlink{structsensorValues}{sensorValues}} sens5Values;}
\DoxyCodeLine{116         \mbox{\hyperlink{structsensorValues}{sensorValues}} sens6Values;}
\DoxyCodeLine{117 }
\DoxyCodeLine{118         \textcolor{keywordtype}{int} * averageVelArrSens1 = \textcolor{keyword}{new} \textcolor{keywordtype}{int}[PAST\_AVERAGE\_VELOCITY\_ARR\_SIZE]();}
\DoxyCodeLine{119         \textcolor{keywordtype}{int} * averageVelArrSens2 = \textcolor{keyword}{new} \textcolor{keywordtype}{int}[PAST\_AVERAGE\_VELOCITY\_ARR\_SIZE]();}
\DoxyCodeLine{120         \textcolor{keywordtype}{int} * averageVelArrSens3 = \textcolor{keyword}{new} \textcolor{keywordtype}{int}[PAST\_AVERAGE\_VELOCITY\_ARR\_SIZE]();}
\DoxyCodeLine{121         \textcolor{keywordtype}{int} * averageVelArrSens4 = \textcolor{keyword}{new} \textcolor{keywordtype}{int}[PAST\_AVERAGE\_VELOCITY\_ARR\_SIZE]();}
\DoxyCodeLine{122         \textcolor{keywordtype}{int} * averageVelArrSens5 = \textcolor{keyword}{new} \textcolor{keywordtype}{int}[PAST\_AVERAGE\_VELOCITY\_ARR\_SIZE]();}
\DoxyCodeLine{123         \textcolor{keywordtype}{int} * averageVelArrSens6 = \textcolor{keyword}{new} \textcolor{keywordtype}{int}[PAST\_AVERAGE\_VELOCITY\_ARR\_SIZE]();}
\DoxyCodeLine{124 }
\DoxyCodeLine{125         \textcolor{keywordtype}{int} * currentVelArrSens1 = \textcolor{keyword}{new} \textcolor{keywordtype}{int}[PAST\_AVERAGE\_VELOCITY\_ARR\_SIZE]();}
\DoxyCodeLine{126         \textcolor{keywordtype}{int} * currentVelArrSens2 = \textcolor{keyword}{new} \textcolor{keywordtype}{int}[PAST\_AVERAGE\_VELOCITY\_ARR\_SIZE]();}
\DoxyCodeLine{127         \textcolor{keywordtype}{int} * currentVelArrSens3 = \textcolor{keyword}{new} \textcolor{keywordtype}{int}[PAST\_AVERAGE\_VELOCITY\_ARR\_SIZE]();}
\DoxyCodeLine{128         \textcolor{keywordtype}{int} * currentVelArrSens4 = \textcolor{keyword}{new} \textcolor{keywordtype}{int}[PAST\_AVERAGE\_VELOCITY\_ARR\_SIZE]();}
\DoxyCodeLine{129         \textcolor{keywordtype}{int} * currentVelArrSens5 = \textcolor{keyword}{new} \textcolor{keywordtype}{int}[PAST\_AVERAGE\_VELOCITY\_ARR\_SIZE]();}
\DoxyCodeLine{130         \textcolor{keywordtype}{int} * currentVelArrSens6 = \textcolor{keyword}{new} \textcolor{keywordtype}{int}[PAST\_AVERAGE\_VELOCITY\_ARR\_SIZE]();}
\DoxyCodeLine{131 }
\DoxyCodeLine{132         \textcolor{keywordtype}{int} averageVelNextArrIndex = 0;}
\DoxyCodeLine{133         \textcolor{keywordtype}{bool} enableSounds = \textcolor{keyword}{false};}
\DoxyCodeLine{134 }
\DoxyCodeLine{135         \textcolor{keyword}{struct }timespec clockObj;}
\DoxyCodeLine{136         \textcolor{keywordtype}{unsigned} stopTimeGesture;}
\DoxyCodeLine{137 }
\DoxyCodeLine{138         uint timeoutEndTimeSensor1;}
\DoxyCodeLine{139         uint timeoutEndTimeSensor2;}
\DoxyCodeLine{140         uint timeoutEndTimeSensor3;}
\DoxyCodeLine{141         uint timeoutEndTimeSensor4;}
\DoxyCodeLine{142         uint timeoutEndTimeSensor5;}
\DoxyCodeLine{143         uint timeoutEndTimeSensor6;}
\DoxyCodeLine{144 }
\DoxyCodeLine{145         \textcolor{keywordtype}{bool} hitDetectedRecently = \textcolor{keyword}{false};}
\DoxyCodeLine{146 }
\DoxyCodeLine{147         \textcolor{keywordtype}{bool} gesture\_detected\_sensor5 = \textcolor{keyword}{false};}
\DoxyCodeLine{148         \textcolor{keywordtype}{bool} gesture\_detected\_sensor4 = \textcolor{keyword}{false};}
\DoxyCodeLine{149         \textcolor{keywordtype}{bool} gesture\_detected\_sensor3 = \textcolor{keyword}{false};}
\DoxyCodeLine{150         \textcolor{keywordtype}{bool} gesture\_detected\_sensor2 = \textcolor{keyword}{false};}
\DoxyCodeLine{151 }
\DoxyCodeLine{155         \textcolor{keywordtype}{void} velocityCalc();}
\DoxyCodeLine{156 }
\DoxyCodeLine{161         \textcolor{keywordtype}{bool} sensorsReady();}
\DoxyCodeLine{162 }
\DoxyCodeLine{166         \textcolor{keywordtype}{void} updateDistance();}
\DoxyCodeLine{167 }
\DoxyCodeLine{172         \textcolor{keywordtype}{bool} hitDetection();}
\DoxyCodeLine{173 }
\DoxyCodeLine{179         \textcolor{keywordtype}{void} sendSound(sensorID \textcolor{keywordtype}{id}, \textcolor{keywordtype}{int} detectionValue);}
\DoxyCodeLine{180 }
\DoxyCodeLine{188         \textcolor{keywordtype}{int} getPeakVelocity(sensorID \textcolor{keywordtype}{id}, \textcolor{keywordtype}{int} samplesToSearch, \textcolor{keywordtype}{bool} noiseCheckingEn = HIT\_DETECT\_NOISE\_CHECKING);}
\DoxyCodeLine{189 }
\DoxyCodeLine{193         \textcolor{keywordtype}{void} printSensorCurrentDistance();}
\DoxyCodeLine{194 }
\DoxyCodeLine{198         \textcolor{keywordtype}{void} printSensorAvgVelocity();}
\DoxyCodeLine{199 }
\DoxyCodeLine{204         \textcolor{keywordtype}{bool} gestureDetect();}
\DoxyCodeLine{205 }
\DoxyCodeLine{209         \textcolor{keywordtype}{void} initLeds();}
\DoxyCodeLine{210 }
\DoxyCodeLine{211 \textcolor{comment}{//        /**}}
\DoxyCodeLine{212 \textcolor{comment}{//         * Initialize Interrupts}}
\DoxyCodeLine{213 \textcolor{comment}{//         **/}}
\DoxyCodeLine{214 \textcolor{comment}{//        void initInterrupts();}}
\DoxyCodeLine{215 }
\DoxyCodeLine{221         \textcolor{keywordtype}{void} parseCommandLine(\textcolor{keywordtype}{int} argc,\textcolor{keywordtype}{char} *argv[]);}
\DoxyCodeLine{222 }
\DoxyCodeLine{227         \textcolor{keywordtype}{void} runCommandLine(\textcolor{keywordtype}{char} *argv[]);}
\DoxyCodeLine{228 }
\DoxyCodeLine{229 \};}
\DoxyCodeLine{230 }
\DoxyCodeLine{231 \textcolor{preprocessor}{\#endif }\textcolor{comment}{// CONTROLLER\_H}}

\end{DoxyCode}

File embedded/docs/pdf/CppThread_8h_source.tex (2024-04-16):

\hypertarget{CppThread_8h_source}{}\doxysubsection{Cpp\+Thread.\+h}
\label{CppThread_8h_source}\index{include/CppThread.h@{include/CppThread.h}}

\begin{DoxyCode}{0}
\DoxyCodeLine{1 \textcolor{preprocessor}{\#ifndef \_\_CPP\_THREAD\_H\_}}
\DoxyCodeLine{2 \textcolor{preprocessor}{\#define \_\_CPP\_THREAD\_H\_}}
\DoxyCodeLine{3 }
\DoxyCodeLine{11 \textcolor{preprocessor}{\#include <thread>}}
\DoxyCodeLine{12 }
\DoxyCodeLine{20 \textcolor{keyword}{class }\mbox{\hyperlink{classCppThread}{CppThread}} \{}
\DoxyCodeLine{21 }
\DoxyCodeLine{22 \textcolor{keyword}{public}:}
\DoxyCodeLine{26         \textcolor{keyword}{inline} \textcolor{keywordtype}{void} \mbox{\hyperlink{classCppThread_a1be46d1be000f41a763289300623c609}{start}}() \{}
\DoxyCodeLine{27                 uthread = std::thread(\&\mbox{\hyperlink{classCppThread_a792b79e72250710147c452648def4a78}{CppThread::run}}, \textcolor{keyword}{this});}
\DoxyCodeLine{28         \}}
\DoxyCodeLine{29 }
\DoxyCodeLine{33         \textcolor{keyword}{inline} \textcolor{keywordtype}{void} \mbox{\hyperlink{classCppThread_a8ff0fda6b913cc53764caef0e1200f3f}{join}}() \{}
\DoxyCodeLine{34                 uthread.join();}
\DoxyCodeLine{35         \}}
\DoxyCodeLine{36 }
\DoxyCodeLine{37 \textcolor{keyword}{protected}:}
\DoxyCodeLine{43         \textcolor{keyword}{virtual} \textcolor{keywordtype}{void} \mbox{\hyperlink{classCppThread_a792b79e72250710147c452648def4a78}{run}}() = 0;      }
\DoxyCodeLine{44 }
\DoxyCodeLine{45 \textcolor{keyword}{private}:}
\DoxyCodeLine{46         \textcolor{comment}{// pointer to the thread}}
\DoxyCodeLine{47         std::thread uthread;}
\DoxyCodeLine{48 \};}
\DoxyCodeLine{49 }
\DoxyCodeLine{50 }
\DoxyCodeLine{51 \textcolor{preprocessor}{\#endif}}

\end{DoxyCode}

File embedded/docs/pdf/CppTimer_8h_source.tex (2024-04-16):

\hypertarget{CppTimer_8h_source}{}\doxysubsection{Cpp\+Timer.\+h}
\label{CppTimer_8h_source}\index{include/CppTimer.h@{include/CppTimer.h}}

\begin{DoxyCode}{0}
\DoxyCodeLine{1 \textcolor{preprocessor}{\#ifndef \_\_CPP\_TIMER\_H\_}}
\DoxyCodeLine{2 \textcolor{preprocessor}{\#define \_\_CPP\_TIMER\_H\_}}
\DoxyCodeLine{3 }
\DoxyCodeLine{13 \textcolor{preprocessor}{\#include <stdlib.h>}}
\DoxyCodeLine{14 \textcolor{preprocessor}{\#include <unistd.h>}}
\DoxyCodeLine{15 \textcolor{preprocessor}{\#include <stdio.h>}}
\DoxyCodeLine{16 \textcolor{preprocessor}{\#include <time.h>}}
\DoxyCodeLine{17 \textcolor{preprocessor}{\#include <thread>}}
\DoxyCodeLine{18 \textcolor{preprocessor}{\#include <sys/timerfd.h>}}
\DoxyCodeLine{19 }
\DoxyCodeLine{23 \textcolor{keyword}{enum} cppTimerType\_t}
\DoxyCodeLine{24 \{}
\DoxyCodeLine{25     PERIODIC,}
\DoxyCodeLine{26     ONESHOT}
\DoxyCodeLine{27 \};}
\DoxyCodeLine{28 }
\DoxyCodeLine{33 \textcolor{keyword}{class }\mbox{\hyperlink{classCppTimer}{CppTimer}}}
\DoxyCodeLine{34 \{}
\DoxyCodeLine{35 }
\DoxyCodeLine{36 \textcolor{keyword}{public}:}
\DoxyCodeLine{46     \textcolor{keyword}{virtual} \textcolor{keywordtype}{void} \mbox{\hyperlink{classCppTimer_a7de6bd2c8c9b5daa70d5c3d9b97fa49b}{startns}}(\textcolor{keywordtype}{long} nanosecs, cppTimerType\_t type = PERIODIC) \{}
\DoxyCodeLine{47         \textcolor{keywordflow}{if} (running) \textcolor{keywordflow}{return};}
\DoxyCodeLine{48         fd = timerfd\_create(CLOCK\_MONOTONIC, 0);}
\DoxyCodeLine{49         \textcolor{keywordflow}{if} (fd < 0)}
\DoxyCodeLine{50             \textcolor{keywordflow}{throw}(\textcolor{stringliteral}{"{}Could not start timer"{}});}
\DoxyCodeLine{51         \textcolor{keywordflow}{switch} (type)}
\DoxyCodeLine{52         \{}
\DoxyCodeLine{53         \textcolor{keywordflow}{case} (PERIODIC):}
\DoxyCodeLine{54             \textcolor{comment}{//starts after specified period of nanoseconds}}
\DoxyCodeLine{55             its.it\_value.tv\_sec = nanosecs / 1000000000;}
\DoxyCodeLine{56             its.it\_value.tv\_nsec = nanosecs \% 1000000000;}
\DoxyCodeLine{57             its.it\_interval.tv\_sec = nanosecs / 1000000000;}
\DoxyCodeLine{58             its.it\_interval.tv\_nsec = nanosecs \% 1000000000;}
\DoxyCodeLine{59             \textcolor{keywordflow}{break};}
\DoxyCodeLine{60         \textcolor{keywordflow}{case} (ONESHOT):}
\DoxyCodeLine{61             \textcolor{comment}{//fires once after specified period of nanoseconds}}
\DoxyCodeLine{62             its.it\_value.tv\_sec = nanosecs / 1000000000;}
\DoxyCodeLine{63             its.it\_value.tv\_nsec = nanosecs \% 1000000000;}
\DoxyCodeLine{64             its.it\_interval.tv\_sec = 0;}
\DoxyCodeLine{65             its.it\_interval.tv\_nsec = 0;}
\DoxyCodeLine{66             \textcolor{keywordflow}{break};}
\DoxyCodeLine{67         \}}
\DoxyCodeLine{68         \textcolor{keywordflow}{if} (timerfd\_settime(fd, 0, \&its, NULL) == -\/1)}
\DoxyCodeLine{69             \textcolor{keywordflow}{throw}(\textcolor{stringliteral}{"{}Could not start timer"{}});}
\DoxyCodeLine{70         uthread = std::thread(\&CppTimer::worker,\textcolor{keyword}{this});}
\DoxyCodeLine{71     \}}
\DoxyCodeLine{72 }
\DoxyCodeLine{82     \textcolor{keyword}{virtual} \textcolor{keywordtype}{void} \mbox{\hyperlink{classCppTimer_a8054cc8cead2e360b06b6ff99cc964cf}{startms}}(\textcolor{keywordtype}{long} millisecs, cppTimerType\_t type = PERIODIC) \{}
\DoxyCodeLine{83         \textcolor{keywordflow}{if} (running) \textcolor{keywordflow}{return};}
\DoxyCodeLine{84         fd = timerfd\_create(CLOCK\_MONOTONIC, 0);}
\DoxyCodeLine{85         \textcolor{keywordflow}{if} (fd < 0)}
\DoxyCodeLine{86             \textcolor{keywordflow}{throw}(\textcolor{stringliteral}{"{}Could not start timer"{}});}
\DoxyCodeLine{87         \textcolor{keywordflow}{switch} (type)}
\DoxyCodeLine{88         \{}
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

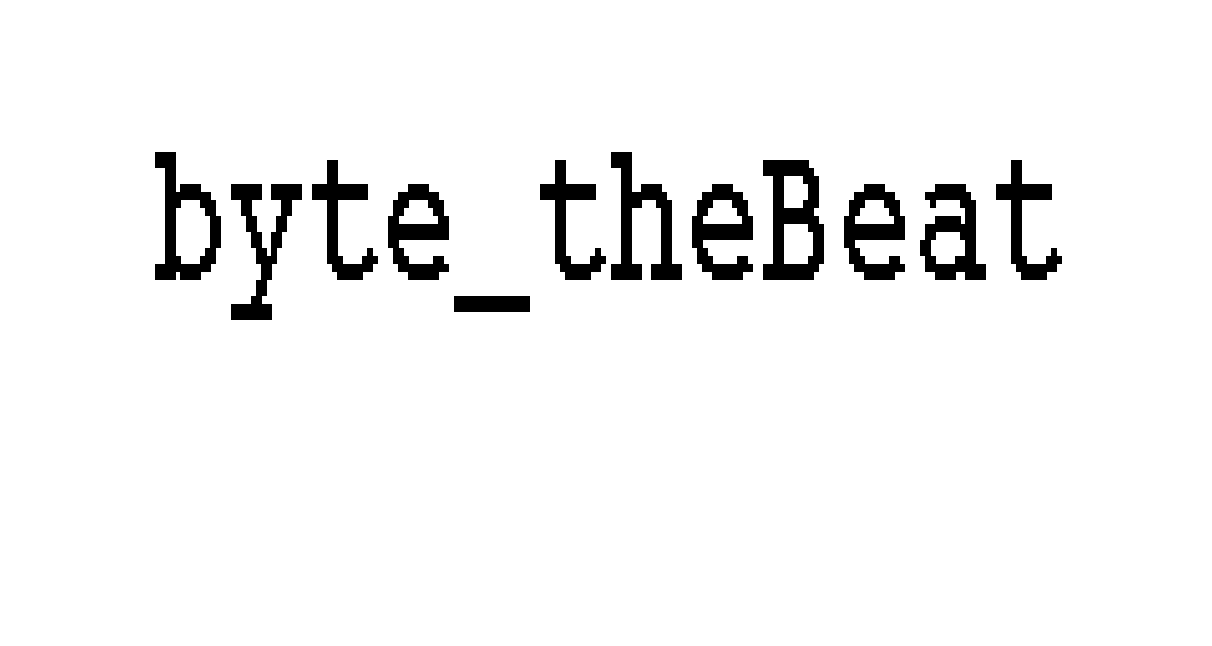
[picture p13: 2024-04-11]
hardware/ContactlessPiPoweredDrumkit/CAD/byte_theBeat.png

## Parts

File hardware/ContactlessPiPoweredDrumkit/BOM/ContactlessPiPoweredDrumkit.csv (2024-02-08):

Reference | Value | Part Number | Supplier | Supplier Part Number | Footprint | Price | Total Cost | Qty
C1, C2, C5, C6, C9, C10 | 100n | CL10B104KB8NNWC |  |  | Capacitor_SMD:C_0603_1608Metric | 0.1 | 0.6 | 6
C3, C4, C7, C8, C11, C12 | 4.7u | CL10A475KQ8NNNC |  |  | Capacitor_SMD:C_0603_1608Metric | 0.1 | 0.6 | 6
D1-D6 | Inolux_IN-PI554FCH | IN-PI554FCH |  |  | LED_SMD:LED_Inolux_IN-PI554FCH_PLCC4_5.0x5.0mm_P3.2mm | 0.72 | 4.32 | 6
H1-H6 | MountingHole_Pad |  |  |  | MountingHole:MountingHole_4.3mm_M4_DIN965_Pad_TopBottom |  |  | N/A
J1 | Raspberry_Pi_1_2_3 | 61304021821 | Digikey | 732-61304021821-ND | Connector_PinSocket_2.54mm:PinSocket_2x20_P2.54mm_Vertical | 1.92 | 1.92 | 1
J2-J7 | Conn_01x06_Socket |  |  |  | Connector_PinSocket_2.54mm:PinSocket_1x06_P2.54mm_Vertical |  |  | DNP
R1-R12 | 10k | RMCF0603FT10K0 |  |  | Resistor_SMD:R_0603_1608Metric | 0.1 | 1.2 | 12
R13-R16 | 1k | RMCF0603FT1K00 |  |  | Resistor_SMD:R_0603_1608Metric | 0.1 | 0.4 | 4
R17 | 500 | RMCF0603FG475R |  |  | Resistor_SMD:R_0603_1608Metric | 0.1 | 0.1 | 1
U1-U6 | VL53L4CD | VL53L4CDV0DH/1 | Digikey | 497-VL53L4CDV0DH/1DKR-ND | Sensor_Distance:ST_VL53L1x | 4.28 | 25.68 | 6
U7 | SN74LVC1T45DCK | SN74LVC1T45DCKR | Digikey | 296-16844-6-ND | Package_TO_SOT_SMD:SOT-363_SC-70-6 | 0.68 | 0.68 | 1
PCB FAB |  |  |  |  |  | 3.82 | 3.82 | 1
PCB ASSY |  |  |  |  |  | 1.91 | 1.91 | 1
Shipping |  |  |  |  |  | 4.4 | 4.4 | 1
 |  |  |  |  |  | Total Board Cost (USD): | 45.63
 |  |  |  |  |  | Total Board Cost (GBP): | 36.2142857142857

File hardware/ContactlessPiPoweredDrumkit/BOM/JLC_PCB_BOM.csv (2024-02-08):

Designator | Quantity | Value | Footprint | LSCS Part #
C2, C5, C6, C9 | 4 | 100n | 603 | C14663
C4, C7, C8, C11 | 4 | 4.7u | 603 | C19666
R1, R2, R3, R4, R5, R6, R7, R8, R9, R10, R11, R12 | 12 | 10k | 603 | C25804
R13, R14, R15, R16 | 4 | 1k | 603 | C21190
R17 | 1 | 470 | 603 | C23179
U2, U3, U4, U5 | 4 | VL53L4CD | Sensor_Distance:ST_VL53L1x | C3178291
U7 | 1 | SN74LVC1T45DCK | SC-70-6 | C9382

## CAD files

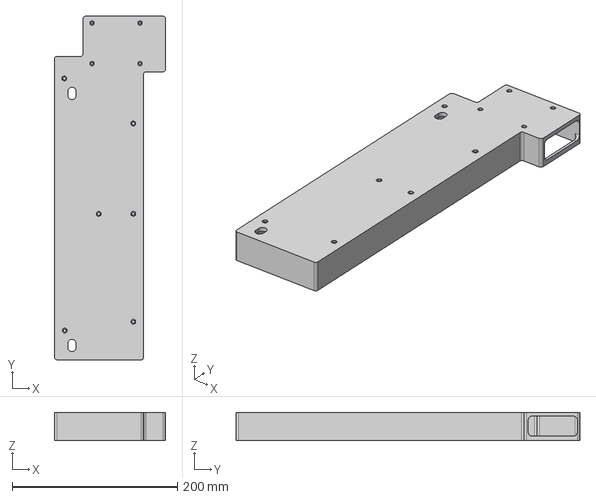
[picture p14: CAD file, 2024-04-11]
hardware/ContactlessPiPoweredDrumkit/CAD/Base.step
134.2 x 415.5 x 34.4 mm

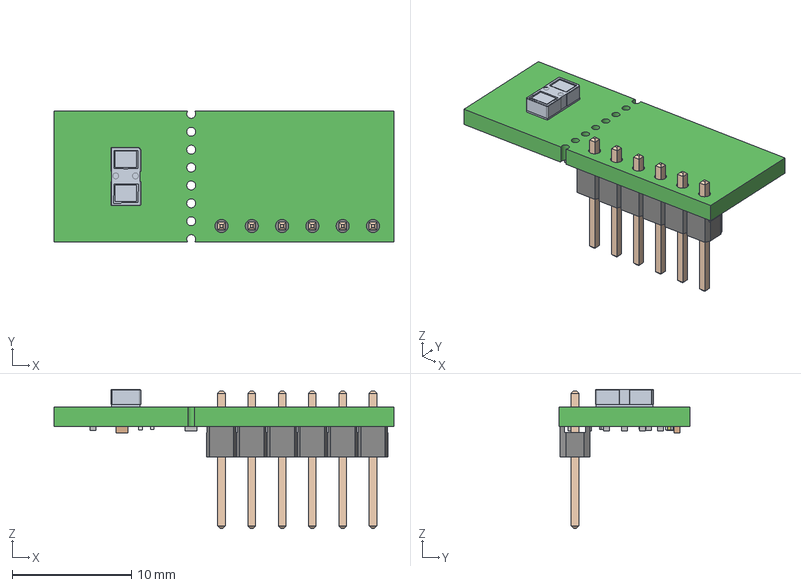
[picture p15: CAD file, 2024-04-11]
hardware/ContactlessPiPoweredDrumkit/CAD/VL53L4CD_Breakout.step
28.5 x 11.0 x 11.7 mm
Ewok_Plus_25_Substrate_Solid_Model
EWOK_Plus_25_Des1A_Cap_Solid_Model
6130xx11121_PIN x 6
Extruded x 18

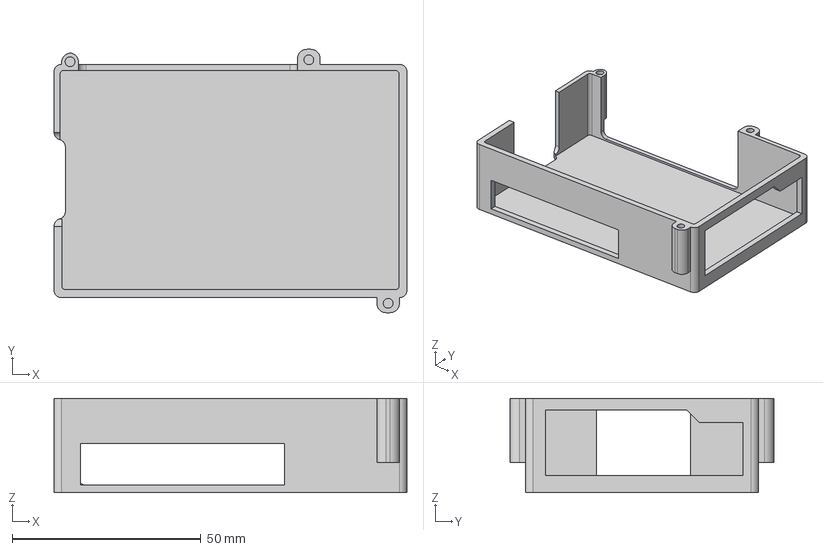
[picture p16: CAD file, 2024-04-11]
hardware/ContactlessPiPoweredDrumkit/CAD/Raspberry Pi 4 bottom case.step
93.5 x 69.8 x 25.0 mm

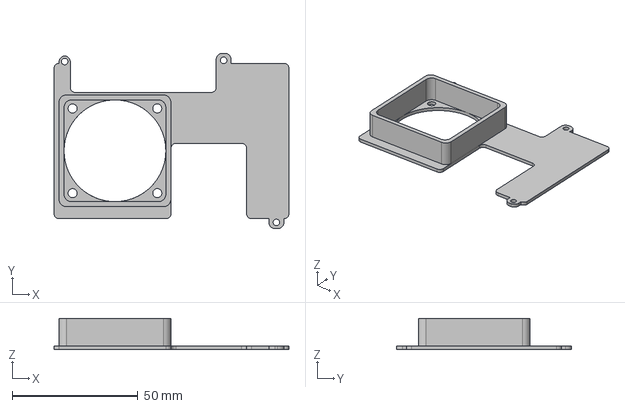
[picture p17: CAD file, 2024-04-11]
hardware/ContactlessPiPoweredDrumkit/CAD/Raspberry Pi Top Case.step
93.5 x 69.8 x 12.5 mm

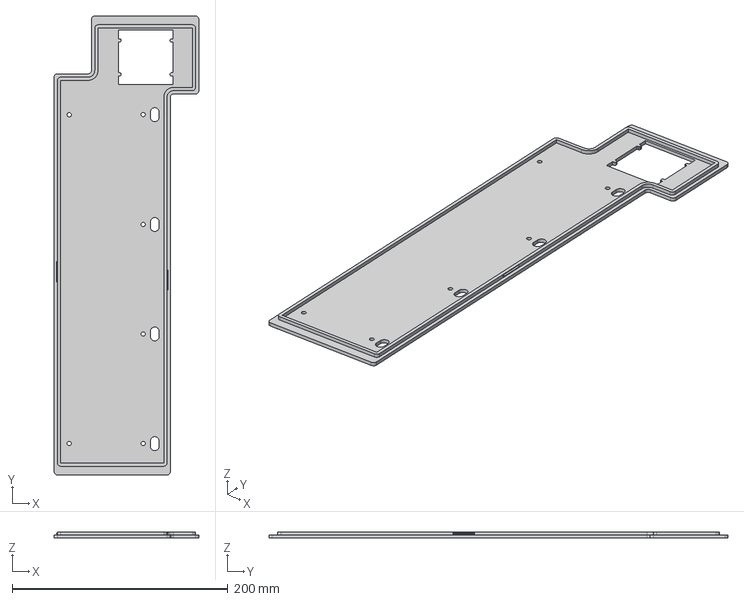
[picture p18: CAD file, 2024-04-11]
hardware/ContactlessPiPoweredDrumkit/CAD/Lid.step
134.2 x 425.5 x 6.00 mm

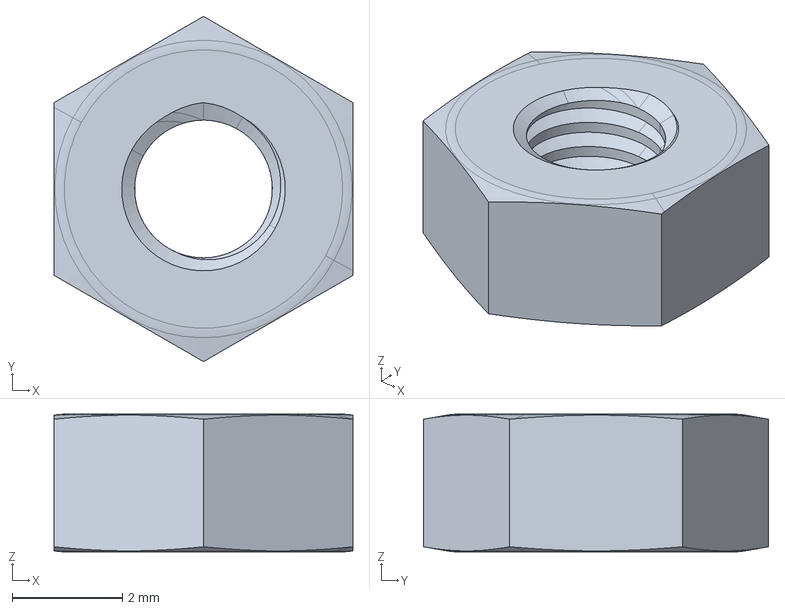
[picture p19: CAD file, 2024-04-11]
hardware/ContactlessPiPoweredDrumkit/CAD/M3 Nut.stp
5.43 x 6.27 x 2.50 mm

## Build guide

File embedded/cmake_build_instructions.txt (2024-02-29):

1) Make sure cmake is installed. If not, run $sudo apt install cmake
2) Navigate to this directory.
3) via CLI: $cmake .
4) via CLI: $make

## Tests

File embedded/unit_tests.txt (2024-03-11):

############################################
############## 	Instructions	############
############################################

After building project, unit test can be run by adding command line arguments after built application.
For example, the simple unit test named "test" can be ran with the following terminal entry:

	$./btb_proj test

Multiple unit tests can be run sequentially by adding more input parameters. 
The following terminal entry would run "test" 3 times in unison.

	$./btb_proj test test test

############################################
############## 	Unit Tests	############
############################################

Below, find a list of unit test input argument followed by a description.

Argument:	test
Description:	Simple test command. Prints "Test Argument Received!!"

Argument:	gpioTest
Description:	GPIO Speed test. Toggles GPIO 4 (pin 7) at maximimum speed for user defined seconds.

Argument:	ledNopAsmTest
Description:	Spew '1010' pattern to Leds using asm nop for delay. Only works pre-board rework.

Argument:	gpioLedSpiTest
Description:	Sets led to RGB brightness level via SPI interface

Argument:	ledInitialiseTest
Description:	Peter's LED test

Argument:	interruptTest
Description:	Sets up distance sensors, utilizing interrupts for reading their data. Runs 20seconds.

Argument:	soundTest1
Description:	Plays Sound linked to TH_LOUD_FOOT_CLOSED 1 time.

Argument:	soundTest2
Description:	Plays each sound in mixArr, which is an array of all sounds, then loops. Only plays the first
		"x" amount of sounds in mixArr, where x is number stored in define.h's "TOTAL_INSTRUMENTS_SOUND_TEST2"

Argument:	soundTest3
Description:	Plays a mix of sounds asynchronously, using the soundInit() function to initialize all sound files, and playSound()
		to play the sound samples.

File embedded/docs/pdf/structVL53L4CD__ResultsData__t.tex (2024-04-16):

\hypertarget{structVL53L4CD__ResultsData__t}{}\doxysubsection{VL53\+L4\+CD\+\_\+\+Results\+Data\+\_\+t Struct Reference}
\label{structVL53L4CD__ResultsData__t}\index{VL53L4CD\_ResultsData\_t@{VL53L4CD\_ResultsData\_t}}

Packed reading results type.  

{\ttfamily \#include $<$VL53\+L4\+CD\+\_\+api.\+h$>$}

\doxysubsubsection{Detailed Description}
Packed reading results type. 

The documentation for this struct was generated from the following file\+:\begin{DoxyCompactItemize}
\item 
include/VL53\+L4\+CD\+\_\+api.\+h\end{DoxyCompactItemize}

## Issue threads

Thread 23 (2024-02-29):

Requirement: 2.5ms ISR timer w/ callback.

GrantMaiden, 2024-02-29:
Needs to call led control State machine.

GrantMaiden, 2024-03-02:
Added 2.5ms timer callback to btb_main.cpp.
Used to toggle boolean flag for enabling LED state machine.

Closed 2024-03-02.

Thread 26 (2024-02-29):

Requirement: Led State Machine needs function to update Which Sensor has been hit, and how hard.

GrantMaiden, 2024-02-29:
@peteroh770 @Peteroh11

peteroh770, 2024-04-14:
functions and variables added to complete this and add visuals: hitDetectOutputControl, sensorHitLed, setLedVelocity, sensorHitRecently, hitColorSetter

Closed 2024-04-14.

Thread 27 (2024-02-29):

Requirement: Led Statemachine needs function that takes in velocity for each sensor

GrantMaiden, 2024-02-29:
@peteroh770 @Peteroh11

peteroh770, 2024-04-14:
already addressed in different issue

Closed 2024-04-14.

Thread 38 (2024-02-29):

Change LED control to use SPI interface, for much lower overhead

GrantMaiden, 2024-02-29:
@GrantMaiden
requires HW blue wire/rework.

Closed 2024-02-29.

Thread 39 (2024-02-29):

src and include files committed to wrong location in led_control branch

GrantMaiden, 2024-02-29:
@Peteroh11 @peteroh770

peteroh770, 2024-04-14:
src and include files moved to the right location.

Closed 2024-04-14.

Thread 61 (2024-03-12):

Potential Issue: SPI Led communication may have timing problem

GrantMaiden, 2024-03-12:
Look on scope to see if timing of SPI matches what is expected. Potentiallyl there is a small timing issue due to delay between bytes via spi protocol.

peteroh770, 2024-04-14:
Timing issue unresolved as it was a hardware failure possibly due to increased capacitance from the rerouting of the board with external wiring.

Closed 2024-04-14.

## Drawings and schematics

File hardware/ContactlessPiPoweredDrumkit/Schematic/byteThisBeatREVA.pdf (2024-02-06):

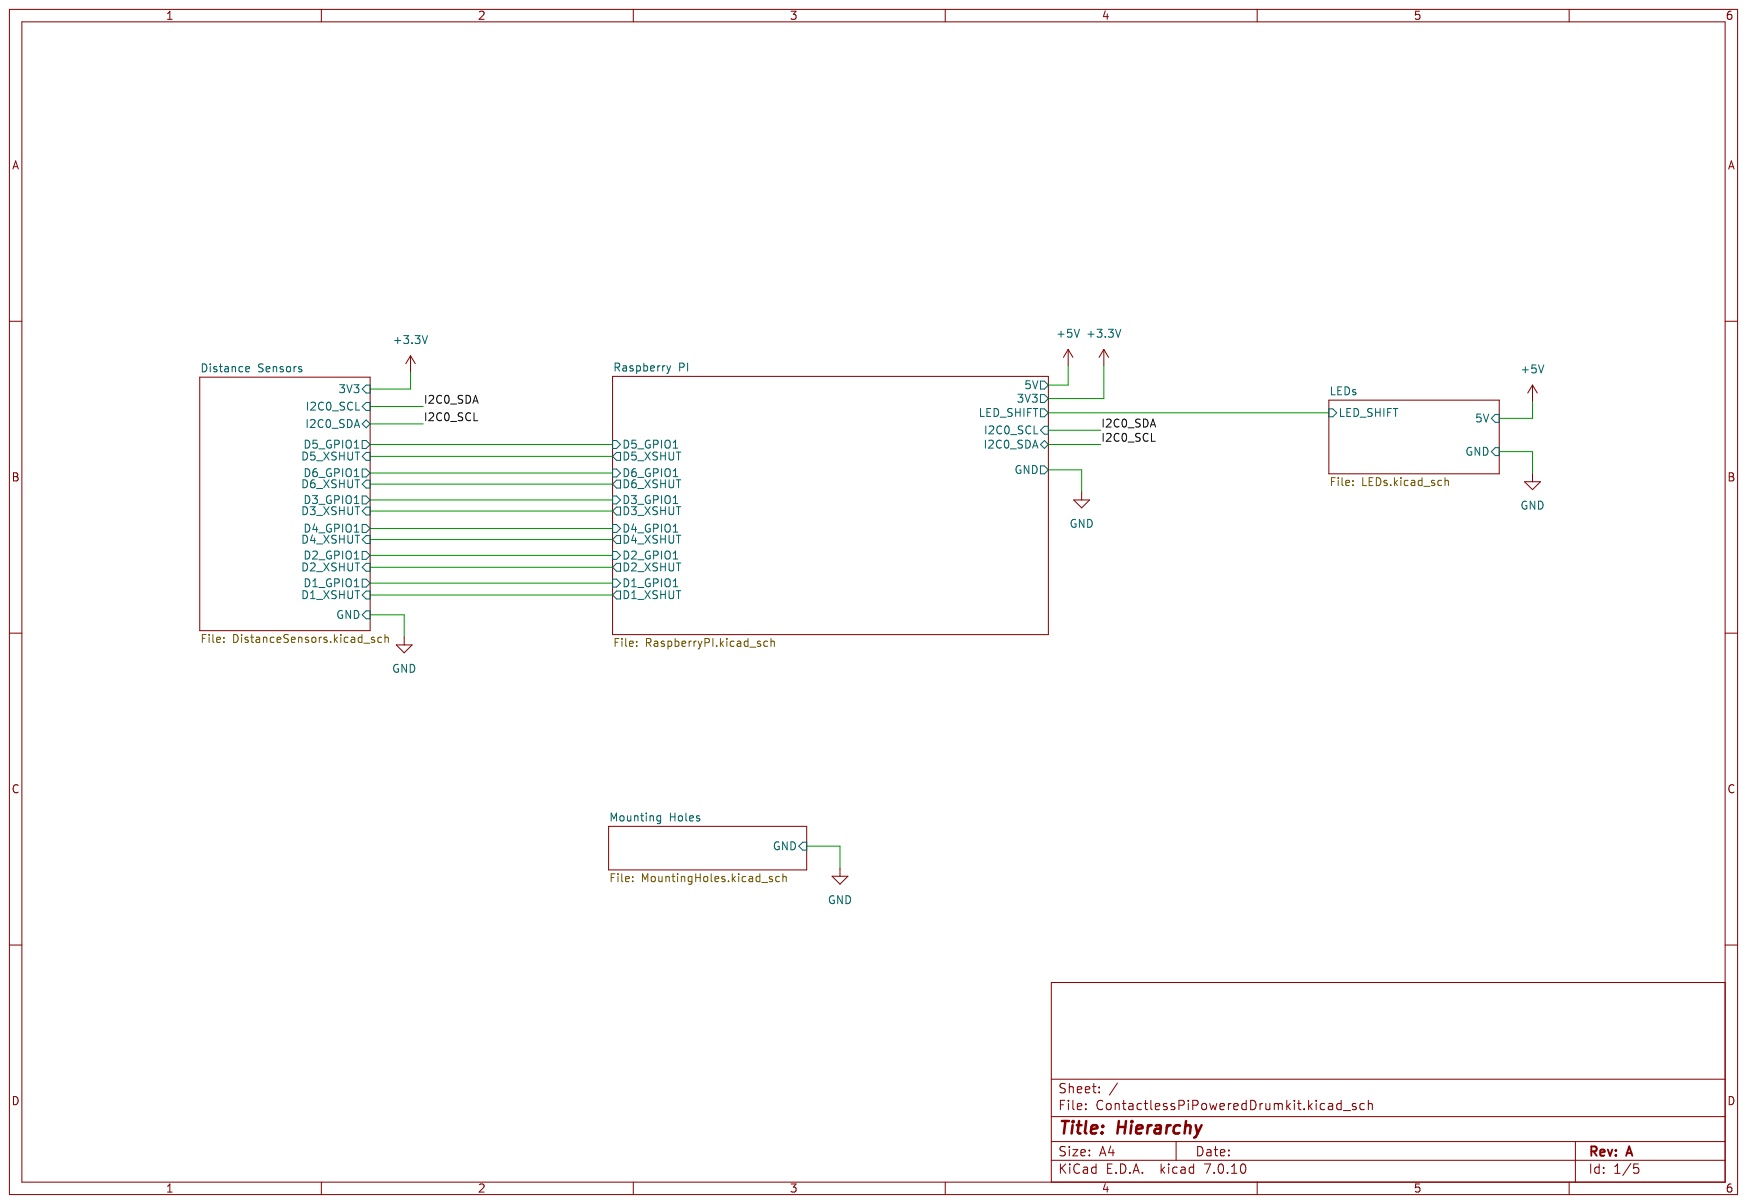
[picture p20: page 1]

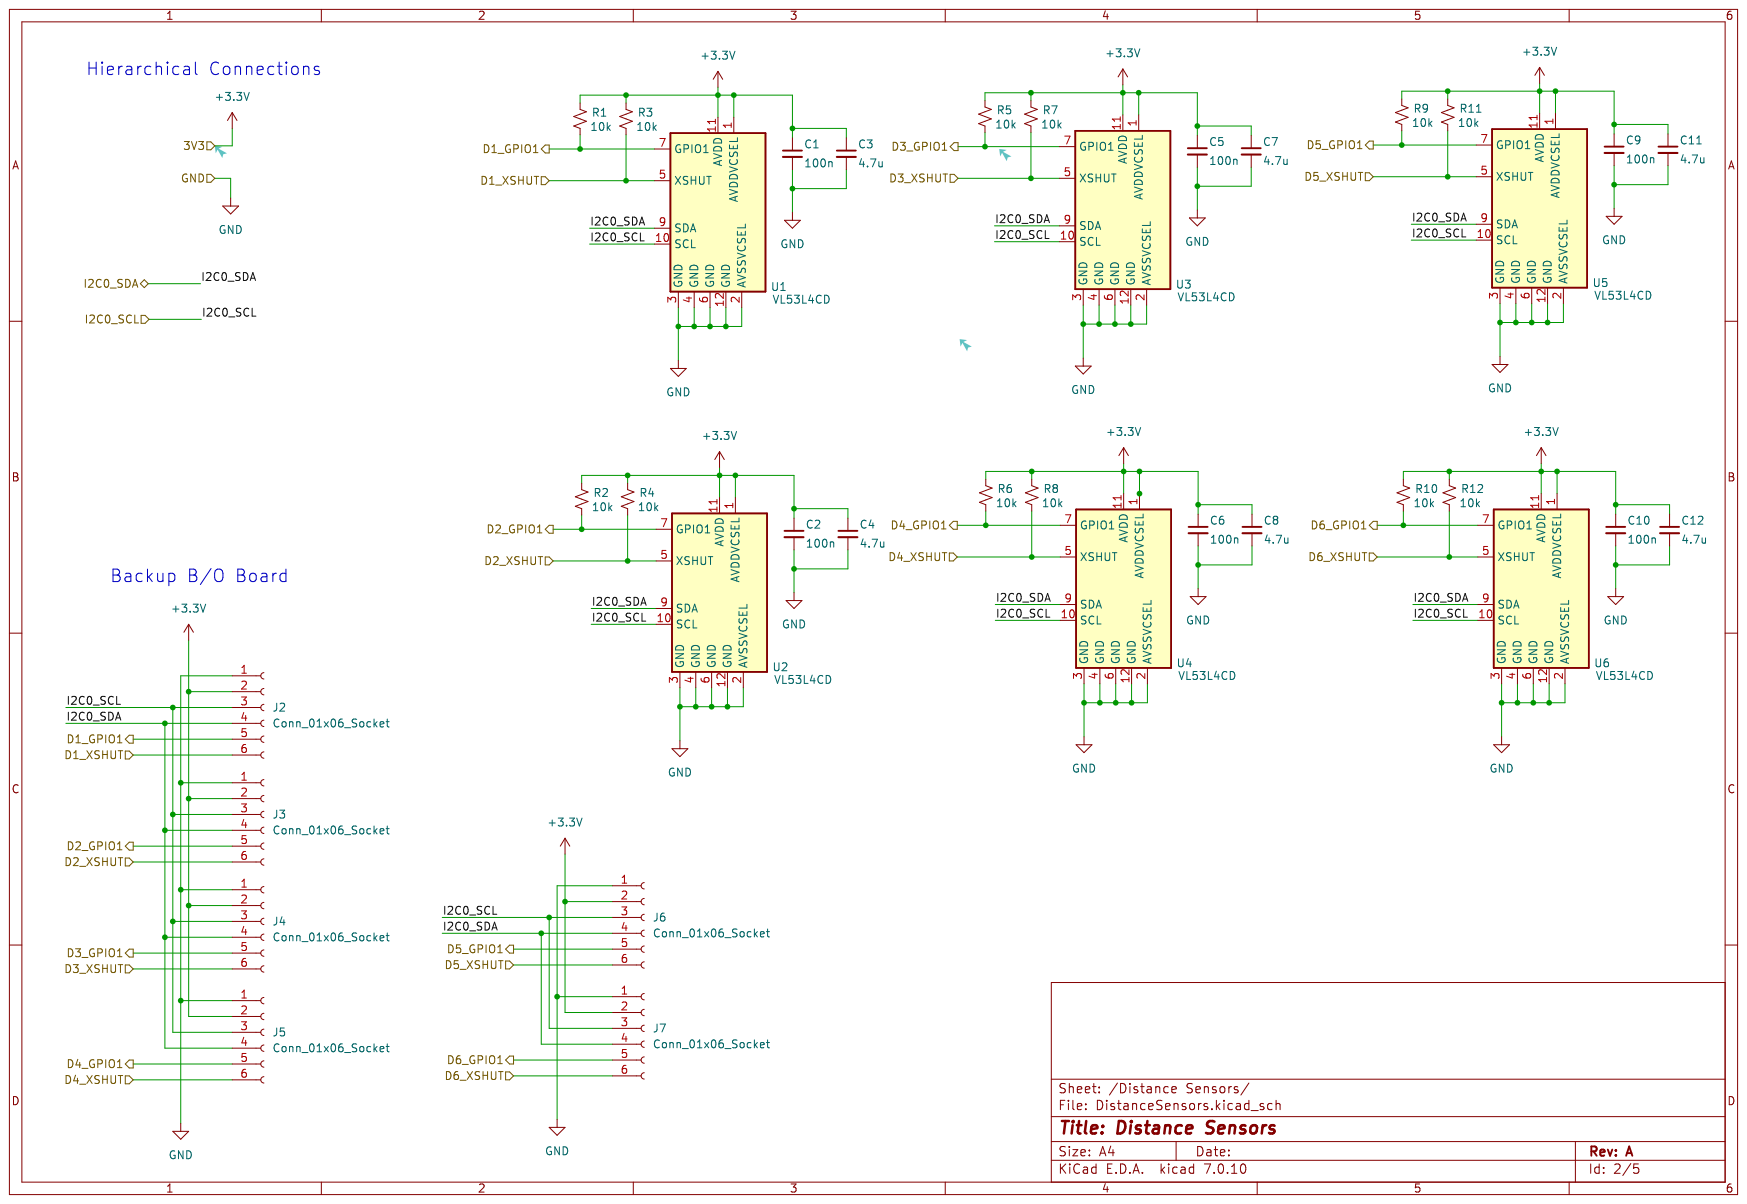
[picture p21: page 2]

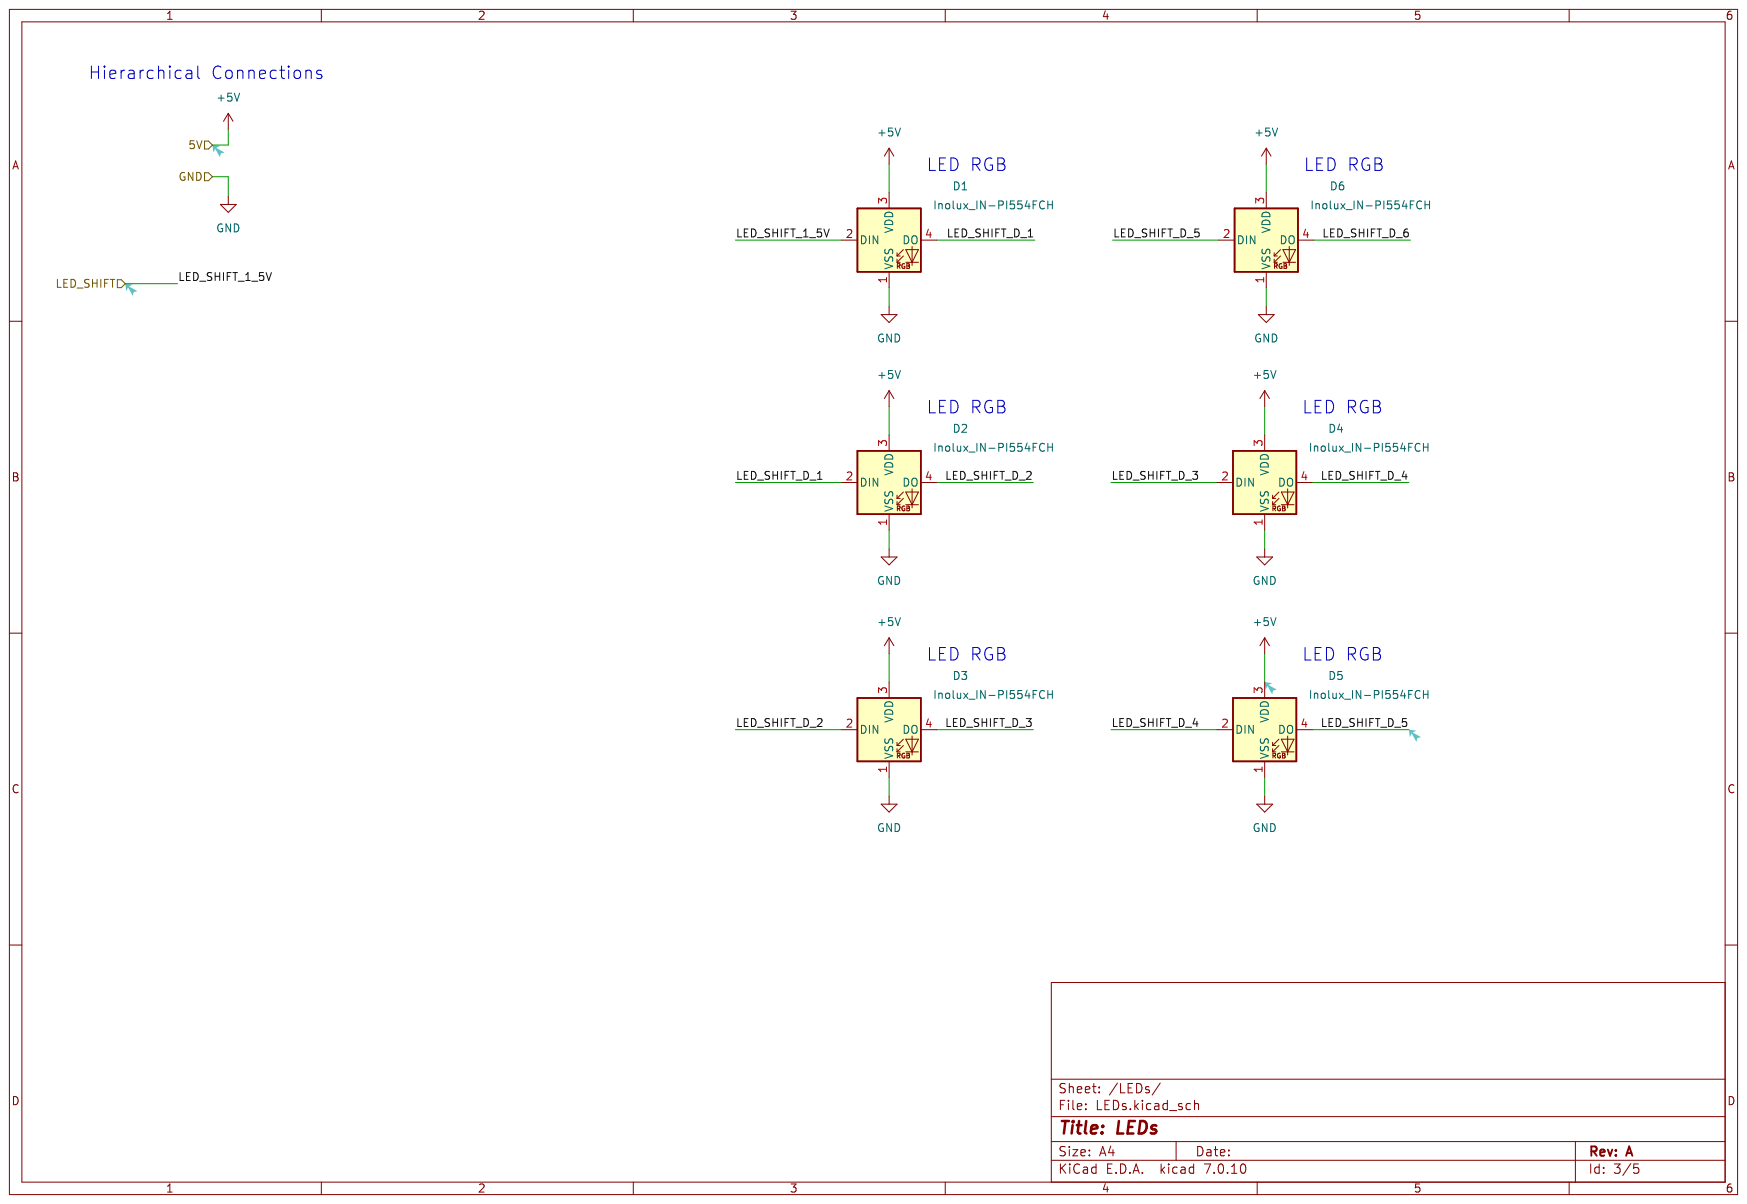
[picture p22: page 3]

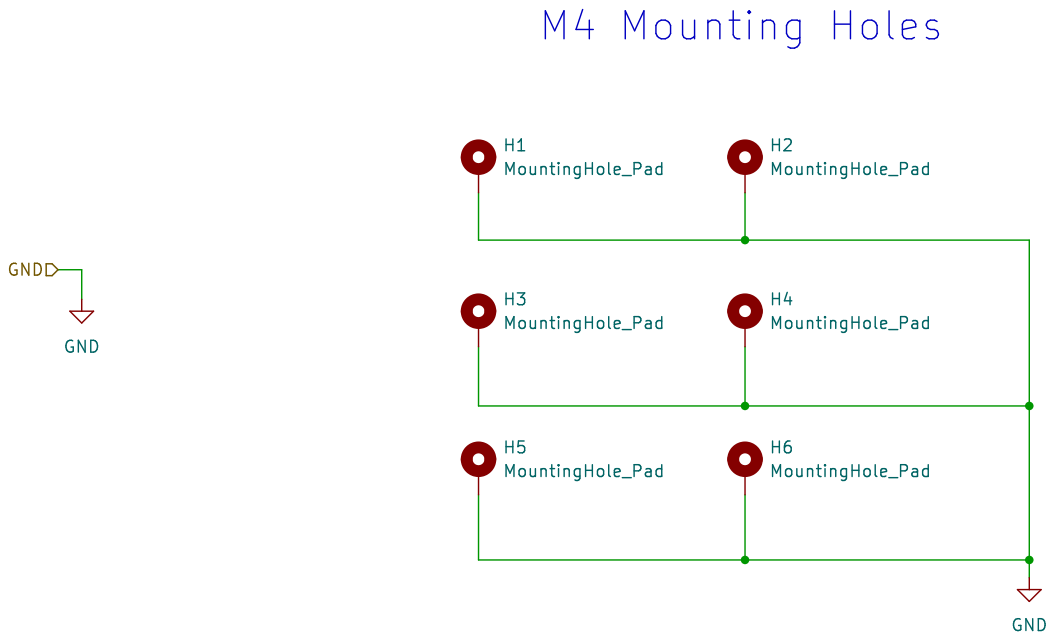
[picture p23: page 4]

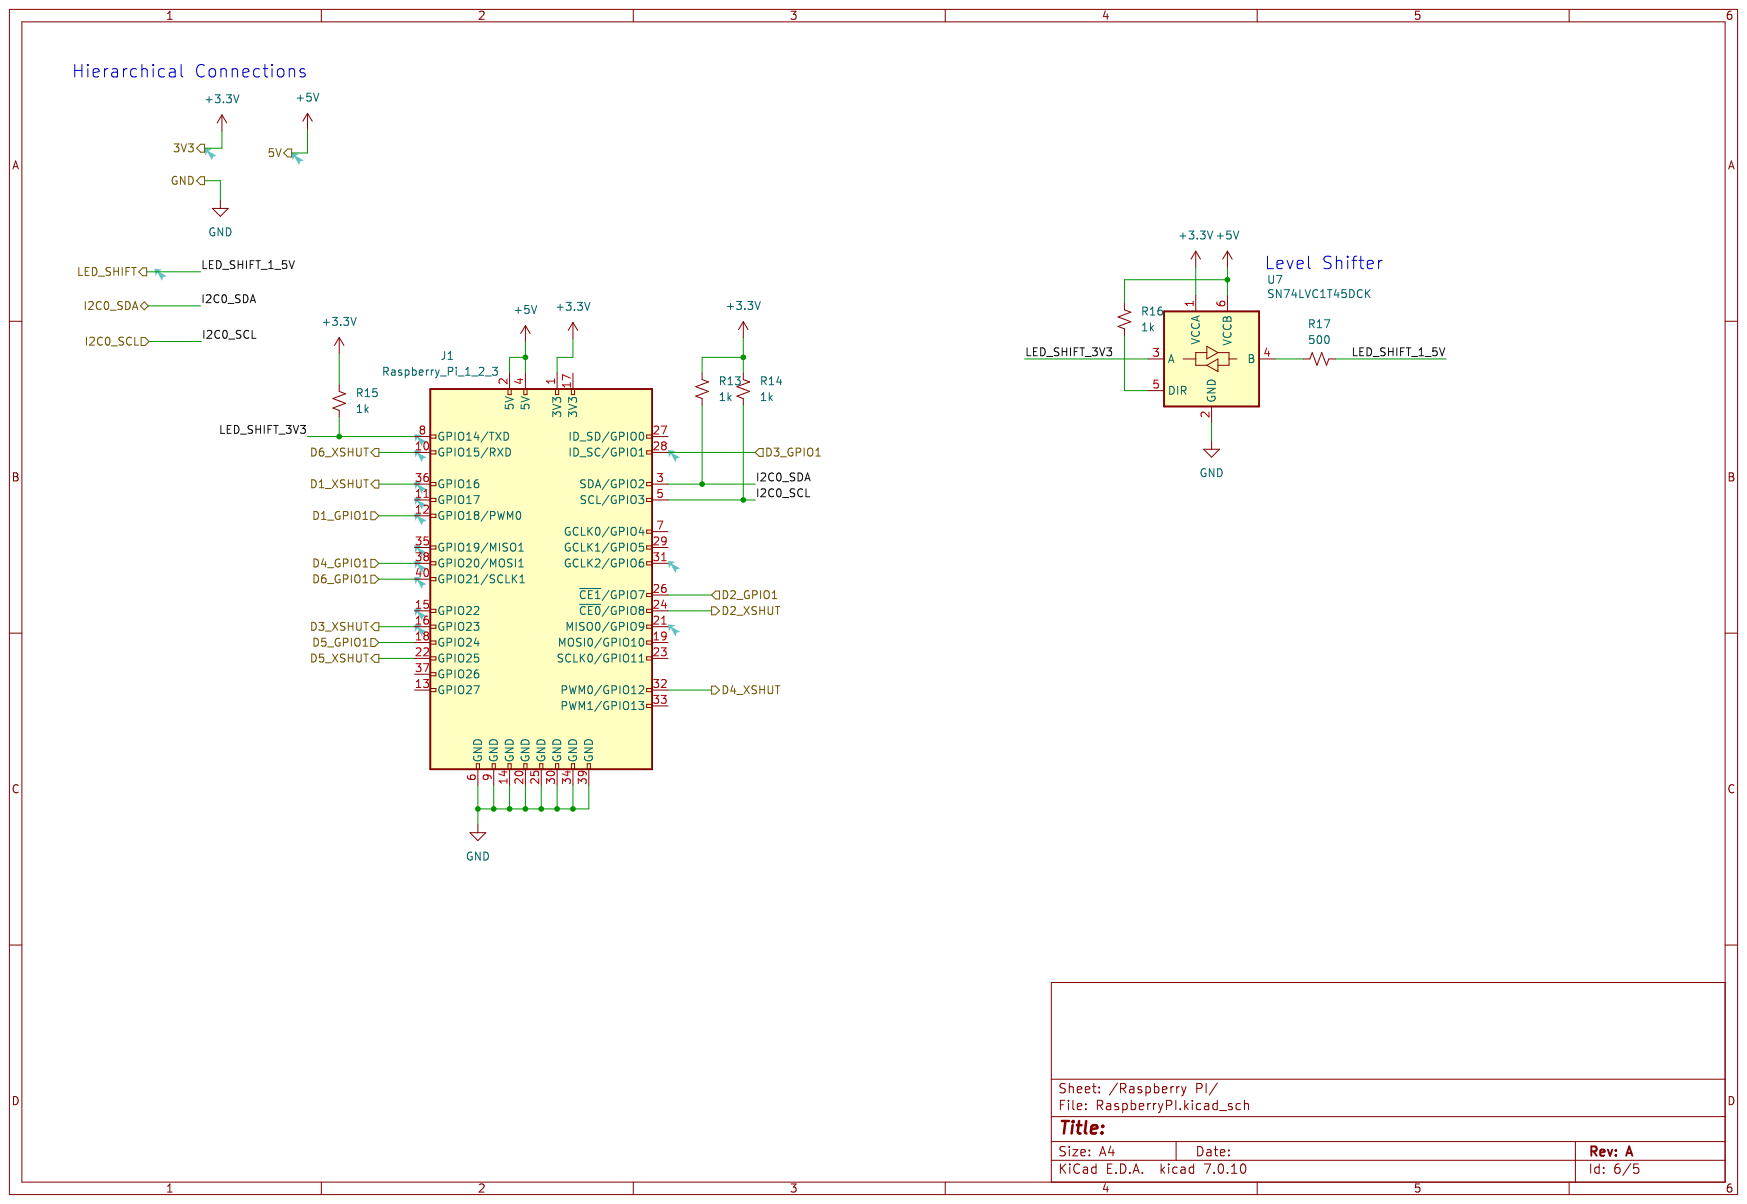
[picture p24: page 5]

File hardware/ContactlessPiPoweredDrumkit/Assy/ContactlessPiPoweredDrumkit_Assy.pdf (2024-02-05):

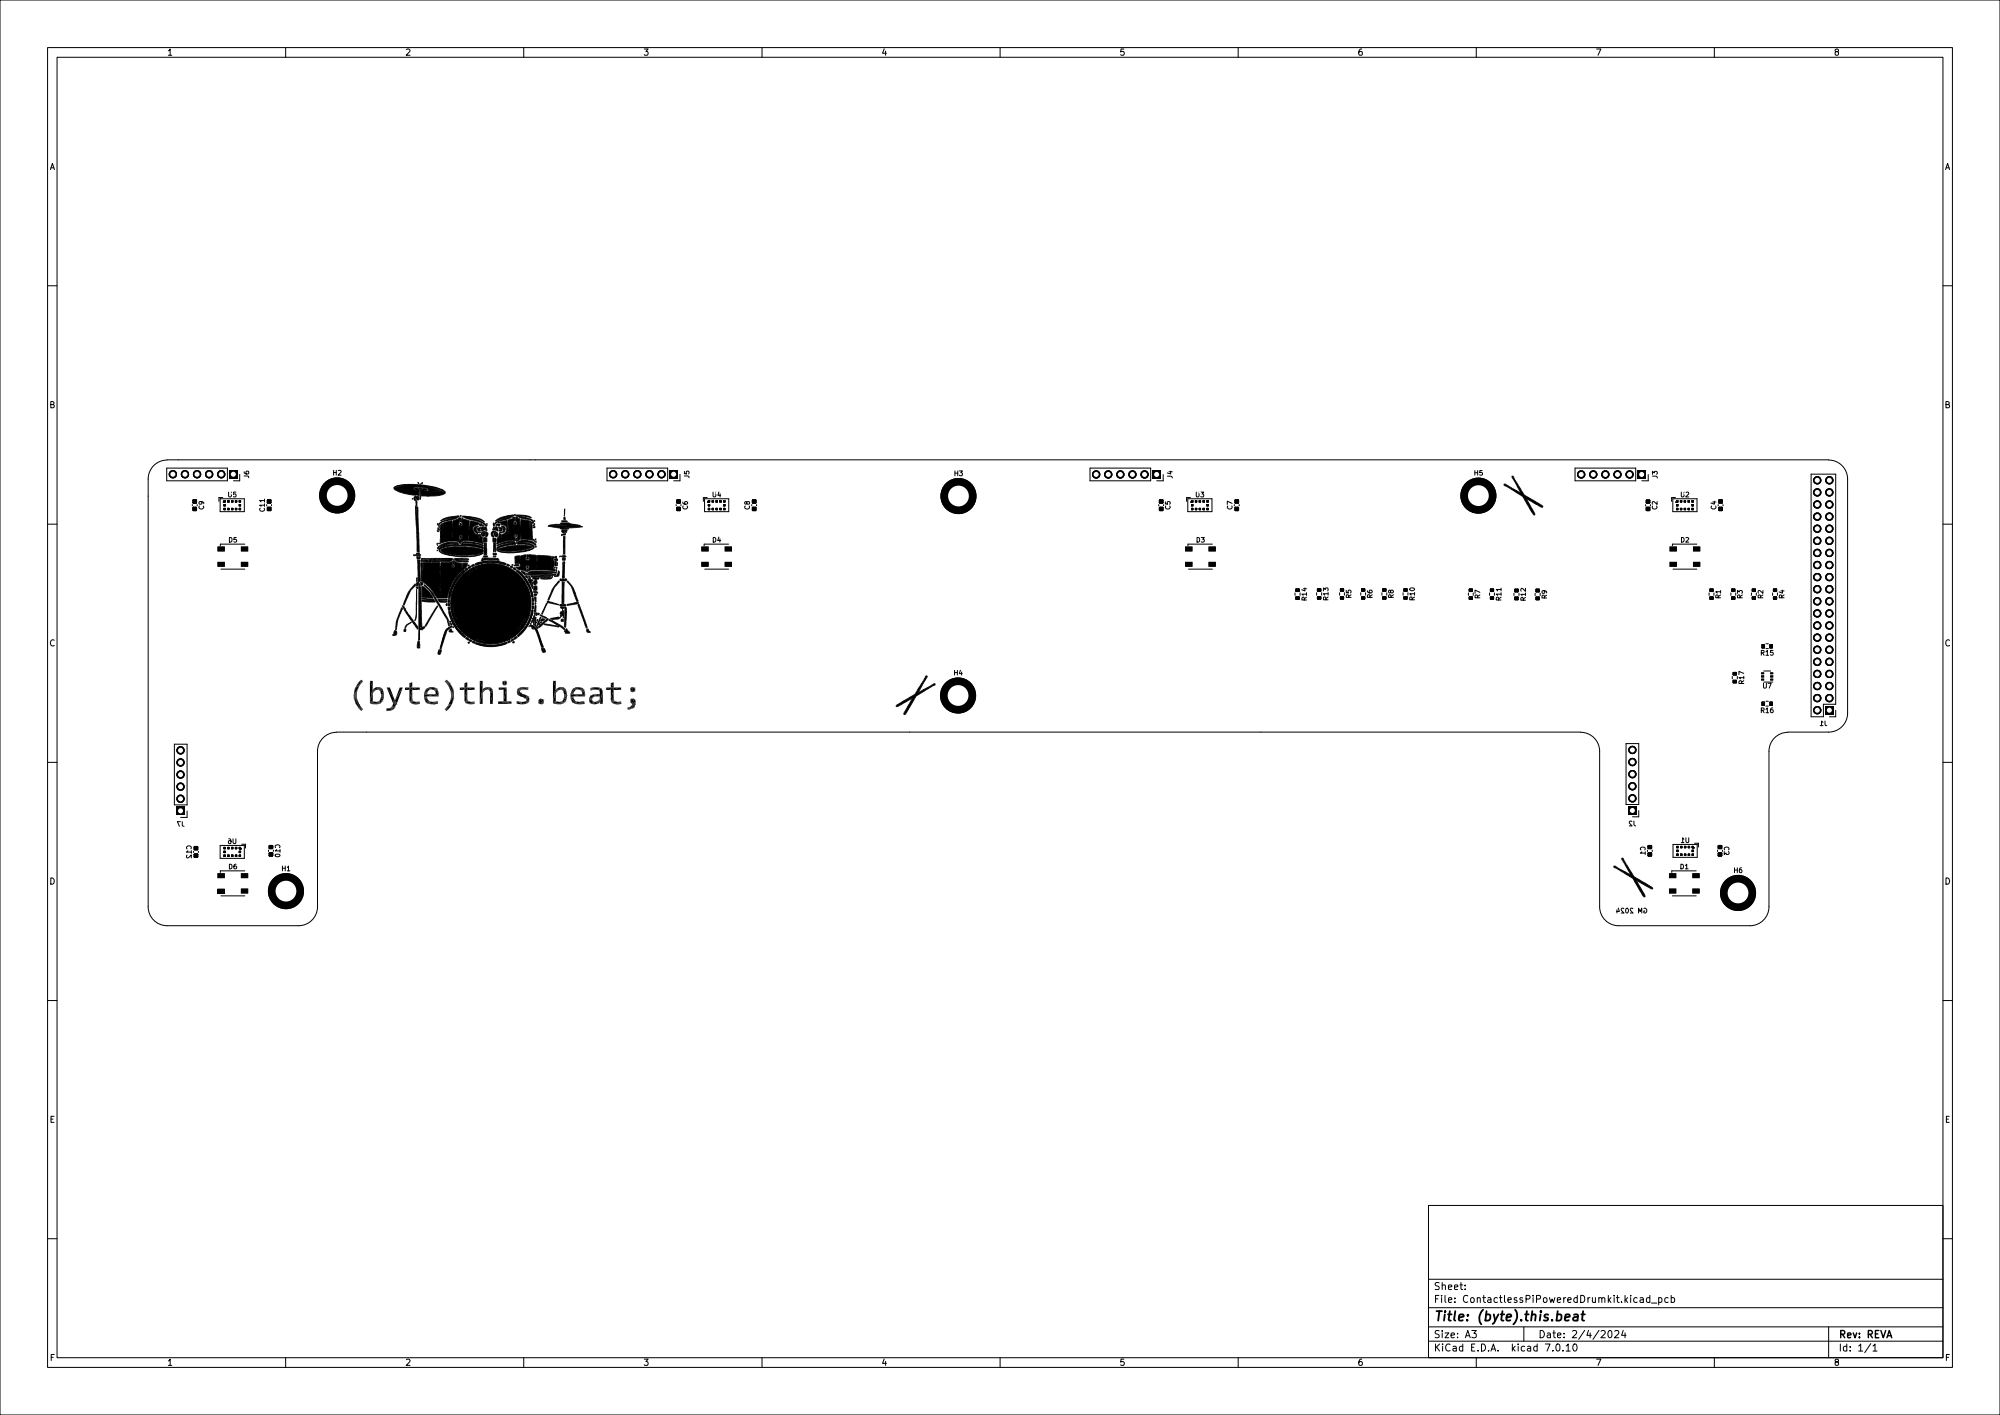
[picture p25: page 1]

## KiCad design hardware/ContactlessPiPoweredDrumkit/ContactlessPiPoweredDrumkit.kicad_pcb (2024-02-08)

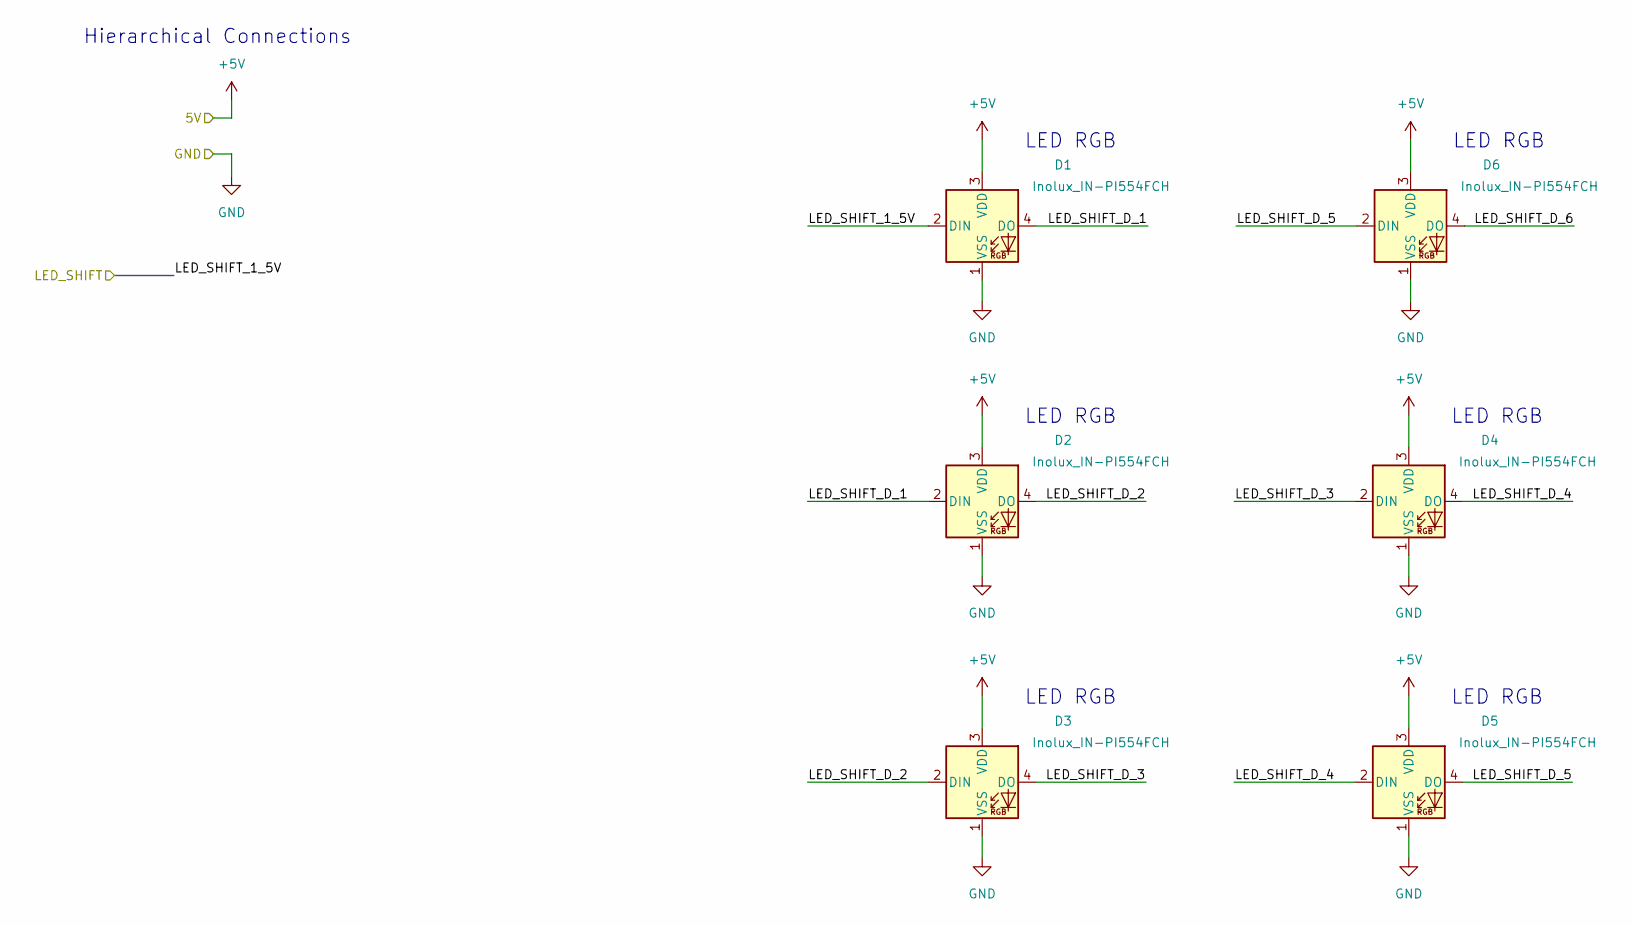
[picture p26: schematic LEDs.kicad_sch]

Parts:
D1, D2, D3, D4, D5, D6: Inolux_IN-PI554FCH; LED_Inolux_IN-PI554FCH_PLCC4_5.0x5.0mm_P3.2mm

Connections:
+5V: D1.3 (VDD), D2.3 (VDD), D3.3 (VDD), D4.3 (VDD), D5.3 (VDD), D6.3 (VDD); also elsewhere on the board
/LEDs/LED_SHIFT_1_5V: D1.2 (DIN); also elsewhere on the board
/LEDs/LED_SHIFT_D_1: D1.4 (DO), D2.2 (DIN)
/LEDs/LED_SHIFT_D_2: D2.4 (DO), D3.2 (DIN)
/LEDs/LED_SHIFT_D_3: D3.4 (DO), D4.2 (DIN)
/LEDs/LED_SHIFT_D_4: D4.4 (DO), D5.2 (DIN)
/LEDs/LED_SHIFT_D_5: D5.4 (DO), D6.2 (DIN)
/LEDs/LED_SHIFT_D_6: D6.4 (DO)
GND: D1.1 (VSS), D2.1 (VSS), D3.1 (VSS), D4.1 (VSS), D5.1 (VSS), D6.1 (VSS); also elsewhere on the board

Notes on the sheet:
LED RGB
Hierarchical Connections

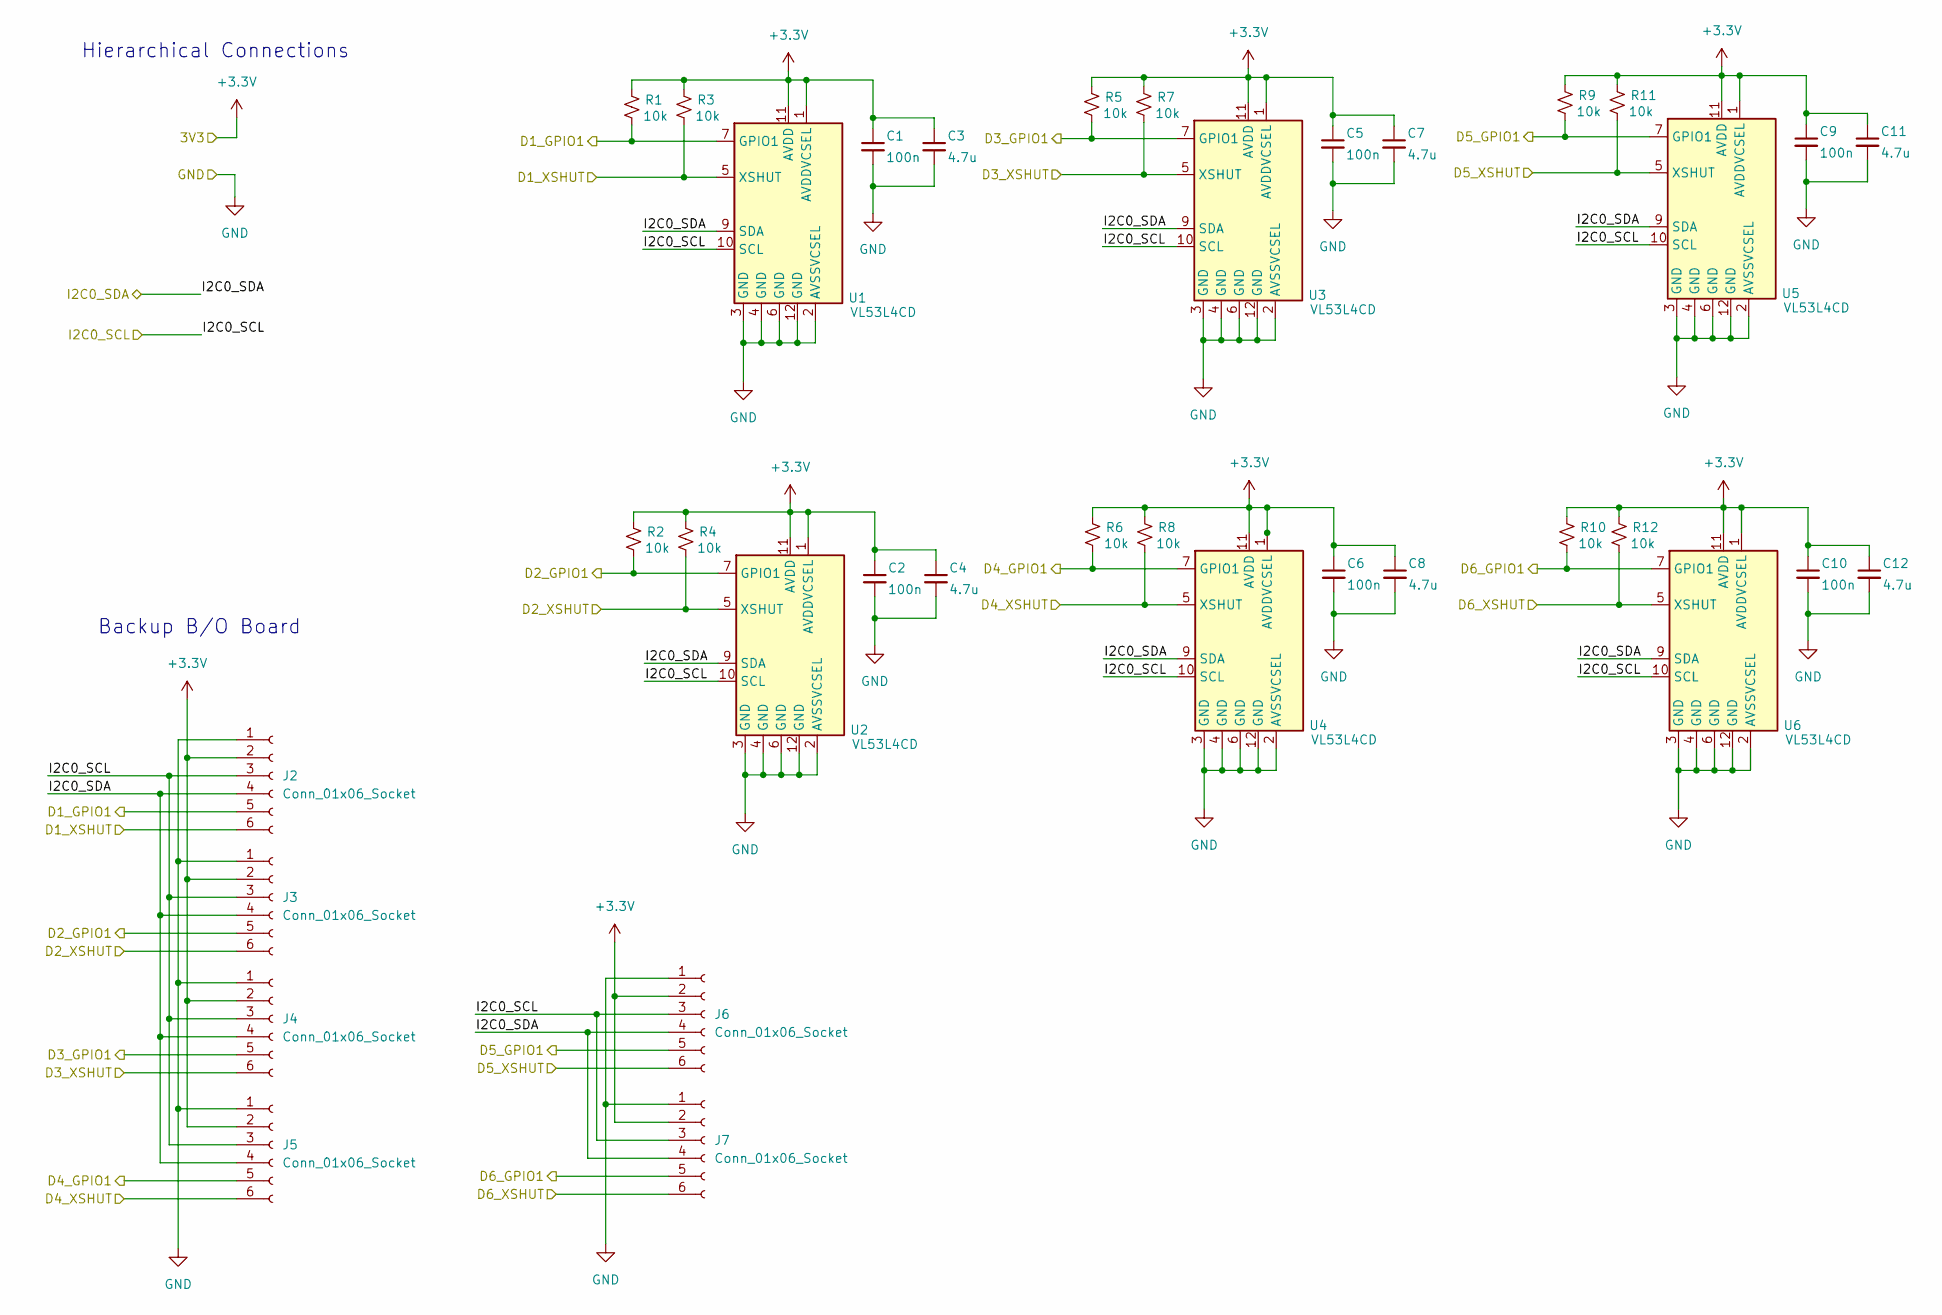
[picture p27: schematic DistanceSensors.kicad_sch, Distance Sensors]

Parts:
C1, C2, C5, C6, C9, C10: 100n; C_0603_1608Metric
C3, C4, C7, C8, C11, C12: 4.7u; C_0603_1608Metric
J2, J3, J4, J5, J6, J7: Conn_01x06_Socket; PinSocket_1x06_P2.54mm_Vertical
R1, R2, R3, R4, R5, R6, R7, R8, R9, R10, R11, R12: 10k; R_0603_1608Metric
U1, U2, U3, U4, U5, U6: VL53L4CD; ST_VL53L1x

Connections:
+3.3V: C1.1, C2.1, C3.1, C4.1, C5.1, C6.1, C7.1, C8.1, C9.1, C10.1, C11.1, C12.1, J2.2, J3.2, J4.2, J5.2, J6.2, J7.2, R1.1, R2.1, R3.1, R4.1, R5.1, R6.1, R7.1, R8.1, R9.1, R10.1, R11.1, R12.1, U1.1 (AVDDVCSEL), U1.11 (AVDD), U2.1 (AVDDVCSEL), U2.11 (AVDD), U3.1 (AVDDVCSEL), U3.11 (AVDD), U4.1 (AVDDVCSEL), U4.11 (AVDD), U5.1 (AVDDVCSEL), U5.11 (AVDD), U6.1 (AVDDVCSEL), U6.11 (AVDD); also elsewhere on the board
/Distance Sensors/D1_GPIO1: J2.5, R1.2, U1.7 (GPIO1); also elsewhere on the board
/Distance Sensors/D1_XSHUT: J2.6, R3.2, U1.5 (XSHUT); also elsewhere on the board
/Distance Sensors/D2_GPIO1: J3.5, R2.2, U2.7 (GPIO1); also elsewhere on the board
/Distance Sensors/D2_XSHUT: J3.6, R4.2, U2.5 (XSHUT); also elsewhere on the board
/Distance Sensors/D3_GPIO1: J4.5, R5.2, U3.7 (GPIO1); also elsewhere on the board
/Distance Sensors/D3_XSHUT: J4.6, R7.2, U3.5 (XSHUT); also elsewhere on the board
/Distance Sensors/D4_GPIO1: J5.5, R6.2, U4.7 (GPIO1); also elsewhere on the board
/Distance Sensors/D4_XSHUT: J5.6, R8.2, U4.5 (XSHUT); also elsewhere on the board
/Distance Sensors/D5_GPIO1: J6.5, R9.2, U5.7 (GPIO1); also elsewhere on the board
/Distance Sensors/D5_XSHUT: J6.6, R11.2, U5.5 (XSHUT); also elsewhere on the board
/Distance Sensors/D6_GPIO1: J7.5, R10.2, U6.7 (GPIO1); also elsewhere on the board
/Distance Sensors/D6_XSHUT: J7.6, R12.2, U6.5 (XSHUT); also elsewhere on the board
/I2C0_SCL: J2.4, J3.4, J4.4, J5.4, J6.4, J7.4, U1.9 (SDA), U2.9 (SDA), U3.9 (SDA), U4.9 (SDA), U5.9 (SDA), U6.9 (SDA); also elsewhere on the board
/I2C0_SDA: J2.3, J3.3, J4.3, J5.3, J6.3, J7.3, U1.10 (SCL), U2.10 (SCL), U3.10 (SCL), U4.10 (SCL), U5.10 (SCL), U6.10 (SCL); also elsewhere on the board
GND: C1.2, C2.2, C3.2, C4.2, C5.2, C6.2, C7.2, C8.2, C9.2, C10.2, C11.2, C12.2, J2.1, J3.1, J4.1, J5.1, J6.1, J7.1, U1.2 (AVSSVCSEL), U1.3 (GND), U1.4 (GND), U1.6 (GND), U1.12 (GND), U2.2 (AVSSVCSEL), U2.3 (GND), U2.4 (GND), U2.6 (GND), U2.12 (GND), U3.2 (AVSSVCSEL), U3.3 (GND), U3.4 (GND), U3.6 (GND), U3.12 (GND), U4.2 (AVSSVCSEL), U4.3 (GND), U4.4 (GND), U4.6 (GND), U4.12 (GND), U5.2 (AVSSVCSEL), U5.3 (GND), U5.4 (GND), U5.6 (GND), U5.12 (GND), U6.2 (AVSSVCSEL), U6.3 (GND), U6.4 (GND), U6.6 (GND), U6.12 (GND); also elsewhere on the board

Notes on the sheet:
Backup B/O Board
Hierarchical Connections

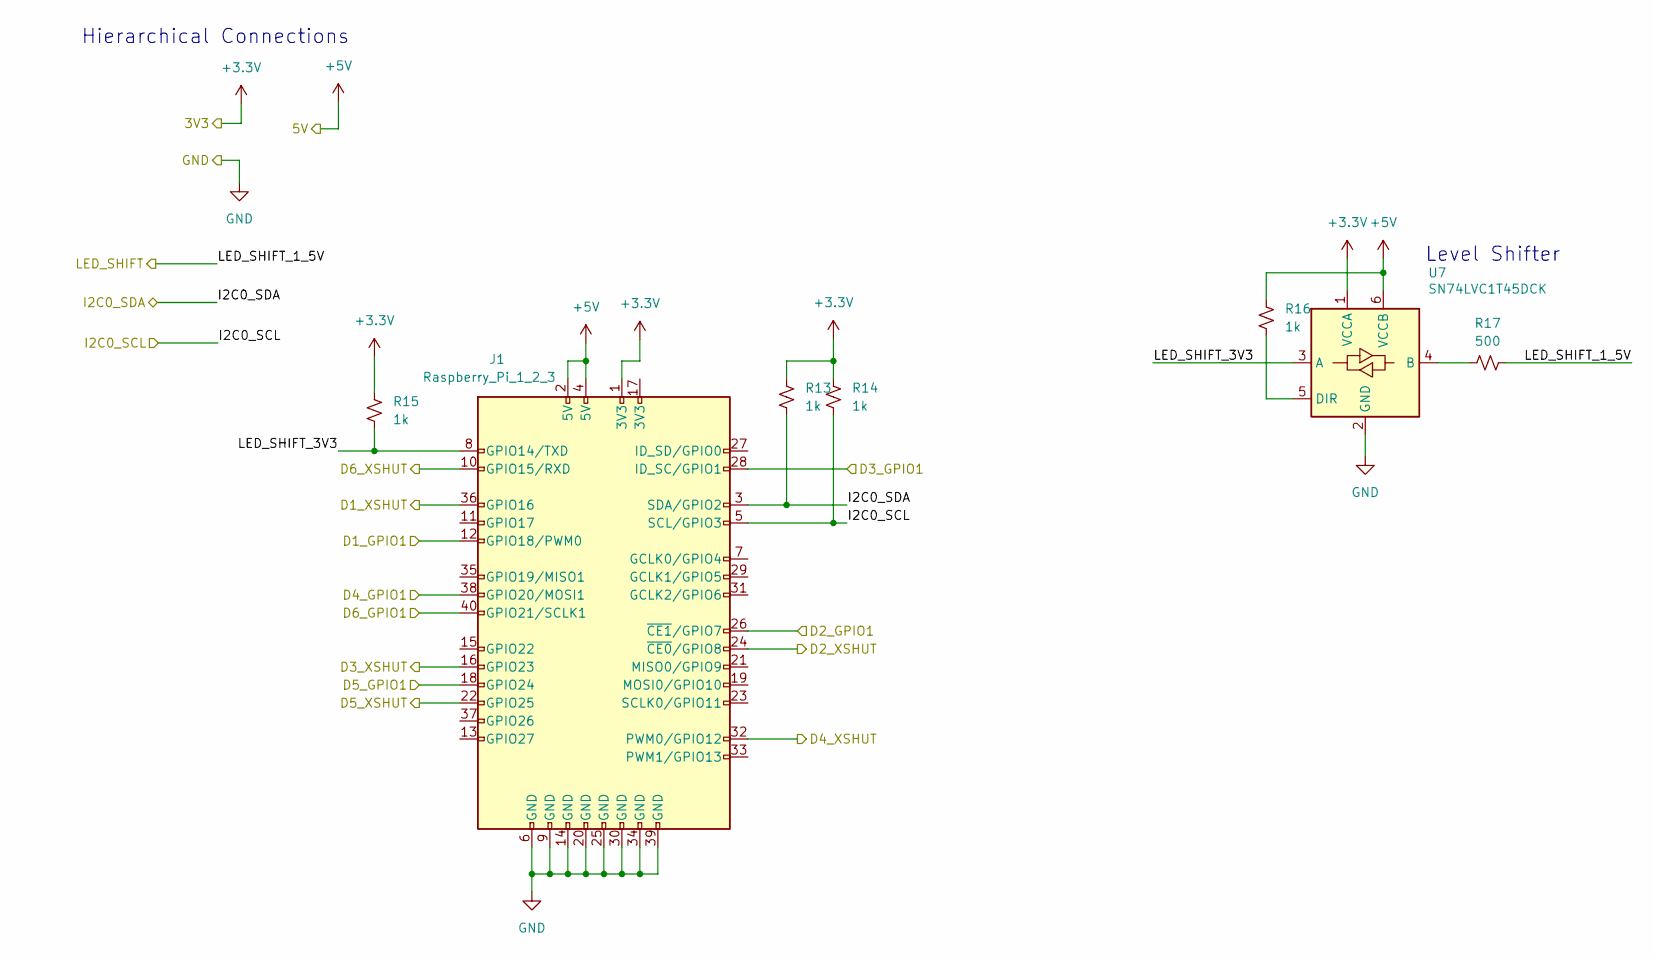
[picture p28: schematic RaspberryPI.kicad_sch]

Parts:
J1: Raspberry_Pi_1_2_3; PinSocket_2x20_P2.54mm_Vertical
R13, R14, R15, R16: 1k; R_0603_1608Metric
R17: 500; R_0603_1608Metric
U7: SN74LVC1T45DCK; SOT-363_SC-70-6

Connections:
+3.3V: J1.1 (3V3), R13.1, R14.1, R15.1, U7.1 (VCCA); also elsewhere on the board
+5V: J1.2 (5V), J1.4 (5V), R16.1, U7.6 (VCCB); also elsewhere on the board
/Distance Sensors/D1_GPIO1: J1.12 (GPIO18/PWM0); also elsewhere on the board
/Distance Sensors/D1_XSHUT: J1.36 (GPIO16); also elsewhere on the board
/Distance Sensors/D2_GPIO1: J1.26 (~CE1/GPIO7); also elsewhere on the board
/Distance Sensors/D2_XSHUT: J1.24 (~CE0/GPIO8); also elsewhere on the board
/Distance Sensors/D3_GPIO1: J1.28 (ID_SC/GPIO1); also elsewhere on the board
/Distance Sensors/D3_XSHUT: J1.16 (GPIO23); also elsewhere on the board
/Distance Sensors/D4_GPIO1: J1.38 (GPIO20/MOSI1); also elsewhere on the board
/Distance Sensors/D4_XSHUT: J1.32 (PWM0/GPIO12); also elsewhere on the board
/Distance Sensors/D5_GPIO1: J1.18 (GPIO24); also elsewhere on the board
/Distance Sensors/D5_XSHUT: J1.22 (GPIO25); also elsewhere on the board
/Distance Sensors/D6_GPIO1: J1.40 (GPIO21/SCLK1); also elsewhere on the board
/Distance Sensors/D6_XSHUT: J1.10 (GPIO15/RXD); also elsewhere on the board
/I2C0_SCL: J1.3 (SDA/GPIO2), R13.2; also elsewhere on the board
/I2C0_SDA: J1.5 (SCL/GPIO3), R14.2; also elsewhere on the board
/LEDs/LED_SHIFT_1_5V: R17.2; also elsewhere on the board
/Raspberry PI/LED_SHIFT_3V3: J1.8 (GPIO14/TXD), R15.2, U7.3 (A)
GND: J1.6 (GND), J1.9 (GND), J1.14 (GND), J1.20 (GND), J1.25 (GND), J1.30 (GND), J1.34 (GND), J1.39 (GND), U7.2 (GND); also elsewhere on the board
unnamed: R17.1, U7.4 (B)
unnamed: R16.2, U7.5 (DIR)

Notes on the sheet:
Hierarchical Connections
Level Shifter

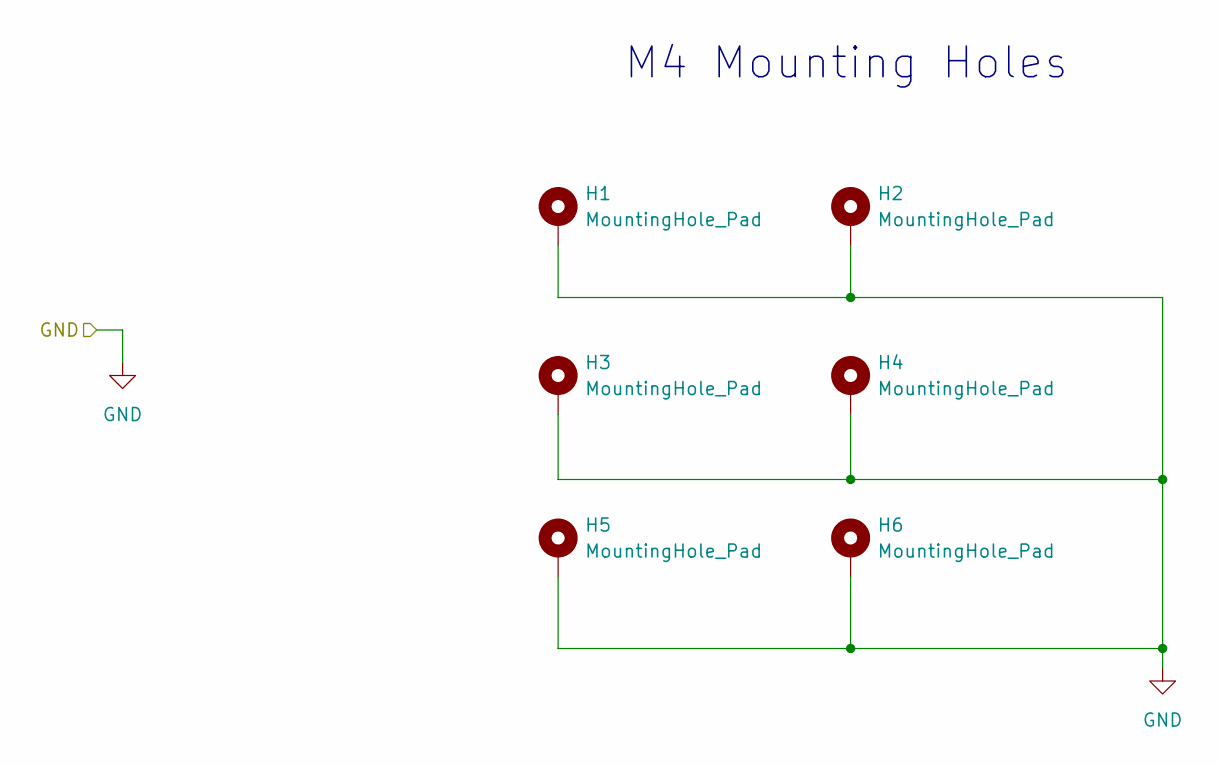
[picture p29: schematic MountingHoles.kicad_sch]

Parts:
H1, H2, H3, H4, H5, H6: MountingHole_Pad; MountingHole_4.3mm_M4_DIN965_Pad_TopBottom

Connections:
GND: H1.1, H2.1, H3.1, H4.1, H5.1, H6.1; also elsewhere on the board

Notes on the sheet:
M4 Mounting Holes

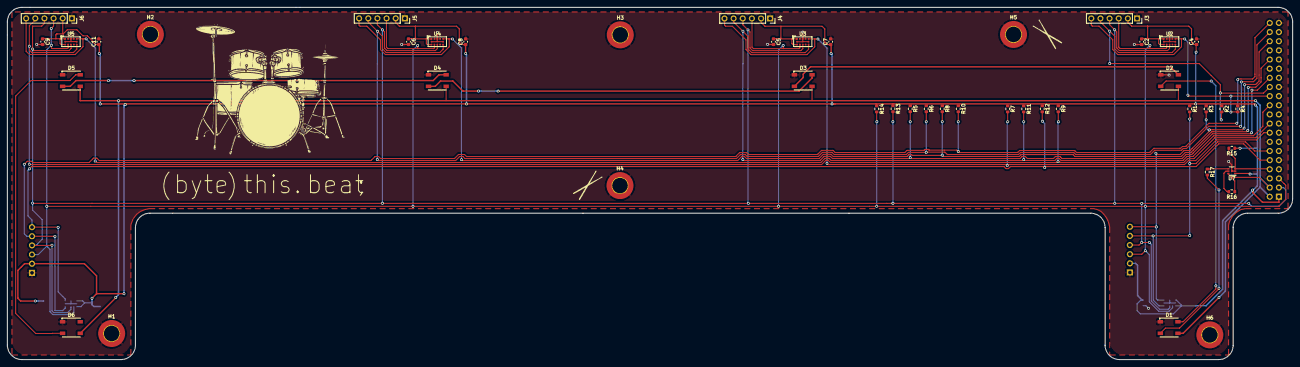
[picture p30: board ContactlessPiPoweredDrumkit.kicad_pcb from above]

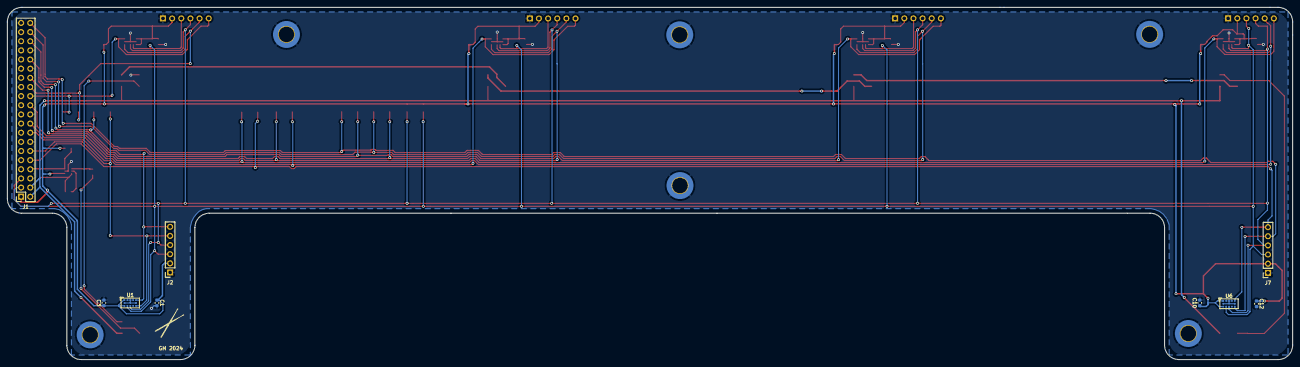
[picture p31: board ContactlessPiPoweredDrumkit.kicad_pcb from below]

Board: 2 copper layers, 356.9 x 97.8 mm, 55 parts (9 on the bottom side), 26 nets.

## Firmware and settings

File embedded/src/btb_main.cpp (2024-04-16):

/****************************** Module Header ******************************\
Module Name:    btb_main.cpp
Project:        btb
Author:         Grant Maiden
Description:    Entry Point into ENG5220 project for University of Glasgow
\***************************************************************************/

#include <stdlib.h>
#include <string.h>
#include <stdio.h>
#include <unistd.h>
#include <pigpio.h>

#include "btb_main.h"
#include "gpio_controller.h"
#include "defines.h"
#include "led.h"
#include "ranging.h"
#include "controller.h"
#include "sound.h"

// global variables
bool enableLedSM = false;
bool enableControllerSM = false;

volatile int sens1DataReady = 0;
volatile int sens2DataReady = 0;
volatile int sens3DataReady = 0;
volatile int sens4DataReady = 0;
volatile int sens5DataReady = 0;
volatile int sens6DataReady = 0;

/**********************************************\
Class Name:     VL53L4CD_test
Description:    Test class used for input test command line processing
/**********************************************/
class VL53L4CD_test : public VL53L4CD
{
    virtual void distanceDataReady(sensorValues sensVals, sensorID sensor)
    {
        printf("Data Received from Sensor: %i. Current Distance: %i \n",sensor + 1, sensVals.currentDistance_mm);
    }
};

VL53L4CD_test    vl53l4cd;

/**********************************************\
Function Name:  main
Input Args:     none
Output Args:    none
Description:    main function/application entry
/**********************************************/
int main(int argc, char *argv[])
{
	//// Parse Unit Tests and Other Command Line Args ////
	parseCommandLine(argc, argv);

    GpioController gpiocontroller;
    gpiocontroller.gpioInitializeLib();

    // initialize Controller, which handles the start of sensor ranging and led control.
    Controller controller;
    controller.initialize();

    printf("Press ctrl+z to end the BTB program\n");
    while(1)
    {
    }

}


/**********************************************\
Function Name:  parseCommandLine()
Input Args:     int argc        arguement count
                char *argv[]    arguement values
Output Args:    none
Description:    Parses Command line arguements. Command line inputs are used primarily for unit tests.
/**********************************************/
void parseCommandLine(int argc,char *argv[])
{
    if (argc > 1)
    {
        printf("Found %i additional input arguments\n\n", argc-1);
        for(int i=1; i<argc; i++)
        {
            printf("Attempting to run Command: %s\n", argv[i]);
            runCommandLine(&argv[i]);
        }
        exit(0);
    }
}

/**********************************************\
Function Name:  runCommandLine()
Input Args:     string arg   arguement values
Output Args:    none
Description:    Runs Command Line arguements
/**********************************************/
void runCommandLine(char *argv[])
{
    if(!strcmp(argv[0], "gpioTest"))
    {
        GpioController gpiocontroller;
        gpiocontroller.gpioTest(GPIO_TEST_LENGTH_SEC);
    }
    else if (!strcmp(argv[0], "test"))
    {
        printf("Test Argument Received!!\n");
    }
    else if (!strcmp(argv[0], "ledNopAsmTest"))
    {
        GpioController gpiocontroller;
        gpiocontroller.ledNopAsmTest(GPIO_TEST_LENGTH_SEC);
    }
    else if (!strcmp(argv[0], "gpioLedSpiTest"))
    {
        GpioController gpiocontroller;
        LedControl ledControl;
        char * arr = new char[18]();
        ledControl.ledCreateColorArr(arr, LED_COLOR_CYAN_DIM, LED_COLOR_PURPLE_DIM, LED_COLOR_YELLOW_DIM, LED_COLOR_WHITE_DIM, LED_COLOR_BLUE_DIM, LED_COLOR_GREEN_DIM);
        gpiocontroller.gpioLedSpiTest(arr);
    }
    else if (!strcmp(argv[0], "ledInitialiseTest"))
    {
        LedControl ledControl;
        ledControl.ledFadeTest(5, 20);
    }
    else if (!strcmp(argv[0], "interruptTest"))
    {
        GpioController gpiocontroller;
        gpiocontroller.gpioInitializeLib();

        // initialize Distance Sensors
        vl53l4cd.rangingInit();

        while (1)
        {
        }
    }
    else if (!strcmp(argv[0], "soundTest1"))
    {
        Sound sound;
        sound.soundTest1();
    }
    else if (!strcmp(argv[0], "soundTest2"))
    {
        Sound sound;
        sound.soundTest2();
    }
    else if (!strcmp(argv[0], "soundTest3"))
    {
        Sound sound;
        sound.soundTest3();
    }
    else if (!strcmp(argv[0], "rangingTestDistanceSensors"))
    {
        vl53l4cd.rangingTestDistanceSensors();
    }
    else
    {
        printf("Command: %s Failed to run!!!\n", argv[0]);
    }
}

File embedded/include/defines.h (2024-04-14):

/****************************** Module Header ******************************\
Module Name:    defines.h
Project:        btb
Author:         Grant Maiden
Description:    contains user constants, global enums, and structs
\***************************************************************************/
#ifndef DEFINES_H
#define DEFINES_H

// Test defines
#define GPIO_TEST_LENGTH_SEC                10
#define TOTAL_INSTRUMENTS_SOUND_TEST2       3

// Misc
#define DISTANCE_SENSOR_INTERRUPT_TIMEOUT   50
#define BTB_TIMER_1_INTERVAL_NS             2.5*1000000

// Gpio Controller Defines
#define WAIT_10MS       1551000
#define WAIT_5MS        775000
#define WAIT_2MS        310200
#define WAIT_1MS        155100
#define WAIT_100US      15510
#define WAIT_245NS      38
#define WAIT_190NS      29
#define WAIT_50NS       8

// Gpio Defines
#define PI_LOW          0
#define PI_HIGH         1
#define GPIO4           4

#define LED_SHIFT_3V3   14
#define D1_GPIO1        18
#define D1_XSHUT        16
#define D2_GPIO1        22
#define D2_XSHUT        8
#define D3_GPIO1        1
#define D3_XSHUT        23
#define D4_GPIO1        20
#define D4_XSHUT        12
#define D5_GPIO1        24
#define D5_XSHUT        25
#define D6_GPIO1        21
#define D6_XSHUT        15


// Hit Strength Defines
#define HIT_SOFT        5
#define HIT_MID_SOFT    7
#define HIT_MID         9
#define HIT_MID_HARD    11
#define HIT_HARD        13


typedef enum
{
    SENSOR1,
    SENSOR2,
    SENSOR3,
    SENSOR4,
    SENSOR5,
    SENSOR6
}sensorID;

// Structs

/**
 * sensorValues structure contains status and distance value of a sensor
 **/
typedef struct
{
    uint8_t rangeStatus; // range status 0 means data ready.
    uint16_t currentDistance_mm;
    uint16_t lastDistance_mm;
    int currentVelocity;
    int averageVelocity;
}sensorValues;

#endif

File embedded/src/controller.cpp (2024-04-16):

/****************************** Module Header ******************************\
Module Name:    controller.cpp
Project:        btb
Author:         Grant Maiden
Description:    System controller state machine
\***************************************************************************/

#include <stdio.h>
#include <stdlib.h>
#include <string.h>
#include <unistd.h>
#include <pigpio.h>
#include <sys/time.h>
#include <chrono>
#include <iostream>

#include "defines.h"
#include "ranging.h"
#include "controller.h"
#include "sound.h"
#include "led.h"


Sound soundController;
LedControl ledController;

/**********************************************\
Function Name:  initialize
Input Args:     none
Output Args:    void
Description:    initialize controller globals and states
/**********************************************/
void Controller::initialize()
{
    currentState = RESET;
    nextState = currentState;
    averageVelNextArrIndex = 0;
    enableSounds = false;
    soundController.soundInit();

    gesture_detected_sensor5 = false;
    gesture_detected_sensor4 = false;
    gesture_detected_sensor3 = false;
    gesture_detected_sensor2 = false;

    timeoutEndTimeSensor1 = 0;
    timeoutEndTimeSensor2 = 0;
    timeoutEndTimeSensor3 = 0;
    timeoutEndTimeSensor4 = 0;
    timeoutEndTimeSensor5 = 0;
    timeoutEndTimeSensor6 = 0;

    hitDetectedRecently = false;

    stopTimeGesture = 0;

    rangingInit();
}

/**********************************************\
Function Name:  updateState
Input Args:     none
Output Args:    void
Description:    update controller state
/**********************************************/
void Controller::updateState(controllerState newState)
{
    nextState = newState;
}

/**********************************************\
Function Name:  primaryStateMachine
Input Args:     none
Output Args:    void
Description:    Controller State Machine. Handles all system states, inputs, and outputs.
/**********************************************/
void Controller::primaryStateMachine()
{
    // Update current state from nextState
    currentState = nextState;
    switch(currentState)
    {
        case RESET:
            initialize();
            nextState = WAIT1;
            break;
        case WAIT1:
            //if(ledGetCurrentState() == MAINSTATE) // TODO: IMPLEMENT FUNTION AND CORRECT STATE NAME
            {
                nextState = POLLING1;
                //soundPlay(introSound); // TODO: implement Soundplay function
            }
            break;
        case POLLING1:
            if(sensorsReady())
            {
                velocityCalc();
                //printSensorAvgVelocity();
                if(enableSounds)
                {
                    if(hitDetection())
                        hitDetectedRecently = true;
                }
                updateDistance();
                if (gestureDetect())
                {
                    enableSounds = !enableSounds;
                    if (enableSounds)
                        soundController.playSound(PATH_SOUND_ENABLED_WAV);
                    else
                        soundController.playSound(PATH_SOUND_DISABLED_WAV);
                }
            }
            break;
        case TEST_DISTANCE_SENSORS:
            if(sensorsReady())
            {
                velocityCalc();
                updateDistance();
                printSensorCurrentDistance();
            }
            break;
        default:
            nextState = RESET;
            break;
    }
}
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

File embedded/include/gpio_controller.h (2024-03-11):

/****************************** Module Header ******************************\
Module Name:    gpio_controller.h
Project:        btb
Author:         Grant Maiden
Description:    Header file for gpio_control.cpp
\***************************************************************************/

/*  Some notes:
    Core Clock frequency is used to divide into SPI clock frequency.
    To find Core clock frequency, run in console:

    vcgencmd get_config int

    Then search for core_freq parameter.
*/
#ifndef GPIO_CONTROLLER_H
#define GPIO_CONTROLLER_H


#include <stdio.h>
#include <stdlib.h>
#include <string.h>
#include <unistd.h>
#include <time.h>
#include <math.h>

#include <pigpio.h>

#include "led.h"
#include "defines.h"




#define LED_SEND_REPEATED_SPI       0
#define SPI_LED_BUF_LENGTH          344
#define SPI_LED_BUF_COLOR_INDEX     200
#define SPI_FLAGS                   0b000000000001100000000000011100000
#define SPI_FREQ                    6500000
#define SPI_CHANNEL                 0
#define LED_OUTPUT_HIGH             0b00001111
#define LED_OUTPUT_LOW              0b00000011

using namespace std;
class GpioController
{
    public:
        /**
         * GPIO Speed test. Toggles GPIO 4 (pin 7) at maximimum speed for user defined seconds.
         * \param seconds- uint number of seconds to run test for
         * \returns bool- returns true if completed successfully or false if error occured.
         **/
        bool gpioTest(uint seconds);

        /**
         * initialize PiGpio Library
         * \returns int- PiGpio library version
         **/
        int gpioInitializeLib(void);

        /**
         * Sets Output level of GPIO
         * \param GPIOnumber- gpio number that is being modified.
         * \param logicLevel- 0 or 1.
         * \returns int- PiGpio success or failure
         **/
        int gpioSetOutput(int GPIOnumber, int logicLevel);

        /**
         * Spew '1010' pattern to Leds using asm nop for delay
         * \param seconds- uint number of seconds to run test for
         * \returns bool- returns true if completed successfully or false if error occured.
         **/
        bool ledNopAsmTest(uint seconds);


        /**
         * Test command- sets led to RGB brightness level via SPI interface
         * \param array- char array 144 bits to be programmed to Leds
         * \returns bool- returns true if completed successfully or false if error occured.
         **/
        bool gpioLedSpiTest(char *arr);

        /**
         * Sets Led Color Array to input 144bits (18bytes). Led<->Byte Order D1-D2-D3-D4-D5-D6
         * \param array- char array 144 bits to be programmed to Leds
         * \returns bool- returns true if completed successfully or false if error occured.
         **/
        void gpioLedSetColor(char *arr);
    private:
        // Spi Globals
        char * spiLedBuf = new char[SPI_LED_BUF_LENGTH]();
        int spiHandle;

        /**
         * Sends Spi Data at Baudrate required for leds.
         * \param buf- char *buf pointer to char buffer that contains spi data
         * \param length - unsigned length of data
         * \param repeatSendData - int send same message multiple times (for redundancy and correct errors)
         * \returns bool- returns true if completed successfully or false if error occured.
         **/
        int gpioSpiSendData(char *buf, unsigned length, int repeatSendData = LED_SEND_REPEATED_SPI);


};


#endif // GPIO_CONTROLLER_H

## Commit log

2024-01-21 Initial Commit Schematic
    [BOM.ods, ContactlessPiPoweredDrumkit.kicad_pcb, ContactlessPiPoweredDrumkit.kicad_sch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]
2024-01-21 Add Datasheet for Distance Sensor
2024-01-21 Add Hierarchical Connections and Distance Sensors
    [ContactlessPiPoweredDrumkit.kicad_sch, DistanceSensors.kicad_sch, LEDs.kicad_sch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]
2024-01-21 Bom Updates
    [BOM.ods]
2024-01-21 Update Hierarchy Page
    [ContactlessPiPoweredDrumkit.kicad_sch, LEDs.kicad_sch, Power.kicad_sch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]
2024-02-05 Complete PCB Layout
    Completed PCB layout
    Custom Artwork
    Generate Gerbers
    [ContactlessPiPoweredDrumkit-B_Cu.gbr, ContactlessPiPoweredDrumkit-B_Mask.gbr, ContactlessPiPoweredDrumkit-B_Paste.gbr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]
2024-02-05 Commit missed items
    Missed a few items
    [ContactlessPiPoweredDrumkit.kicad_pcb, DistanceSensors.kicad_sch]
2024-02-05 Create Schematic PDF
    Created Schematic PDF
2024-02-05 Create BOM
    Create BOM
    Modify Directory Structure
    [BOM.ods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]
2024-02-05 Reviewed PCB DRC
    Reduced constraint size from .3mm to .25mm
    Move pullup resistors slightly
    [ContactlessPiPoweredDrumkit-B_Cu.gbr, ContactlessPiPoweredDrumkit-B_Mask.gbr, ContactlessPiPoweredDrumkit-B_Paste.gbr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]
2024-02-06 Updated Manufacturing Zip
    Zip updates, change drill constraints
2024-02-06 Correct Silkscreen/Update SCH
    correct silkscreen and update schematic
    [ContactlessPiPoweredDrumkit-B_Cu.gbr, ContactlessPiPoweredDrumkit-B_Mask.gbr, ContactlessPiPoweredDrumkit-B_Paste.gbr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]
2024-02-08 Board Build modifications
    Move traces slightly further from board edge.
    Create seperate BOM and placement file for JCLPCB
    [ContactlessPiPoweredDrumkit-B_Cu.gbr, ContactlessPiPoweredDrumkit-B_Mask.gbr, ContactlessPiPoweredDrumkit-B_Paste.gbr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]
2024-02-15 Upload Linux Kernal for Distance Sensor
2024-02-17 Embedded Project Initialization
    Configure Codeblocks
    Include I2C example
    Format Directory
    Update Readme Markdown
2024-02-18 Add i2c enable steps to readme
    modify readme to help team members setup their pi's correctly
2024-02-22 Add GPIO library
    Update main function to have a GPIO test, and give an example of how to shutdown distance sensors, leaving one enabled.
2024-02-22 Update defines.h
    Add LED_SHIFT_3V3
2024-02-24 Add SPI led control
    Add LED control over spi
    Add test commands
    Add LED library and color defines
2024-02-25 SPI Improvements
    Simplify Changes colors to one function call
    Add defines for more colors
    Remove antiquated files and directories
2024-02-26 Change Spi defines
    Spi board rework does not need repeated SPI.
    [gpio_controller.cpp, gpio_controller.h]
2024-02-26 Change SPI back to 200us reset
    [btb_main.cpp, defines.h, gpio_controller.cpp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]
2024-02-26 Add GPIO interrupts for Distance Sensors
    Add GPIO interrupts.
    Interrupt function callback needs to be moved to ranging.cpp @LucasZehner
2024-02-28 Change SPI timing slightly
2024-02-28 Setup for the ranging sensor unit test
    Added:
    Sensor GpIO logic selection, ChangeAddress, StartRanging
2024-02-28 Sensor initialisation
    Successfully initialised sensors 2-5.
    New 'Dev_t' global object for each sensor.
2024-02-28 LED Control changes
    extra initialisation cases
2024-02-28 Updated Initialise LEDs
    fixed timing issues with final states of state-machine
    [led.cpp, led.h]
2024-03-02 Add Thread and Timer Callbacks
    Add Thread and Timer Callbacks.
    Add interruptTest unitTest.
    Purge btb_main.cpp/h of distance sensor functions
2024-03-03 controller updates and Doxygen
    Create controller State machine
    Add functions for hit detection, velocity calculations, and updating sensorValues
    Add defines, structs, and enums to defines.h to help move sensor data between modules
    Add Doxygen file
2024-03-04 Init
    Imported various CAD models, initial sketch (very basic)
    [Raspberry Pi 4 bottom case.step, Raspberry Pi Top Case.step]
2024-03-04 Ranging functions
    Attempted (and failed) simultaneous ranging test.
    Added interrupt-called single-sensor range poll function.
    [ranging.cpp]
2024-03-05 functions added to clean up code + state machine started for main function LED feedback
2024-03-05 some fixes to previous commit
    [led.cpp, led.h]
2024-03-06 Sound Functional
    Incorporate "miniAudio" library into our project.
    More setup required, refer to readme.md
    Fix some warnings
    Add unit tests for soundTest1, soundTest2, soundTest3
    Update CMake to work with miniAudio library
    Delete unused test directory and examples directory.
    [btb_main.cpp, controller.cpp, controller.h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]
2024-03-06 Fix some merging issues
    [controller.cpp]
2024-03-06 Ranging test functional.
    Need to port to all sensors simultaneously
2024-03-06 Add interrupt based Polling test
2024-03-08 Board Rework Changes
    Add Sections to Readme
    Add Acceleration print out
    Tweak Hit Detection Algorithm
    [VL53L4CD_api.c, btb_main.cpp, controller.cpp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]
2024-03-08 Drum Detect improvements
    Add Noise filtering to Drum detection.
    Many different Parameters available for adjustment in controller.h
    [controller.cpp, controller.h]
2024-03-09 Created More Hit Detection Filters
    Additional algorithms
    Monitoring Number of average velocity vectors.
    Helps get rid of hand-over-sensor false detections
2024-03-09 updated LED Branch
2024-03-10 WIP Setup Led State Machine
    Initial setup for a proper LED state machine. There is little in here as I am hungry and need to eat. More to come
2024-03-11 Add Sounds to project
    soundTest3 is now defined.
    Sounds are enabled in project.
    Logic has been added to attach sounds to drums
2024-03-13 LED StateMachine Progress Update
    Implementing LED state machine and working on helper functions.
2024-03-13 LED State Machine Update
    LED state machine has been updated with all necessary functions and logic to operate nominally. (needs to be tested after merge)
2024-03-13 Fixing Initial Merge Issues
    Main merge issues have arisen from the implementation of classes. Most of the errors have been fixed, ledControl object not being passed to controller.cpp is the main issue atm.
    Gtg home am hungry :P
    [btb_main.cpp, controller.cpp, led.cpp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]
2024-03-15 LED State Machine Updates
    Updates on LED SM
2024-03-16 LEDs Now Fully Functional
    Issue on my side where the LEDs will flicker when: Typing, moving mouse, printing to console. There is probably more as well. This only happens while the code runs. Additionally, sensor average velocity is not ideal for drumming mode. An argument to have fixed brightness lights (dim) on at all times may also be better, just for a more relaxed user feedback,
    [btb_main.cpp, controller.cpp, gpio_controller.cpp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]
2024-03-20 Latest update
    Added place for fan, LED holes
    [Base.step, Lid.step, M3 Nut.stp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]
2024-03-20 LED New Dynamic Range
    Added new logic for led operation as well has 5 light levels depending on hit strength. Hit strength thresholds have been moved from the controller.h to defines.h so that both classes may access them.
    sendSound function also updated to accomodate for the epic upcoming uncharted dynamic sounds
2024-03-20 LEDs + More Sound
    Implemented the professional sounds made by Peter
2024-04-15 LED Cleanup
    Moved Defines to h file
2024-04-15 Added LED Unit Tests to txt
2024-04-16 Undo Merge that broke entire project
    [btb_main.cpp, controller.cpp, controller.h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]
2024-04-16 Modify STM32 library into classes. Add virtual callbacks
